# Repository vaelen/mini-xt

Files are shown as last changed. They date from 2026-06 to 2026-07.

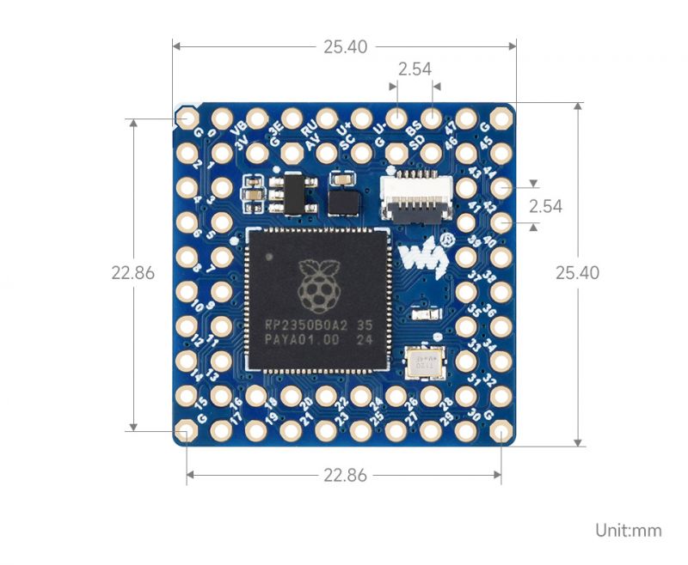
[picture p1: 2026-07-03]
hardware/Core2350B0-details-size.jpg

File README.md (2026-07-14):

# mini-xt

A from-scratch, IBM XT-compatible single-board computer, built as a set of small
PCBs around a real **NEC V20** CPU with modern **Raspberry Pi RP2350B / RP2040**
microcontrollers standing in for the out-of-production Intel 8000-series support
chips. After the substitutions, the only irreplaceable vintage silicon left on
the board is the V20 itself.

## The idea

The buffered **8-bit XT/ISA bus is the integration contract**. The V20 plus
minimal 74HCT glue creates a real XT bus; every other function hangs off it
either as a real chip (16C550 UARTs, XT-IDE + CompactFlash) or as
an MCU **"soft card"** that talks the bus exactly as a period ISA card would.
Since the 3.3V single-board redesign the internal bus is 3.3V end-to-end, so a
soft card's MCU sits on it directly (no per-card level shifters); real 5V ISA
cards attach only through the buffered expansion port. Soft cards may use *only*
signals that exist on the ISA bus, which keeps each one independently
developable and liftable onto a standalone ISA card unchanged.

The "motherboard" itself is a **two-MCU chipset** split by timing domain:

| Node | Part | Role |
|---|---|---|
| Bus MCU ("fast hands")  | RP2350B | Soft PIC/PIT/KBC/DMA/NMI/POST; bus slave *and* bus master |
| Supervisor ("slow brain")| RP2040 | USB HID host, setup UI, config, BIOS image storage, console |
| Video | RP2350B | Soft CGA/MDA/Hercules, snoop-and-mirror → VGA + HDMI |
| Audio | RP2040  | On-board PicoGUS (stock firmware): AdLib/SB/GUS/MPU + joystick |

There is no BIOS ROM: the Bus MCU shadow-loads the BIOS (Xi 8088, forked) into
SRAM at boot from images the Supervisor holds in flash, then releases the V20's
reset. RAM is one IS62WV51216BLL SRAM (512K×16, wired 1M×8 via the byte-lane
trick: 1 MB conventional + UMB less the video window); video RAM lives inside
the video MCU.

## Repository layout

| Path | Contents |
|---|---|
| `docs/xt-mcu-sbc-design.md` | **The main design doc** — the MCU-hybrid build implemented here |
| `docs/xt-hardware-design.md` | Companion design: the same machine from period chips (82Cxx, MC6845, CPLD) |
| `docs/early-pc-cpus.md` | Background: 8080→Z80→8086/8088→V20→286→386 lineage |
| `docs/memory-management.md` | Background: segmentation, the 640 KB barrier, EMS/XMS |
| `docs/pc-generations.md` | Background: XT→AT→386 board evolution; why XT-class is the target |
| `hardware/` | KiCad 9 schematics (generated — see below) + `README.md` |
| `hardware/sheets/*.py` | Declarative per-sheet schematic builders (the real sources) |
| `hardware/tools/` | The Python schematic generator (`mxsch.py`), signal contract (`mxbus.py`), build harness |
| `hardware/notes/` | Design decisions + open questions logged during generation |

## The schematics

The `.kicad_sch` files are **generated** by a small purpose-built Python
generator from the builders in `hardware/sheets/` — edit the `.py` files, not
the KiCad files. They are interface-focused: real component symbols, every
inter-module signal exposed as a hierarchical pin, key supporting parts and
decoupling — optimized for seeing module boundaries and how cleanly the
subsystems isolate, not (yet) for a finished PCB.

```sh
kicad hardware/mini-xt.kicad_pro          # browse: root sheet = the ISA backplane
python3 hardware/tools/build.py           # regenerate all sheets + root, run ERC + netlist
```

All peripherals live on the motherboard — one isolated sheet each,
jumper-configured like real cards (enable, base address, IRQ), so any of them
can still be lifted onto a separate PCB later by re-adding a small wrapper
(decode + IRQ driver + the expansion header).
External cards attach through the buffered **expansion port** (`sidecar`
sheet): a 50-pin (2×25) header carrying a project-private 8-bit ISA subset —
50-way IDC ribbons are far easier to source than the 60-way header it replaced.
The long-term plan is an **ISA backplane expansion board** on that port, with
real card-edge slots, that locally re-creates the few signals the 50-pin
header drops (OSC, REFRESH#) for any period card that needs them. (The interim
standalone dev cards — `card_video` and the `card_isatest` jig — were deleted
2026-07-14 in favor of that plan; git history has their last versions.)

See `hardware/README.md` for the sheet list and
`hardware/tools/SHEET_AUTHORING_GUIDE.md` for how to author a sheet.

## The on-board peripherals

The **motherboard** (V20 + SRAM + the two-MCU chipset + power/audio, the
`hardware/sheets/` hierarchy) is the one node allowed private side-channels,
since it *is* the machine the cards plug into. Its on-board peripherals keep
the soft-card discipline (own sheet, ISA signals + power only) and are
jumper-configured like the period cards they replace:

- **Video** — soft CGA/MDA/Hercules on an RP2350B (Core2350B module, 8 MB
  PSRAM variant for the future VGA aperture). Snoop-and-mirror design: it
  owns its video RAM, captures bus writes to `0xA0000–0xBFFFF` and the
  CRTC/mode ports at 0 wait through a PIO FIFO, and serves the (rare) reads
  itself, wait-stated via IOCHRDY — so there is no shared-framebuffer
  arbitration and no CGA snow. Renders once to internal RAM, outputs VGA
  (resistor-ladder DAC) or HDMI (RP2350 HSTX, no transmitter chip); graphics
  scope (CGA → mode 13h → planar VGA) is purely a firmware milestone.
  Boot-read straps stand in for a period card's switches: DIS_VID (addr_decode
  JP5) high = disabled — firmware keeps every bus-facing OE off; JP1 picks the
  default window set, closed = CGA (0x3D4/0xB8000), open = MDA/Hercules
  (0x3B4/0xB0000).
- **COM1/COM2** — one `com_port` sheet instanced twice: 16C550 (SMD PLCC-44
  socket taking new TI silicon or period NS16550AFN pulls) + MAX3241 for a
  full DB9 DTE, 1.8432 MHz crystal baud reference. Per port: J2 base address
  (0x3F8/0x2F8), IRQ hardwired (COM1=IRQ4, COM2=IRQ3), JP3 enable (open parks
  the 16550's CS1 — the port simply never decodes, freeing its IRQ), JP1 RX
  source (DB9 vs 5 V TTL console header, COM1).
- **LPT** — period-correct SPP at JP1-strapped 0x378/0x278 in discrete 74HCT
  ('574 latches, '244 buffers, AND-tree decode); Busy inverted on-card into
  status bit 7, IRQ7 hardwired (tri-state driver, silent until enabled), JP2
  enable gates the register-select '138 (open also frees IRQ7). DB25 out.
- **RTC** — emulated in the Bus MCU (like the PIC/PIT/KBC) at the
  PC-standard 0x70/0x71, NMI mask on 0x70 bit 7. The RTC periodic/alarm IRQ8 is
  emulated in the **soft-PIC** (fired in firmware) — the physical ISA IRQ8 line
  is undriven/reserved, not hardwired. Battery-backed timekeeping comes from a
  **PCF8563 I2C RTC + CR2032** on the Supervisor, synced to the Bus MCU over the
  existing UART link at boot.
- **PicoGUS** — a faithful on-board copy of polpo's PicoGUS 2.0 "chip-down"
  design (CERN-OHL-P): a bare RP2040 running **stock PicoGUS firmware**
  (AdLib/SB/GUS/MPU-401/CMS/Tandy), with the reference's ADS-muxed shared
  AD bus through CB3T FET switches, BUSOE power-up latch, APS6404L sample
  PSRAM, PCM5102A I²S DAC, and DMA hardwired to **channel 1** (the only
  channel the chipset services — the reference's DMA jumper block is
  omitted). The IRQ is hardwired to
  **IRQ5** — the free line, sole driver — with pgusinit setting the
  firmware to match. Deviations, all logged: no gameport (USB HID
  instead), no wavetable header or MIDI-out jack (build simplification —
  the volume chip and mix node went with them; the firmware's volume/MIDI
  GPIOs are documented no-connects), audio feeds the board's one line-out
  jack via the summer, and programming arrives over the Supervisor's shared
  USB-C port (SW2 selector) instead of a local connector.
- **Storage** — a true XT-IDE rev 2 ("Chuck-mod"): the A0↔A3 address-line
  swap puts the data register at 0x300 and the '573 high-byte latch at
  0x301, exactly the layout XTIDE Universal BIOS's "XT-IDE rev 2" type
  boots fastest; the latch pair turns the 16-bit IDE data register into
  two 8-bit transfers. A 40-pin IDE header and a CompactFlash socket
  (True-IDE) hang off the same bus. Straps: JP1 base 0x300/0x320, JP2
  enable (lifts the decode '138 — every select, latch clock and buffer
  goes inert). The IRQ is hardwired to **IRQ14** (AT primary-IDE
  convention, collected on the Bus MCU's '165 D7; motherboard-internal
  line) — poll vs interrupt is an XTIDE UB config choice, and the
  tri-state driver is silent unless the drive asserts INTRQ. No boot ROM
  on the interface: the Bus MCU shadow-loads XTIDE Universal BIOS into
  SRAM at boot.
- **Network** — none on board. The RTL8019AS NE2000 NIC (an ISA8019
  transcription) was removed on 2026-07-14; git tag `full-board-with-nic`
  preserves the complete design. A real NE2000 card on the buffered
  expansion port fills the role if networking is ever needed (its IRQ2
  arrives as EXT_IRQ2 and redirects to IRQ9 in the soft PIC).

Disabling an on-board port (or re-strapping its address/IRQ) frees the slot
for the same peripheral on the expansion port — the drivers are tri-state, so
an on-board port and a card can coexist as long as they don't claim the same
address or IRQ: run the on-board XT-IDE at 0x300 beside a real 8-bit ISA IDE
card at 0x320, or on-board video as CGA beside an MDA card.

## Fabrication

The board is fabricated and assembled at **JLCPCB**: SMD construction (the
merged single-board motherboard is above the ≤100 × 100 mm tier),
with through-hole only for
connectors/headers and for the fab-installed **sockets** that carry the
irreplaceable parts (the V20 and the MCU modules — the SRAM and RTC are now
SMD, no longer socketed). Every schematic component carries an `LCSC Part Num` property —
generated from the sourcing map in `hardware/tools/parts.py` — so the BOM
export drives JLCPCB assembly directly. Sourcing decisions, verified pinouts,
and stock-forced substitutions are logged in
`hardware/notes/jlcpcb-sourcing.md`.

## Status

Schematic capture / architecture-validation stage. Firmware (Bus MCU chipset
emulation, video, Supervisor) and PCB layout have not been started. Open items
are tracked in `hardware/notes/open-questions.md` and
`docs/xt-mcu-sbc-design.md` §16.

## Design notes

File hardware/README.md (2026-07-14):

# mini-xt — KiCad schematics

Hierarchical KiCad 9 schematics for the XT-class MCU-SBC described in
`../docs/xt-mcu-sbc-design.md`. Interface-focused: real component symbols, every
inter-module signal exposed as a hierarchical pin, key supporting parts and
decoupling — optimized for seeing the module boundaries and how cleanly the
subsystems isolate, not for a finished PCB.

## Open it

```
kicad mini-xt.kicad_pro      # then open mini-xt.kicad_sch (the root sheet)
```

The root sheet is the buffered ISA backplane; double-click any sheet symbol to
descend into a subsystem.

## Layout

| File | Subsystem |
|---|---|
| `mini-xt.kicad_sch` | root — 3.3V ISA backplane + sheet instances + power |
| `sheets/cpu_core` | V20 CPU, SRAM, clock tree, reset, the board's one 5V↔3.3V boundary |
| `sheets/bus_mcu` | Bus-master RP2350B: soft chipset (incl. RTC ports 0x70/71) + addr counter + IRQ collector, GPIOs direct on the 3.3V bus (no local level shifters) |
| `sheets/supervisor` | RP2040: USB host, setup UI, POST, console, link, battery-backed PCF8563 RTC |
| `sheets/video` | RP2350B soft CGA/MDA/Herc → HDMI + VGA; 4× 74LVC245A PIO time-share mux |
| `sheets/com_port` | 2× TL16C550CPFBR + MAX3241 + DB9 (COM1+COM2) |
| `sheets/addr_decode` | central I/O decode + IRQ mapping + the 2×5 disable-jumper block JP1 (bases hardwired) |
| `sheets/parallel` | discrete 74HC/74LVC LPT @ 0x378 + DB25 |
| `sheets/power` | USB-C 5 V in → 3.3 V buck |
| `sheets/storage` | XT-IDE (Chuck-mod) + CompactFlash |
| `sheets/audio` | PC-speaker + op-amp summer → line-out |
| `sheets/sidecar` | buffered 5V-compatible ISA expansion port: 50-pin (2×25) header + ~7-package isolation bank, incl. one DMA channel (EXT_DRQ / EXT_DACK̄) |
| `sheets/picogus` | PicoGUS chip-down copy: RP2040 AdLib/SB/GUS/MPU  |
| `mini-xt.kicad_sym` | custom symbols (V20, MAX3241, IS62WV51216, TL16C550PT, PCF8563, flat 74xx)|

There is no `sheets/rtc` any more — the RTC is emulated in the Bus MCU
(ports 0x70/0x71) with battery-backed timekeeping on the Supervisor
(PCF8563 + CR2032); see `notes/open-questions.md`'s 2026-07-14 entry.
There is no `sheets/network` any more either — the RTL8019AS NE2000 NIC was
removed 2026-07-14 (git tag `full-board-with-nic` has the last design that
carried it); a real NE2000 card on the expansion port fills the role.
The standalone dev cards (`sheets/card_video`, `sheets/card_isatest`) and
`hardware/cards/` were deleted 2026-07-14 too — the long-term plan is an ISA
backplane expansion board on the sidecar port; git history has their last
versions.

## How these were generated

The `.kicad_sch` files are emitted by a small Python generator in `tools/`
(`mxsch.py`) from declarative per-sheet builders (`sheets/*.py`). To regenerate:

```
python3 tools/build.py                       # writes all sheets + root, runs ERC + netlist
python3 tools/validate_sheet.py <name>       # ERC one sheet in isolation
python3 tools/pins.py <Lib:Name>             # introspect a symbol's pins
```

To author or change a sheet, edit `sheets/<name>.py` and re-run `build.py`.
See `tools/SHEET_AUTHORING_GUIDE.md`.

## Fabrication (JLCPCB)

Every component carries an `LCSC Part Num` property, generated at build time
from the sourcing map in `tools/parts.py` (SMD parts; the motherboard is one
>100×100 mm board since the 2026-07-14 3.3V single-board redesign;
fab-installed sockets are down to the V20 + the Core2350B/Pico module
headers). The sheets
stay generic; the parts map is the single place where generic symbols bind to
purchasable parts. Decisions, verified pinouts, and stock-forced
substitutions: `notes/jlcpcb-sourcing.md`.

## Notes / decisions

`notes/open-questions.md` records the decisions made during generation and the
items to review; `notes/questions-<sheet>.md` hold per-sheet specifics.

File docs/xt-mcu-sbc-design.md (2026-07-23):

# XT-Class SBC — MCU-Hybrid Design Notes

An **alternate** design for a DOS-compatible, XT-class single-board computer built
around the **NEC V20**, that deliberately **replaces the out-of-production Intel
8000-series support chips with modern microcontrollers** (Raspberry Pi RP2350B /
RP2040) and an on-board **PicoGUS**, while keeping the parts already on hand real.

Where the companion `xt-hardware-design.md` is "distinct period chips, education over
emulation," **this design optimizes for buildability with available parts**: the goal is
to need *as few out-of-production ICs as possible*. After this exercise, **the only
irreplaceable vintage silicon left is the V20 itself.**

See companion docs: `xt-hardware-design.md` (the period-chip build), `early-pc-cpus.md`,
`memory-management.md`, `pc-generations.md`.

Design date: 2026-06-28.

**2026-07-14 update — 3.3V single-board redesign.** The board collapsed onto
**one PCB with a 3.3V internal bus** (was: multiple 5V-bus boards/sidecar
modules). The V20's own address-latch/data-transceiver stage, re-specified as
74LVC parts, *is* now the board's single 5V↔3.3V boundary; a second,
isolation-only buffer bank sits at the external expansion port. Sections below
are updated in place where the redesign changed them (RAM, RTC, COM UART,
voltage architecture, block diagram, §4). Full rationale, decision log, and
verification: `docs/superpowers/specs/2026-07-14-3v3-single-board-design.md`
and `hardware/notes/3v3-verification.md`.

---

## 1. Design summary / decisions locked

| Area | Decision |
|---|---|
| CPU | NEC **V20** (µPD70108, **9 MHz grade**) in **min mode** (no 8087 → no 8288, no 8284) |
| Clock | **Single 14.31818 MHz oscillator** (3.3V part); ÷2 = 7.16 MHz (74LVC74A), ÷3 = 4.77 MHz (74LVC161 preset-to-3) — LVC-grade for 3.3V fmax margin |
| CPU speed | **7.16 MHz** default, **4.77 MHz** turbo-down (selected in the boot menu, CPU held in reset) |
| Reset / power-good | Supervisor (TCM809, 3.3V) cold-start; **Bus MCU sequences reset** |
| Board | **One PCB** (>100×100 mm JLC tier) — the old per-subsystem boards / inter-board 60-pin daisy-chain headers are gone; sheets remain separate *schematic* sheets only |
| RAM | **One IS62WV51216BLL-55TLI** (512K×16, 3.3V, TSOP-II-44) wired **1M×8 via the byte-lane trick** (1 MB conventional+UMB less the video window); video RAM lives in the video MCU |
| ROM / BIOS | **None on board** — BIOS **shadow-loaded into SRAM** by the Bus MCU at boot |
| Bus | **3.3V internal** buffered 8-bit XT/ISA backplane; a **50-pin (2×25) buffered expansion port** (isolation/level-shift bank, `sidecar` sheet) presents a 5V-compatible 8-bit ISA subset header (project-private pinout since 2026-07-14) for real cards |
| Support chipset | **Two-MCU split**: **Bus MCU (RP2350B)** soft-emulates PIC (×2, 15 IRQ), PIT, KBC, **functional DMA**, NMI, POST, and RTC ports 0x70/71, as bus master/slave, GPIOs tied **directly** to the 3.3V bus (no local transceivers); **Supervisor (RP2040)** runs USB/config/storage off-bus plus the battery-backed RTC (§5) |
| Chipset link | **2-wire full-duplex UART** between Bus MCU ↔ Supervisor (boot image push + HID/menu/POST/RTC-sync events) |
| Video | **RP2350B** soft CGA/MDA/Hercules (snoop-and-mirror), **VGA + HDMI** out (config-selected); 4× 74LVC245A kept as a PIO-driven time-share address/data mux (GPIO budget), not level shifters on this 3.3V board |
| Audio | **On-board PicoGUS (bare RP2040 "chip-down" copy, stock firmware)** — AdLib/SB/GUS/MPU/etc.; no gameport (USB HID instead) |
| Network | **None on board** (the RTL8019AS NE2000 NIC was removed 2026-07-14 — git tag `full-board-with-nic` has the last full design); a real NE2000 card can plug into the buffered expansion port |
| Input | **USB-A HID host** on the **Supervisor** MCU (keyboard; mouse via user's hub) |
| Mouse | Emulated **virtual COM3 serial mouse** (default) or **PS/2 on IRQ12** (option) |
| Storage | Discrete **XT-IDE** (8-bit, Chuck-mod) + CompactFlash; XTIDE Universal BIOS. Floppy = **all-firmware emulation** (§10.1, no FDC hardware) |
| Serial | **2× TL16C550CPFBR** (TQFP-48, soldered, 3.3V — thin JLC stock, C882798) + **MAX3241** (full DB9); TTL console header on COM1 |
| Parallel | Discrete **74HC/74LVC** LPT @ 0x378 (jumpers: 0x278 alt, enable; IRQ7 hardwired) |
| RTC | **Emulated in the Bus MCU** (ports 0x70/0x71, like PIC/PIT); battery-backed timekeeping via a **PCF8563 I2C RTC + CR2032 coin cell on the Supervisor**, synced over the UART link at boot |
| Config | **Pre-BIOS setup menu** (Supervisor MCU), shown on **video + MCU console**, entered by keypress |
| BIOS | **Xi 8088** (Sergey Kiselev), expected to be **forked** for our chipset |
| Debug | **2-digit hex POST display** (port 0x80), MCU console, logic-analyzer header |
| Power | Single **5 V in** (USB-C) → on-board **3.3 V buck** carrying nearly the whole board; no ±12 V. 5V presences that remain: V20; cpu_core U10 (74HCT32 strobe combiner); cpu_core U13 (74HCT04 — V20 CLK + READY/HOLD buffers); the fused +5V_ISA port feed; the audio MCP6002 (analog). MAX3241s are 3.3V |

**MCU count: 2× RP2350B** (Bus MCU, video) **+ 2× RP2040** (Supervisor, PicoGUS).
The chipset is deliberately split across two MCUs (§5) for clean separation: the **Bus MCU**
owns all hard-real-time bus work, the **Supervisor** owns the USB stack, setup UI, and
BIOS-image storage off-bus. The two *we* develop on RP2350B (Bus MCU) and RP2040 (Supervisor)
are independent; PicoGUS stays stock.

---

## 2. Philosophy & architecture

The organizing idea: **the buffered 8-bit XT/ISA bus is the integration contract.**
The V20 plus minimal glue creates a real XT bus on the board; every function then
hangs off it either as a **real chip** (what we already have) or as an **MCU "soft card"**
that talks the bus exactly as a period ISA card would. This makes each subsystem
independently developable, testable, and (for the video and sound cards) **liftable
onto a standalone ISA card later.**

**2026-07-14 update:** the whole internal bus is now 3.3V, so soft cards on the
motherboard tie their MCU GPIOs to it **directly** — no local level shifters —
except the video card's GPIO-budget mux (below). Local shifters remain load-bearing only at
the buffered expansion port (§4.3) and on any card that plugs into it as a real
5V ISA card.

Three classes of node:

1. **The "motherboard" — a two-MCU chipset** (the one special, non-card node). It turns the
   V20 into an XT and is split by timing domain (§5):
   - **Bus MCU (RP2350B) — "fast hands."** All hard-real-time bus work: PIC, PIT, KBC, DMA,
     NMI, POST, RTC ports 0x70/71, the shadow-load engine. A bus *slave* (answers I/O)
     **and** a bus *master* (boot shadow-load, sound DMA, pre-BIOS menu rendering). No
     local transceivers — its GPIOs sit on the 3.3V bus directly and tri-state natively
     for role changes. Touches only the bus, its glue (address counter, IRQ shift
     register), and the link to the Supervisor.
   - **Supervisor (RP2040) — "slow brain."** Off the system bus entirely: USB HID host, setup
     UI, persistent config, BIOS/option-ROM image storage, console, POST display, and the
     battery-backed PCF8563 RTC (synced to the Bus MCU's emulation over the link at boot).
     Talks to the Bus MCU only over a **2-wire full-duplex UART** (§5.3).
2. **Soft cards** — the **video** card (RP2350B) and **PicoGUS** (RP2040). Pure ISA
   peripherals on the bus, GPIOs tied directly to the 3.3V bus (video keeps a 4×
   74LVC245A PIO-driven time-share mux for GPIO budget, not for level shifting).
3. **Real period-style chips** — V20, one IS62WV51216BLL SRAM, 2× TL16C550CPFBR UART,
   plus discrete 74HC/74HCT/74LVC glue for the bus, LPT, and XT-IDE.

**Portability guideline** (downgraded 2026-07-14 from a hard schematic rule — decision
#8 of the 3.3V redesign). A **soft card** (class 2) is still meant to use **only
signals that exist on the ISA bus** — self-decoding its own address ranges, coordinating
solely through standard lines (`MEMR̄/MEMW̄/IOR̄/IOW̄`, `BALE`, `AEN`, `IOCHRDY`, `IRQ`,
`DRQ/DACK/TC`, `CLK`, `RESET`), no dependence on host memory — because that is what keeps
it liftable to a standalone ISA board. But with the whole board now one 3.3V bus, this is
firmware/architectural discipline rather than an electrically-enforced boundary, so it is
a **guideline**, not a binding constraint (`mxbus`'s `PRIV_*` split loosened accordingly).
The **class-1 motherboard MCUs remain explicitly exempt** — they *are* the motherboard: the
Bus MCU bus-masters via `HOLD/HLDA`, sequences reset, and owns motherboard-only signals
(the SRAM-decode Y5 strobe, the speed-select latch, the external address counter), and the
Supervisor never sits on the bus at all. Class-3 parts are fixed motherboard hardware and
out of scope for the rule.

**Central I/O decode + IRQ map (2026-07-14).** The discrete peripherals no longer carry
their own bus-interface plumbing. One **`addr_decode` sheet** (74HC138 windowing on A6-A8
with A9/AEN enables, a 74HC00 building the shared A3·A4·A5 fine term, two 74HC32 ranks)
hands **~COM1_CS / ~COM2_CS / ~LPT_CS / ~IDE_CS** (`mxbus.PRIV_CS`) to the COM/LPT/XT-IDE
sheets, and its shared **74LVC125A** drives the real IRQ lines (COM1→IRQ4, COM2→IRQ3,
LPT→IRQ7, IDE→IRQ14) from the peripherals' private requests (`mxbus.PRIV_IRQREQ`; the COM
channels stay ~OUT2-gated per the PC convention). Base addresses are **hardwired** (LPT 0x378, IDE
0x300 — the straps went the way of COM's, 2026-07-14 later the same day). All five
per-peripheral **disable jumpers JP1–JP5** (COM1, COM2, LPT, IDE, VID — enabled by
default; fit a jumper to disable) live here: COM/LPT/IDE gate their chip selects through
a second '32 rank, while **DIS_VID** (`mxbus.PRIV_DIS`) is just the jumper
level routed to gating that must stay local (the video MCU's firmware boot strap,
polarity inverted vs the old VID_EN). These private nets are
shared logic factored out, not an isolation break: each is functionally equivalent to
the gate chips it replaced, and a block broken out to a standalone card gets decode + IRQ
driver back in its wrapper schematic exactly as it gets the bus edge connector
(`questions-addr_decode.md`). Video/PicoGUS/Bus-MCU decode in firmware; only their
disable jumpers moved here.

**Decode chart.** Net-by-net logic of the `addr_decode` chain (U1 '138 windows → U2 '00
fine term → U3/U4 '32 OR ranks). All nets are active-low; each row shows the A0–A9 state
that asserts the net (X = don't care). Every row also requires **AEN = 0** (the '138's
~E0 — decode is suppressed during DMA cycles), and the final `~x_CS` rows additionally
require the peripheral's **DIS_x jumper level = 0** (enabled, the default).

| Net Name  | Logic | A0 | A1 | A2 | A3 | A4 | A5 | A6 | A7 | A8 | A9 |
|---|---|----|----|----|----|----|----|----|----|----|----|
| WIN_COM1  | NOT(AND(A6, A7, A8, A9, NOT(AEN))) | X  | X  | X  | X  | X  | X  | 1  | 1  | 1  | 1  |
| WIN_COM2  | NOT(AND(A6, A7, NOT(A8), A9, NOT(AEN))) | X  | X  | X  | X  | X  | X  | 1  | 1  | 0  | 1  |
| WIN_LPT | NOT(AND(A6, NOT(A7), A8, A9, NOT(AEN))) | X  | X  | X  | X  | X  | X  | 1  | 0  | 1  | 1  |
| WIN_IDE | NOT(AND(NOT(A6), NOT(A7), A8, A9, NOT(AEN))) | X  | X  | X  | X  | X  | X  | 0  | 0  | 1  | 1  |
| Q_N | NAND(A3, A4, A5) | X  | X  | X  | 1  | 1  | 1  | X  | X  | X  | X  |
| CSP_COM1  | OR(WIN_COM1, Q_N) | X  | X  | X  | 1  | 1  | 1  | 1  | 1  | 1  | 1  |
| CSP_COM2  | OR(WIN_COM2, Q_N) | X  | X  | X  | 1  | 1  | 1  | 1  | 1  | 0  | 1  |
| CSP_LPT | OR(WIN_LPT, Q_N) | X  | X  | X  | 1  | 1  | 1  | 1  | 0  | 1  | 1  |
| CSP_IDE | OR(WIN_IDE, A5) | X  | X  | X  | X  | X  | 0  | 0  | 0  | 1  | 1  |
| ~COM1_CS  | OR(CSP_COM1, DIS_COM1) | X  | X  | X  | 1  | 1  | 1  | 1  | 1  | 1  | 1  |
| ~COM2_CS  | OR(CSP_COM2, DIS_COM2) | X  | X  | X  | 1  | 1  | 1  | 1  | 1  | 0  | 1  |
| ~LPT_CS | OR(CSP_LPT, DIS_LPT) | X  | X  | X  | 1  | 1  | 1  | 1  | 0  | 1  | 1  |
| ~IDE_CS | OR(CSP_IDE, DIS_IDE) | X  | X  | X  | X  | X  | 0  | 0  | 0  | 1  | 1  |

Resulting ranges: ~COM1_CS = 0x3F8–0x3FF, ~COM2_CS = 0x2F8–0x2FF, ~LPT_CS = 0x378–0x37F,
~IDE_CS = 0x300–0x31F. A0–A2 are never decoded here — they reach the peripherals for
internal register select (and the IDE window's A3/A4 don't-cares split further on the
storage sheet).

### Block diagram

```
        14.31818 MHz osc ──┬─ ÷2 (74LVC74A) → 7.16 MHz ─┐         (3.3V clock tree;
                           │                            ├─ 74HC157 sel ─ 5V buf ─► V20 CLK
                           ├─ ÷3 (74LVC161) → 4.77 MHz ─┘   ▲ (MCU speed GPIO, boot only)
                           └──────────────────────────────────────────────► ISA OSC pin (B30)
                                                     (74HCT04 = the ONLY other 5V package)

   ┌─────────┐  RD/WR/IO-M, ALE, HOLD/HLDA
   │   V20   │  (min mode, 5V — the board's one vintage/5V chip)
   │ 8088-cmp│
   └─────┬───┘
   AD bus│ multiplexed
   ┌─────┴────────────┐  <- the board's ONE 5V<->3.3V boundary
   │ 74LVC573A×3 latch│ → A0–A19 ┐
   │ 74LVC245A xceiver│ ↔ D0–D7  │   buffered 3.3V internal XT/ISA bus
   └──────────────────┘          │   (+ MEMR/W, IOR/W, ALE, AEN, CLK, OSC, RESET,
         ┌───────────────────────┴────IOCHRDY, IOCHCK, IRQ, DRQ/DACK, +3V3, GND)
         │
  ┌──────┼────────┬────────────────┬────────────────┬───────────┬───────────────┐
      ┌──┴──┐ ┌───┴──────────┐ ┌───┴──────────┐ ┌───┴────┐ ┌────┴────────┐ ┌────┴──────┐
      │SRAM │ │   BUS MCU    │ │  VIDEO MCU   │ │PicoGUS │ │ 2×TL16C550  │ │port bank  │
      │1M×8 │ │   RP2350B    │ │   RP2350B    │ │RP2040  │ │CPT+MAX3241  │ │ (~9 LVC   │
      │IS62 │ │ GPIOs DIRECT │ │ 4x LVC245A   │ │ stock  │ │  COM1/2     │ │245/244/   │
      │WV.. │ │ on 3.3V bus  │ │ PIO mux      │ │ AdLib/ │ └─────────────┘ │2G07 pkgs) │
      └─────┘ │ (no local    │ │  (GPIO       │ │SB/GUS  │ ┌───────────┐   │ isolates  │
         ▲    │ xceivers)    │ │  budget, NOT │ │chip-dwn│ │  XT-IDE   │   │ 5V ISA    │
         │    └───┬───────┬──┘ │  level-shift)│ └───┬────┘ │  + CF     │   │ header    │
   74HC138        │       │ ▲  └──────────────┘     │I2S   └───────────┘   │ (50p 2x25)│
   +NAND          │ glue: │ │UART link            PCM5102A ┌──────────┐    └───────────┘
   (SRAM /CE)     │5×'163 │ │(2-wire,             audio    │ disc. LPT│
                  │counter│ │full-duplex)     PC-spkr ─┐   │ @0x378   │
                  │ '165  │ │  RTC sync   op-amp ──────┴─► └──────────┘
                  │IRQ-in │ ▼              summer → line-out
                  │   ┌───┴────────────┐
                  │   │  SUPERVISOR    │  USB-A host (kbd/mouse hub)
                  │   │    RP2040      │  setup UI · config (flash)
                  │   │  off the bus   │  BIOS/opt-ROM images (flash)
                  │   │  PCF8563 RTC   │  console UART · POST display
                  │   │  + CR2032      │  (Bus MCU emulates ports 0x70/71,
                  │   └────────────────┘   synced from here over the link)
   2-digit hex POST @0x80 (Supervisor-driven) · one 5V→3.3V buck carries nearly the whole board
```

---

## 3. CPU, min mode, and clock

### 3.1 V20 in min mode
The part on hand is a **9 MHz-grade µPD70108**, comfortably above the 7.16 MHz default
(a 5 MHz part would not qualify). `MN/MX̄` strapped high. The V20 directly drives `RD̄`, `WR̄`, `IO/M̄`, `ALE`, `DEN̄`,
`DT/R̄`, `INTĀ`, and crucially **`HOLD`/`HLDA`** — the clean bus-grant handshake the
Bus MCU uses for all bus-master work. Min mode means **no 8288** (the CPU makes its
own control signals) and **no 8087** (dropped; software FP emulation if ever needed), and
since the clock no longer comes from an 8284, **no 8284 either**. Three vintage chips gone.

### 3.2 Single-oscillator clock tree
One **14.31818 MHz** canned oscillator does everything. **2026-07-14 update:** the
whole tree now runs at 3.3V (canned 14.318 MHz oscillators are only stocked as
3.3V parts at JLC) — plan-stage verification (`hardware/notes/3v3-verification.md`
check 7) found plain HC-grade dividers fail their fmax margin at 3.3V (74HC74's
guaranteed fmax interpolates to ~14.8 MHz, 74HC161 to ~11.1 MHz — both too close
to or below the 14.318 MHz clock), so both dividers are **LVC-grade**:

- **÷2 (74LVC74A)** → **7.15909 MHz**, clean 50 % duty → default CPU/bus clock.
  (Spec'd 250 MHz — no margin question at 3.3V.)
- **÷3 (74LVC161 preset-to-3, same topology as a '163)** → **4.77273 MHz**, ~33 %
  duty (after the inverting 5V buffer stage below) → turbo-down. A single
  flip-flop can't ÷3; the preset-reload counter does it in one chip, and the
  33 % duty is within the V20's clock spec (it is exactly what the 8284 supplied
  the original 8088). Spec'd 150 MHz at 3.3V — comfortable margin, but JLC stock
  is thin (re-verify before ordering).
- A **74HC157** (one section, now 3.3V-powered) selects 7.16 vs 4.77; **its
  select line is a chipset-MCU GPIO**, driven directly (3.3V clears HC's Vih at
  3.3V, so the old 5V inverting-select stage is gone).
- **Speed is changed only in the MCU pre-BIOS boot menu**, while the V20 is held in reset —
  never live during execution. Because the mux select only ever moves while the CPU is in
  reset, the runt clock pulse a plain 74HC157 would produce on switching is harmless (no
  glitch-free PLD needed); the new divisor is settled before reset is released.
- The raw 14.318 also drives the **ISA OSC pin (B30)** for any real card on the port bank —
  re-buffered to 3.3V by a 74LVC125A (no 5V push-pull output may drive a shared bus net that
  reaches a non-5V-tolerant GPIO).

**CLK level note:** the V20 clock input wants a near-Vcc swing (datasheet-confirmed
Vkh min = 0.8×Vdd = **4.0 V**, check 1), so the mux output is buffered by a
**5 V-powered 74HCT04 package (U13)** to meet it. The same U13 package also
re-buffers the V20's **READY/HOLD** inputs (Task-10: their Vih ≈ 0.6×Vdd = 3.0 V
is barely met by a 3.3 V MCU drive — HOLD via one *inverting* gate, so firmware
drives HOLD active-low). All U13 outputs drive *only* private V20 nets, never a
shared bus line. (U13 and U10's 74HCT32 strobe combiner are this design's two
surviving 5 V logic packages.) This is also why the MCU cannot drive the CPU
clock directly (its 3.3 V pins won't meet Vkh). **RESET, by contrast, does NOT
need the 5V buffer** — the V20's
general-input Vih (2.2V) is well within reach of 3.3V logic (check 1), so RESET and
RESET_DRV are driven straight from 3.3V.

Because the **PIT is emulated in the Bus MCU**, the all-important **1.193182 MHz**
timer rate is synthesized internally and is *independent* of the CPU clock — none of the
old colorburst divider math is needed. The video MCU likewise makes its own pixel clocks.

### 3.3 Reset
A cold-start supervisor (**TCM809, now 3.3V-powered**) holds the board in reset until rails
are stable. Thereafter the **Bus MCU sequences the V20's reset**: it holds the V20 in reset
through its own boot, the pre-BIOS menu, and the BIOS shadow-load, then releases it.

---

## 4. The bus and the buffered expansion port

**2026-07-14 update:** the internal backplane is now **3.3V end to end**. The V20's own
address-latch/data-transceiver stage — re-specified as 74LVC parts — *is* the board's
single 5V↔3.3V boundary (§4.2); no other on-board node needs a level shifter. A second,
separate isolation/buffer bank sits only at the external **buffered expansion port**
(§4.3, `sidecar` sheet) to keep it 5V-real-card-compatible.

### 4.1 Buffered 3.3V internal XT/ISA backplane
- **74LVC573A ×3** latch A0–A19 (gated by raw ALE, `cpu_core` U2–U4); **74LVC245A** buffers
  D0–D7 (`cpu_core` U5). Both are 3.3V-powered with 5V-tolerant inputs, so they read the V20's
  5V AD bus directly and drive a clean 3.3V bus on the other side.
- **SRAM chip-select decode — a single 74HC138 + one 74HC00 package, no PLD.** With one SRAM
  chip (below) the old two-chip NAND-select scheme collapses: `cpu_core` U6 (74HC138, 3.3V
  input/output — every input is now 3.3V-driven, so plain HC, not HCT, is fine) still decodes
  the 128 KB blocks from latched **A17→A, A18→B, A19→C**, but only its **Y5** output
  (0xA0000–0xBFFFF = the video MCU window) is used; the SRAM's own `/CE` is simply
  **NOT(Y5)** — one inverter (a spare gate in `cpu_core` U7, a 74HC00) — so the SRAM answers
  the *entire* 1 MB address space except the video window. **Y5 is motherboard-internal**
  (it only feeds the SRAM `/CE` inverter). The video subsystem still **self-decodes** its
  0xA0000–0xBFFFF window from latched A17–A19, using no signal off the ISA bus, so it stays
  liftable to a standalone ISA board unchanged (§8).
  - SRAM `/OE = MEMR̄, /WE = MEMW̄` (direct — the read path's whole critical delay budget,
    verified against the -55 SRAM's 25 ns tDOE at 7.16 MHz with wide margin,
    `hardware/notes/3v3-verification.md` check 2).
  No I/O-cycle qualification is needed: during I/O cycles MEMR̄/MEMW̄ are inactive, so the
  SRAM data pins stay high-Z even with `/CE` asserted (no contention, no spurious write). The
  decode reads *latched* address, so it is identical under V20 or bus-master (MCU) ownership.
  (Total memory decode: **one 74HC138 + one inverter gate.**)
- In min mode the V20's `IO/M̄ + RD̄ + WR̄` are gated into `MEMR̄/MEMW̄/IOR̄/IOW̄` by a
  **74HCT32** (`cpu_core` U10) — this gate package stays on the 5V rail (it reads the raw 5V
  V20 strobes directly) but its outputs cross to the 3.3V bus only through a tri-state
  74LVC125A stage (U11, `~OE = HLDA`) — see §4.2.
- **Wait states:** each soft card pulls **IOCHRDY** to buy time on a read; the Bus MCU folds
  all IOCHRDY/ready signals back to the V20's READY input. The SRAM runs 0 wait at 7.16 MHz.

### 4.2 Level shifting — the boundary is now at the V20, not per-card
The old "every MCU is 3.3V on a 5V bus, so every soft card carries its own level shifters"
picture is gone. With the whole internal bus at 3.3V, **the only 5V↔3.3V boundary on the
board is the V20's own demux stage** (`cpu_core`):

- **Address:** 3× 74LVC573A latches (5V-tolerant D inputs from the V20's muxed AD bus,
  3.3V Q outputs onto A0–A19).
- **Data:** 1× 74LVC245A transceiver (5V-tolerant CPU-side, 3.3V bus-side), `DIR = DT/R̄`.
- **Strobes:** the 74HCT32 gates that combine `RD̄/WR̄ + IO/M̄` into `MEMR̄/MEMW̄/IOR̄/IOW̄`
  stay on +5V (they read the raw 5V V20 strobes), but reach the 3.3V bus only through a
  74LVC125A tri-state stage (`~OE = HLDA`, enabled only while the V20 owns the bus) — a 5V
  push-pull output must never drive a shared bus net that reaches a non-5V-tolerant GPIO
  (e.g. the port bank's RP2350B-adjacent side, or the expansion-port far side pre-buffer).
  Pull-ups park the gated strobes inactive across the ownership handoff gap.
- **BALE / CLK / OSC re-buffer (`cpu_core` U15, 74LVC125A):** these three bus copies were
  historically driven straight off 5V logic (raw ALE, the CLK/OSC buffer below); they are
  now re-buffered to a clean 3.3V swing before joining the shared bus, for the same
  5V-push-pull-can't-drive-a-3.3V-only-net reason.
- **CLK only** still needs a 5V driver: the V20's CLK input requires Vkh ≥ 0.8×Vdd = 4.0V
  (datasheet-verified, unreachable from 3.3V) — the board's **one remaining 5V logic
  package**, a 74HCT04 (`cpu_core` U13), whose *only* output is the private V20 CLK net (it
  never touches a shared bus line). RESET does **not** need this treatment (Vih = 2.2V,
  reachable from 3.3V directly).

Everywhere else on the board, an MCU's GPIOs (or a 3.3V-native chip's pins) sit on the bus
**directly** — no local transceiver:
- **Bus MCU:** its six former 74LVC245A transceivers and role-driven DIR logic are deleted;
  its RP2350B GPIOs tie 1:1 to the bus and tri-state natively for master/slave role changes
  (a firmware property now, not a hardware DIR pin). It keeps its external 20-bit address
  counter (§5.1) and its own 3× 74HC244 tri-state buffers (`cpu_core`-adjacent, `bus_mcu`
  U14–U16) so the counter's outputs don't fight the CPU-side '573 latches on A0–A19 during
  V20-owned cycles — those are tri-state control for the shared address bus, not level
  shifters, and they stay.
- **Video MCU:** keeps 4× 74LVC245A, but repurposed — the RP2350B doesn't have enough spare
  GPIO to dedicate one pin per bus signal, so these chips are a **PIO-driven time-share
  address/data mux**, not a voltage boundary (deleting them was never on the table; only the
  sheet's *pure* buffer packages were removed).
- **PicoGUS:** stays a stock RP2040 design; its former 3-package level-shift stage (address/
  data mux excepted — that one is functional, not a shifter, see `questions-picogus.md`) is
  gone now that the bus it sits on is already 3.3V.
- (The RTL8019AS NIC — formerly the one deliberate 5V-island exception, isolated behind
  its own gated 74LVC245 + 74HC138 — was **removed 2026-07-14**; git tag
  `full-board-with-nic` has the last design that carried it.)

### 4.3 The buffered expansion port (`sidecar` sheet)
The only other 5V↔3.3V crossing on the board is a dedicated **isolation/buffer bank**
between the 3.3V internal bus and a **50-pin (2×25) 2.54 mm external ISA header** — a
**project-private 8-bit ISA subset pinout** (2026-07-14; the old 60-pin header mirrored
the PicoGUS/standard edge layout, but 50-way IDC ribbons are far easier to source, and
the planned **ISA backplane expansion board** re-creates anything dropped for real
period cards). It would exist even on an all-3.3V board (isolation against
load/fault/contention from a plugged card); LVC parts make it 5V-card-compatible for free.

The bank is **~7 packages**, all 74LVC-class, 3.3V-powered with 5V-tolerant inputs:

| Group | Parts | Direction |
|---|---|---|
| A0–A19 + BALE/AEN/CLK (23 lines) | 3× 74LVC245A | out, DIR strapped permanently outbound |
| Command strobes (7 lines: MEMR̄/MEMW̄/IOR̄/IOW̄/RESET_DRV/TC + DACK̄ from `EXT_DACK̄`) | 1× 74LVC244A | out |
| D0–D7 | 1× 74LVC245A | bidir, `DIR = EXP_DDIR` (Bus MCU-owned, defaults outbound via a pull-up) |
| IRQ2–7 + DRQ (inbound, onto private `EXT_*` nets — see below) | 1× 74LVC244A | in |
| IOCHRDY / IOCHCK̄ (open-drain, wired-AND) | 1× dual 74LVC2G07 | bidir (open-drain) |

Header signals (50 = 47 signals + one +5 V + two GND):
- A0–A19, D0–D7; MEMR̄/MEMW̄/IOR̄/IOW̄, BALE, AEN; CLK (7.16 MHz), RESET DRV
- IOCHRDY, IOCHCK̄; IRQ2–7
- One DMA channel: **DRQ (pin 9) / DACK̄ (pin 13)**, TC — see below
- **Dropped vs. real ISA** (2026-07-14, to fit 50 pins): **OSC** (14.318 MHz — no
  on-board consumer; a real CGA card would want it for colorburst) and **REFRESH̄**
  (no DRAM-refresh support on the port; its Bus-MCU GPIO was reclaimed as `EXT_DACK̄`).
  The backplane board re-creates both locally for cards that need them.
- +5 V and grounds: the port feeds `+5V_ISA` through a **2 A polyfuse + SMBJ5.0A clamp**, so
  a faulted expansion trips its own fuse instead of dropping — or back-driving — the board
  rail.

**IRQ2–7 land on private `EXT_IRQ*` nets, not the internal IRQ nets** —
the buffer bank's inbound 74LVC244A drives dedicated `EXT_*` signals so a floating or
misbehaving external line can never contend with an internal driver. The Bus MCU **merges**
the `EXT_*` lines with their on-board sources at its '32 OR rank feeding the single '165
collector (2026-07-14 — was a firmware merge across a 3-chip 24-bit chain); there is no
separate hardware arbitration, and a card and an on-board peripheral must still not be
jumpered to the same line simultaneously. (IRQ8 was removed from the header on 2026-07-12,
before this redesign — the RTC's interrupt is now firmware-internal to the Bus MCU's PIC
emulation; `EXT_IRQ8` — and the internal IRQ6/IRQ8 nets, which likewise had no possible
driver — were formally retired on 2026-07-14 with the firmware bit map unchanged.)

**Two DMA channels exist, both running the soft-8237's ch1 timing** (2026-07-14, second
pass — the earlier same-day simplification had removed port DMA entirely):
- **Internal: `DRQ`/`DACK̄`** (renamed from DRQ1/DACK1̄ once ch2/3 were retired) —
  hardwired to the on-board PicoGUS (the DMA jumper is gone; ch3's last consumer went
  with it).
- **Expansion port: `EXT_DRQ`/`EXT_DACK̄`** — the header's DRQ pin buffers inward onto
  the private `EXT_DRQ` net (a '165 lane in the IRQ collector, costing no GPIO);
  `EXT_DACK̄` is driven from GPIO47 (freed by the REFRESH̄ retirement) out through the
  strobe '244 to the header's DACK̄ pin.

The two channels are **deliberately separate nets**: the PicoGUS acknowledge never
reaches the header, so a port card can't false-respond during on-board sound DMA
(and vice versa).

**Bus-master limitation, unchanged in spirit:** the port's outbound buffers have a
**fixed, firmware-chosen direction** (`EXP_DDIR` for data; the address/control banks are
permanently outbound). There is no request/grant arbitration to the port, so **an external
card that wants to drive the bus itself (be a bus master) is not supported** — the same
limitation the old sidecar design had, now stated explicitly against the new buffer bank.

(The standalone dev-card PCBs — `card_video` and the isatest jig — were **deleted
2026-07-14** along with `hardware/cards/`; the long-term plan is an **ISA backplane
expansion board** on this port instead. Git history holds their last versions.)
**COM ×2, LPT, and storage are motherboard-only** (§10/§11): each is still a soft-card
sheet (COM1+COM2 share one merged sheet since 2026-07-14), and its enable jumpers (plus
base-address straps on LPT/IDE) free the slot for an expansion-port replacement. (The RTC no longer has an on-board ISA sheet at all — it moved off-bus, §11.3.)

---

## 5. Chipset — a two-MCU split (Bus MCU + Supervisor)

The "motherboard" is **two MCUs split by timing domain**, not one. The single-chip version is
feasible but **pin-bound** on a 48-GPIO RP2350B (≈47/48 with glue), and welds the hard-real-
time bus engine to the USB stack, filesystem, and setup UI on the same die. Splitting by
*what must happen in a bus cycle* vs. *what's complex but not timing-critical* keeps each half
clean and independently developable:

- **Bus MCU (RP2350B) — "fast hands."** Sits on the system bus as slave **and** master.
- **Supervisor (RP2040) — "slow brain."** Off the bus entirely; reachable only via the §5.3
  UART link.

The split does **not** relieve the Bus MCU's pins (those are set by the bus role and can't
move off-bus) — its value is firmware isolation, freeing both Bus MCU cores for bus/DMA work,
and a comfortable home for USB/storage/config on the RP2040. The Bus MCU still leans on two
cheap solder-only helpers (no PLD): a **loadable address counter** for bus-master cycles
(§5.1) and a **74HC165 + 74HC32** to collect the IRQ inputs (internal ORed
with expansion-port `EXT_IRQ*`) onto 3 pins.

### 5.0 Function assignment

| Function | Node | Emulates | Ports / lines |
|---|---|---|---|
| Interrupt controller | **Bus** | **Dual 8259A, cascaded, AT-style 15 IRQ** | 0x20/21, 0xA0/A1; INT 08–0F / 70–77; IRQ2→9 redirect |
| Timer | **Bus** | **8254 PIT**, 1.193182 MHz synthesized internally | 0x40–0x43; ch0 tick, ch2 → PC speaker |
| Keyboard controller | **Bus** | **XT 8255** *or* **AT 8042** (software-selectable) | 0x60/0x61(/0x64) |
| Mouse (register side) | **Bus** | **virtual COM3 16550** *or* **8042 aux PS/2** | 0x3E8/IRQ4 *or* IRQ12 |
| DMA | **Bus** | **8237 — functional** (required by PicoGUS SB/GUS) | 0x00–0x0F, page regs |
| NMI mask | **Bus** | **port 0x70 bit 7** (AT-style — 0xA0 is the slave PIC) | 0x070 bit 7 |
| Refresh toggle | **Bus** | **port 0x61 bit 4** free-running toggle (~66 kHz) | 0x061 bit 4 |
| POST capture | **Bus** snoops 0x80 → forwards code over the link | |
| Speaker | **Bus** | PIT ch2 tone (PWM/PIO) → 1 pin → op-amp summer | |
| Boot/bus master | **Bus** | HOLD/HLDA: SRAM clear, shadow-load, pre-BIOS render | |
| **USB HID host** | **Super** | (TinyUSB) keyboard + mouse → HID events over the link | |
| **Setup UI + config** | **Super** | menu state machine; settings in its flash | |
| **Image storage** | **Super** | BIOS + option-ROM images in its QSPI flash; streamed at boot | |
| **Console** | **Super** | dedicated UART (3-pin TTL header) — bring-up + setup output | |
| **POST display** | **Super** | drives the 2-digit hex display from forwarded 0x80 codes | |

The Bus MCU runs the hard-real-time bus interface on **core0 + PIO** (PIO latches the
multiplexed address on ALE and drives the fast read/write responses, PicoGUS-style); **core1**
is now free for the DMA/PIC engine instead of USB. The Supervisor owns the USB host stack and
filesystem with no bus-timing constraints to respect.

**DMA is no longer vestigial.** Sound Blaster / GUS digital audio is DMA-driven: PicoGUS
asserts DRQ and expects a real 8237 to run the memory→I/O transfer cycles. So the **Bus MCU's**
8237 must actually become bus master on DRQ, drive the transfer via the §5.1 counter, and
handle terminal count. It reuses the boot bus-master engine.

### 5.1 Bus-master addressing — external loadable counter (saves ~16 GPIO)

Driving a full 20-bit address from GPIO during master cycles would cost **20 pins**, which
the budget can't spare. But every master cycle — DMA blocks and BIOS/option-ROM shadow-load
alike — walks **sequential** addresses, so the address is offloaded to an external
**loadable 20-bit binary counter** (cascaded 74HC163, ~5 of them). The counter's own
flip-flops *hold* the address and its own outputs *drive* A0–A19; the MCU only:

1. **Loads the start address once per block** — multiplexed over the **existing D0–D7** plus
   a couple of load strobes (no new wide bus), and
2. **Pulses one COUNT pin per byte** to advance.

Pin cost drops from **~20 → ~4** (load strobes + count clock, reusing the data bus). Two
payoffs fall out of this:

- **Shadow-load:** load counter ← image base; per byte the MCU drives D0–D7 + MEMW̄ and
  pulses COUNT. It never drives an address line.
- **DMA (mem→I/O):** the MCU drives **neither address nor data** — the counter supplies
  A0–A19, SRAM puts the byte on D0–D7 under MEMR̄, and PicoGUS takes it on IOW̄+DACK (it keys
  on DACK, not address). The MCU only sequences the strobes and pulses COUNT — exactly the
  classic 8237 + page-latch behaviour.

*(A decoder is the wrong tool here — it is stateless one-hot translation, used for
chip-select in §4.1, and can neither hold nor sequence a 20-bit value. A plain 74HC573 latch
bank loaded over D0–D7 would also cut pins to ~3 but forces a full 3-byte reload every byte;
the counter keeps the pin saving **and** makes the sequential case fast via single-tick
increment. Latch bank = the slower fallback.)*

### 5.2 Bus MCU GPIO budget (the binding constraint)

Every signal, with the §5.1 counter and the '165 IRQ collector assumed. USB, console, POST
display, and image storage are **off on the Supervisor**, so they cost the Bus MCU nothing
beyond the 2-wire link (§5.3).

| Group | Signals | Pins | Notes |
|---|---|---|---|
| I/O address decode | A0–A9 | 10 | 10-bit ISA decode. A8/A9 **required** to separate 0x3E8 (COM3 mouse) from 0x2E8 (COM4). As built (2026-07-20): A0–A7 on GPIO8–15, **A8/A9 on GPIO42/46** — pins freed by moving SPEED_SEL to a cpu_core jumper and dropping the redundant raw RD̄ sense. |
| Data bus | D0–D7 | 8 | also carries the INTA vector + counter-load bytes |
| Command strobes | IOR̄/IOW̄ (bidir), MEMR̄/MEMW̄ (out) | 4 | sense as slave, drive as master |
| Bus control | ALE (in), AEN (bidir), RESET DRV (out) | 3 | |
| Ready / check | IOCHRDY (bidir), IOCHCK̄ (in) | 2 | |
| Bus grant | HOLD (out), HLDA (in) | 2 | V20 min-mode handshake |
| Interrupt deliver | INTR (out), INTĀ (in), NMI (out) | 3 | vector goes out on D0–D7 |
| IRQ inputs | 74HC165: LOAD, CLK, SER | 3 | one '165, original 8-bit map (D0–D5 = IRQ2–7, D6 = EXT_DRQ, D7 = IRQ14); a '32 ORs internal IRQ3/4/5/7 with the port's EXT_IRQ twins, EXT_IRQ2/6 feed it directly (2026-07-14); µs-poll is fine (ISA holds IRQ until serviced) |
| DMA handshake | DRQ (in), DACK̄ (out), TC (out), EXT_DACK̄ (out, GPIO47) | 4 | internal ch = PicoGUS, port ch = EXT_DRQ ('165 lane) + EXT_DACK̄ (GPIO freed by the REFRESH̄ retirement, 2026-07-14) |
| Counter control | COUNT + load-steer ×3 | 3–4 | drives the external 20-bit address counter |
| Speaker | PWM → op-amp (GPIO22) | 1 | PIT ch2 direct output; bus-CLK sense dropped (PIO tracks via BALE/strobes) |
| Transceiver DIR | master/slave | 0–1 | can be HLDA-derived externally |
| **Link to Supervisor** | **UART TX/RX** | **2** | §5.3 |
| **Total** | | **≈ 44–46 / 48** | fits with margin **because** the link is UART (2 pins). SPI (+3) would push to ~47–49 — at/over the edge. **As built: 48/48** — the margin was spent on SPKR (PIT ch2), EXT_DACK̄ (GPIO47, which had briefly been ~{REFRESH} until its 2026-07-14 retirement), and READY; the raw ~WR and IO/M̄ senses and DMA ch2/3 (DRQ/DACK) were dropped. |

Speed-select is a **hardware jumper on cpu_core** (JP1 by the '157 mux, 2026-07-20: open =
7.16 MHz default, fitted = 4.77 MHz — it spent a while as Bus MCU GPIO42, reclaimed for the
A8 sense), and the POST display is Supervisor-driven — both off the Bus MCU. The link choice
is worth ~3 pins and is effectively the difference between comfortable and over-budget (§5.3).

### 5.3 Cross-MCU link — 2-wire full-duplex UART

The Bus MCU and Supervisor are joined by a **UART** (TX/RX), software-framed (length-prefix +
CRC). Traffic:

| Flow | When | Volume |
|---|---|---|
| BIOS + option-ROM images (Super → Bus) | boot, once | ~128 KB |
| Keystroke / mouse events (Super → Bus) | runtime | a few bytes each |
| Menu-draw commands (Super → Bus) | pre-BIOS | < 4 KB/screen |
| POST codes (Bus → Super) | boot | 1 byte each |
| CMOS-write requests (Super → Bus) | setup exit | a few bytes — only the Bus MCU can reach 0x70/71 |

**Why UART over SPI/I²C:**
- **Pins.** 2 vs SPI's ~5 (4 + an attention line). On the pin-critical Bus MCU that swing is
  what keeps §5.2 under 48.
- **Traffic shape.** Runtime is *asynchronous, bidirectional, low-rate* events. UART's
  separate TX/RX lets either side transmit the instant it has data — no master/slave, no
  attention line, no polling. A keystroke goes USB → Supervisor → UART → KBC with nothing in
  the path adding latency.
- **Bulk is irrelevant.** The 128 KB image push is one-time with the V20 in reset; ~0.1–0.4 s
  at multi-Mbaud (PIO UART if needed) is invisible, and nothing else is on the link then. The
  one thing SPI wins (throughput) is the one thing that doesn't matter here.
- **I²C is strictly dominated** — same 2 pins as UART but seconds-long bulk transfer,
  half-duplex, ACK overhead, and the touchiest electricals.

---

## 6. Boot sequence

1. **Power-on** → the TL7705A/MAX809 supervisor IC holds reset until rails are stable → both
   MCUs boot; the **Bus MCU holds the V20 in reset**.
2. Bus MCU, as **bus master**, **clears all of SRAM to a known value** (both chips, full
   0x00000–0xFFFFF span). This guarantees the option-ROM scan windows (0xC0000–0xEFFFF) hold
   no stray `0x55AA` signatures that would send the BIOS into garbage init, and gives a clean
   slate before any shadow-load.
3. **Supervisor** brings up the **USB host** and reads the keyboard.
4. Supervisor streams **menu-draw commands** over the link; the Bus MCU, as **bus master**,
   sets the video card to 80×25 text and writes them to **0xB8000**. The Supervisor echoes the
   same menu to its **console UART**.
5. **Hotkey within a timeout** → the **Supervisor** runs setup (CPU speed default, keyboard
   XT/AT, mouse serial/PS-2, IDE/boot options…); settings persist to **Supervisor flash**. For
   DOS-relevant bits it sends **CMOS-write requests** to the Bus MCU, which writes its
   **emulated CMOS bytes** (only the Bus MCU answers 0x70/71; the values persist in
   Supervisor flash, §11.3).
6. On exit/timeout → the Supervisor **streams the BIOS + option-ROM images** (video BIOS
   @0xC0000, XTIDE @0xC8000) over the link; the Bus MCU **shadow-loads** them into SRAM, then
   **releases V20 reset**.
7. V20 fetches the reset vector from RAM → **Xi 8088 BIOS** runs normally. At runtime the
   Supervisor forwards USB HID events over the link to the Bus MCU's KBC/mouse emulation.

The Bus MCU's master engine thus serves **three** duties: boot shadow-load, sound DMA, and
pre-BIOS menu rendering — all fed by the Supervisor over the §5.3 link.

---

## 7. Memory subsystem

- **One IS62WV51216BLL-55TLI** (512K×16, 2.5–3.6V, 55 ns, TSOP-II-44), wired **1M×8 via the
  byte-lane trick** (2026-07-14 update — replaces the old 2× AS6C4008 pair + 2× DIP-32
  sockets): system `A1–A19` address the chip's 19-bit word space; `A0` selects the byte lane
  (`A0 → /LB` direct, `A0 → inverter → /UB`); **both `IO0-7` and `IO8-15` tie to the same
  D0–D7**, and the `/LB`/`/UB` pair guarantees exactly one lane ever drives (verified against
  the ISSI truth table, `hardware/notes/3v3-verification.md` check 2). `/CE` = NOT(latched
  Y5) (§4.1) — the chip answers the **entire 1 MB** space except the 0xA0000–0xBFFFF video
  window. Max conventional RAM (less the video window) = **1 MB**, still bounded by the
  address decode the same way as before; the two "conventional/UMB" regions below are no
  longer separate physical chips, just address ranges within the one SRAM.
- **No flash IC** — the SST39SF010 is not used; BIOS lives in SRAM, written at boot by the
  **Bus MCU** from images the **Supervisor** holds in its QSPI flash (update via the
  Supervisor's USB/storage, not in-circuit reflash).
- **Power-on clear:** SRAM contents are undefined at power-up, so the **Bus MCU** **zeroes
  the entire SRAM span** before shadow-loading (§6 step 2). This prevents random bytes in the
  option-ROM scan windows (0xC0000–0xEFFFF) from falsely matching the `0x55AA` ROM signature.
- **Video RAM is *not* in system SRAM** — it lives inside the video MCU (see §8), so the
  `0xA0000–0xBFFFF` window is owned by the video card, and there is **no shared-framebuffer
  arbitration, no CPLD, no CGA snow.**

### Memory map

```
0xFFFFF ┌───────────────────────────┐
        │ System BIOS (64K, shadow) │ SRAM, MCU-loaded; reset vector @0xFFFF0
0xF0000 ├───────────────────────────┤
        │ reserved / optional UMB   │ one SRAM chip, same /CE = NOT(Y5) block
0xD0000 ├───────────────────────────┤
        │ XTIDE Univ. BIOS (32K)    │ SRAM, MCU-loaded option ROM @0xC8000
0xC8000 ├───────────────────────────┤
        │ Video BIOS (32K)          │ SRAM, MCU-loaded option ROM @0xC0000
0xC0000 ├───────────────────────────┤
        │ Video window A000–BFFF    │ owned by the VIDEO MCU (not system SRAM; Y5 block)
0xA0000 ├───────────────────────────┤
        │ Conventional 80000–9FFFF  │ one SRAM chip (128K of its range)
0x80000 ├───────────────────────────┤
        │ Conventional 00000–7FFFF  │ one SRAM chip (512K of its range)
0x00000 └───────────────────────────┘
```

---

## 8. Video card (RP2350B) — snoop-and-mirror

A soft **CGA + MDA + Hercules** card that **owns its video memory** and renders it to a
modern display, fully decoupled from the CPU.

- **Self-decodes its window** (0xA0000–0xBFFFF and the CRTC/mode ports) from the bus's own
  latched A17–A19 and `MEMR̄/MEMW̄/IOR̄/IOW̄` — it uses **no signal that isn't on the ISA bus**,
  which is what keeps it liftable to a standalone ISA card unchanged. (The motherboard's Y5
  block-strobe, §4.1, is for the SRAM #2 decode only; the video card never sees it.)
- **Boot straps** (firmware-read GPIOs — decode lives in firmware, so there is no
  hardware chip-select to gate): **DIS_VID** (from **addr_decode JP1.5**, 2026-07-14 —
  replaced the on-sheet VID_EN jumper, polarity inverted) high = card disabled — firmware
  keeps every bus-facing OE off, and all its drivers are MCU-gated tri-states, so a
  disabled card is electrically silent; **JP1 (VID_BASE)** picks the default window set,
  closed = CGA
  (0x3D4–3DF / 0xB8000), open = MDA/Hercules (0x3B4–3BF / 0xB0000) — the snoop-design
  equivalent of a period card's MDA/CGA switch, and how the on-board video can yield to
  a second video card on the expansion port.
- **Snoop & accept writes** to `0xB0000–0xB7FFF` (MDA/Herc), `0xB8000–0xBBFFF` (CGA), and
  the CRTC/mode/color register ports (`3B4/3B5/3B8/3BA/3BF`, `3D4/3D5/3D8/3D9/3DA`) into
  its **own** internal video RAM + register state. **Writes are the hot path** (mode 13h
  game blits are almost all writes): the card latches address+data into its PIO FIFO and lets
  the cycle complete at **0 wait**, only pulling IOCHRDY if the FIFO backs up. This is the
  performance lever that matters, and it needs nothing but the standard bus.
- **Serve reads** of that region back onto the bus, wait-stated via **IOCHRDY** as needed —
  the card answers as the memory's owner. A wait-stated VRAM read is **period-authentic** (a
  real ISA video card serves its own reads the same way), and IOCHRDY is a standard ISA
  signal, so this stays fully portable. Reads are comparatively rare in the hot path.
- **Rejected alternative — shadowing the framebuffer into the (otherwise stranded) SRAM #2
  to serve fast local reads:** this would couple the video subsystem to motherboard memory
  and **break ISA-card portability**. Coordinating "who drives the read" needs either a
  private non-ISA signal or two devices both decoding 0xA0000–0xBFFFF — and 8-bit ISA has
  no arbitration for overlapping memory. It also can't return correct **planar** reads
  (stored bytes ≠ CPU bytes; reads have latch/color-compare side effects), so only the MCU
  can be the read source anyway. The window stays **wholly owned by the video subsystem**.
- **Status register coherence (0x3DA / 0x3BA):** games and demos poll the CGA/MDA status
  register's **display-enable (bit 0)** and **vertical-retrace (bit 3)** bits for tear-free
  updates and frame timing. Because the video MCU generates its own output timing decoupled
  from the CPU, it must report a 0x3DA/0x3BA value that **tracks its actual scan position** —
  i.e., the emulated retrace/display-enable must be coherent with the frame it is really
  displaying, not free-running. Reads are answered through the same IOCHRDY-wait path.
- **Render** the mirror continuously to output:
  - **VGA** — PIO + resistor-ladder DAC (e.g. 3R-3G-2B) + HSYNC/VSYNC, ~8 GPIO.
  - **HDMI/DVI** — the RP2350 **HSTX** block serializing TMDS out of GPIO with series
    resistors (no transmitter chip), ~8 GPIO.
  - The framebuffer is rendered **once in RAM**; **config selects the active output**
    (jumper / setup menu / HDMI hot-plug). Simultaneous dual-live output is a stretch goal.

**Pin pressure** (wide memory-window decode + two output stages) is why the video node is
the **48-GPIO RP2350B**.

### Scope (staged firmware — the board never changes)
- **v1:** CGA / MDA / Hercules (text + their native graphics). Solid, low risk.
- **Early add:** **VGA mode 13h** (320×200×256, linear) — easy, unlocks many games.
- **Later:** **EGA / VGA planar 16-color** (modes 10h/12h: 4 planes, latches, write modes,
  bit/map mask) — the hard part; every `A0000` write is a read-modify-write through plane
  logic within the bus cycle. RP2350 has the memory (520 KB SRAM + optional QSPI **PSRAM**
  for the 256 KB VGA aperture) and clock to attempt it; may need extra wait states.

The hardware is specified **VGA-capable** from the start; scope is a firmware milestone.

---

## 9. Audio — on-board PicoGUS

A **faithful copy of the upstream PicoGUS 2.0 "chip-down" design** (CERN-OHL-P;
`picogus/hw-chipdown/` sources): a **bare RP2040** + W25Q128 flash + 12 MHz crystal (the
same three parts as the Supervisor — one assembly line item each), the signature
**ADS-muxed shared AD0–AD7** bus interface through SN74CB3T FET switches, the BUSOE
power-up latch, AEN·DACK IOR̄/IOW̄ masking, open-drain IOCHRDY, **APS6404L-3SQR** sample
PSRAM, and a **PCM5102A I²S DAC** — running **stock, unmodified firmware** (GPIO29
grounded is the stock board-detect strap). Personalities (one at a time): **AdLib/OPL2,
Sound Blaster, Gravis UltraSound, MPU-401, CMS/Game Blaster, Tandy/PCjr**.

- **Why RP2040, not RP2350B:** stock PicoGUS emulation firmware is RP2040-only. The board
  still carries two part numbers (2× RP2350B + 2× RP2040) — but both RP2040s are now the
  same bare-chip design, sharing flash/crystal parts.
- **Requires functional DMA** in the Bus MCU (§5) — SB/GUS digital audio is DMA-driven.
  **DMA is hardwired to channel 1** (the only MCU-serviced channel; the reference
  card's jumper block is deleted outright, 2026-07-14 — it offered a ch3 the board
  can't service), and the **IRQ is hardwired to IRQ5** (the
  free line, sole driver — pgusinit sets the firmware to match).
- **Deviations from the reference card** (logged in `notes/questions-picogus.md`): no USB-A
  joystick port (the Supervisor owns HID, so **no gameport** — 0x201 unused); **no
  wavetable header and no MIDI-out jack** (build simplification — and with the wavetable
  gone, the reference's M62429 volume chip and passive mix node go too; stock firmware
  still drives the volume/MIDI GPIOs, which are documented no-connects); **no local audio
  jack** — the RC-filtered DAC output leaves the sheet as PG_L/PG_R into the op-amp summer
  with the PC speaker → the board's one line-out jack; **no local programming USB** — the
  Supervisor's shared programming port reaches this RP2040 via the SW2 selector (§12), a
  documented soft-card isolation exception. All removed blocks remain in the reference
  sources if ever wanted back.

### 9.1 Network — removed

The on-board **RTL8019AS NE2000 NIC** (I/O 0x340, IRQ2→9, 10BaseT, ISA8019 lineage) was
**removed 2026-07-14** — git tag **`full-board-with-nic`** preserves the last full design
(sheet, symbols, part bindings) if it is ever wanted back. Networking, if needed, arrives
as a real NE2000 card on the buffered expansion port (its IRQ comes in as EXT_IRQ2 and
redirects to IRQ9 in the soft PIC, exactly as the on-board chip's did).

---

## 10. Storage — XT-IDE + CompactFlash

Discrete and period-correct (uses 74HCT on hand):
- **XT-IDE rev 2 / "Chuck-mod"** 8-bit interface: a **74HCT573/652 high-byte latch** makes
  the 16-bit IDE data register two 8-bit transfers. **I/O base 0x300, hardwired** (the 0x320
  re-strap went with the other base straps, 2026-07-14 later; the block match arrives as
  ~IDE_CS from `addr_decode`); **addr_decode JP1.4** disables the port outright (forces
  ~IDE_CS inactive — every select, latch clock
  and buffer goes inert, the IRQ stays released), so an external XT-IDE on the sidecar
  chain can coexist or take over. **The IRQ is hardwired to IRQ14** (the AT primary-IDE
  convention, collected on the Bus MCU's '165 D7; a motherboard-internal line, not on
  the expansion header) — the soft PIC is AT-style anyway, so there's nothing to strap.
- **40-pin IDE header + CompactFlash** (True-IDE). 8-bit-capable CF can skip the latch; keep
  it for general IDE drives.
- Boot ROM = **XTIDE Universal BIOS**, shadow-loaded @0xC8000. Polled or interrupt-driven
  is purely an XTIDE UB per-controller config choice — the line is wired either way, and
  the tri-state driver is silent unless the drive asserts INTRQ.
- *(Alternative not taken: an SD-card-backed virtual IDE on a small MCU. Discrete XT-IDE+CF
  is simpler and rock-solid.)*

### 10.1 Floppy — all-firmware (no controller hardware)

**Decision: no physical FDC.** Floppy support is emulated entirely in the Bus MCU,
because every piece rides infrastructure the board already has — the marginal
hardware cost is exactly zero:

- **Registers:** the Bus MCU is already a full 8-bit ISA slave (it serves the
  emulated PIT/KBC/COM3 today); a virtual floppy just claims I/O ports and
  answers them in firmware.
- **IRQ6** is raised inside the soft PIC the same way virtual COM3 raises IRQ4 —
  a firmware event, no physical line. (The internal IRQ6 net is retired, its
  collector lane tied low; a sidecar FDC would deliver physical IRQ6 as
  EXT_IRQ6 through the expansion port's isolated lines.)
- **"DMA":** the emulated 8237 lives in the same chip, and sector transfers into
  conventional memory use the existing bus-master machinery (HOLD/HLDA + the
  §5.1 counter chain) — the same path every other emulated DMA transfer takes.
- **Media:** disk images live in the Core2350B module's flash; selection/swap is
  a page in the Supervisor's pre-BIOS setup menu (§12), and images arrive over
  the existing USB/console paths.
- **BIOS:** the shadow-loaded BIOS fork hooks INT 13h for the floppy exactly as
  XTIDE UB hooks it for the disk.

Two firmware tiers, both zero-hardware — ship tier 1, add tier 2 only if real
software demands it:

1. **INT 13h hook** (ship this): BIOS floppy services call a private Bus MCU
   port; sectors appear. DOS and anything well-behaved works.
2. **Register-level µPD765 emulation @ 0x3F0–0x3F7** (only if needed): the 765
   command state machine as bus-visible registers, for software that bangs the
   controller directly (copy-protected boot loaders, imaging tools).

*(Path not taken: a real socketed WD37C65/FDC37C78 + 34-pin header. It would
also need DMA ch2, which the Bus MCU doesn't service — either non-DMA-mode
BIOS floppy code or the '165/'595 GPIO expansion (§5.2). Only worth the board
space if a physical drive or Gotek must plug in; nothing else requires it.)*

---

## 11. Serial / parallel / RTC / input

### 11.1 Serial (2× COM)
- **2× TL16C550CPFBR** (TQFP-48, soldered directly at 3.3V — 2026-07-14 update: replaces the
  socketed PLCC-44 16C550; the LQFP PT revisions are dead at JLC, the active PFB is
  **thin stock, C882798**, see `hardware/notes/jlcpcb-sourcing.md`) (ONE `com_port` sheet
  carrying both ports — merged 2026-07-14 from the instanced-×2 layout; both chip selects
  now arrive from the **central `addr_decode` sheet** (below), so the only shared glue left
  on the COM sheet is one 74LVC125A gating both IRQs): **COM1 0x3F8/IRQ4**,
  **COM2 0x2F8/IRQ3** — base addresses and IRQs are **hardwired** (the PC convention; no
  strap to misconfigure — the old J2 base strap existed only because one generic sheet was
  instanced at both addresses). On-board only — no standalone COM card — the per-port
  disable jumpers are **addr_decode JP1.1/JP1.2** (positions in the 2×5 disable block; enabled by default — a fitted cap forces
  the port's ~CS inactive so it never decodes, MCR stays 0, and the central IRQ driver
  stays tri-state — a disabled port is silent on every line, which is how you free its
  IRQ).
- **MAX3241** per port (3.3V — Task-10 moved it onto the 3.3V rail so its receiver
  outputs no longer swing 5V into U1's non-5V-tolerant inputs; caps resized to the
  datasheet 3.0–3.6V column) — 3 drivers + 5 receivers = a **full DB9**
  (TXD/RTS/DTR out; RXD/CTS/DSR/DCD/RI in), internal charge pump (single-supply, no ±12 V).
- **TTL console header** jumpered onto COM1 (ahead of the MAX3241) for headless bring-up.
- (TL16C554 quad rejected: ~6× the cost for 4× ports; add COM3/4 on the expansion port
  later — note **COM3 0x3E8 is reserved for the emulated serial mouse**, §11.4.) The 50-pin
  expansion-port header carries only the standard 8-bit ISA IRQ lines (IRQ2–7; IRQ8 has no
  header pin at all — the RTC that once justified it is now firmware-emulated off-bus,
  §11.3), so an expansion COM4 cannot use IRQ10+ — but **IRQ2 is free** (the on-board NIC
  that claimed it was removed, §9.1): **an expansion COM4 (0x2E8) uses IRQ2→9 directly**,
  or disable COM2 (addr_decode JP1.2) for IRQ3 — still avoiding the ISA
  edge-triggered IRQ-sharing problem. The virtual COM3 mouse keeps
  **IRQ4** (the convention mouse drivers expect), so it *does* share IRQ4 with COM1; in
  practice you use one or the other (most mouse use implies COM1 is free).

### 11.2 Parallel (LPT)
Discrete **74HC/74LVC** ('574 data/control latches + '244/'245 status & read-back, now
3.3V-powered) — on-board only: base address **0x378, hardwired** (the 0x278
strap went with the other base straps, 2026-07-14 later; the block match arrives as
~LPT_CS from `addr_decode`); disable via **addr_decode JP1.3** (forces ~LPT_CS inactive: no
register can be read, written or latched — and frees the line). **IRQ7 is hardwired** (LPT1 convention). The IRQ driver
is tri-state (asserted only for an enabled ACK̄ pulse), so the line stays
shareable.

### 11.3 RTC
**2026-07-14 update — RTC moved off-bus entirely; the DS12C887 and its ISA glue are
deleted.** Ports **0x70/0x71 are emulated in the Bus MCU** (same as the PIC/PIT/KBC), so
there is no longer an on-board `rtc` ISA sheet at all. Battery-backed timekeeping lives on
the **Supervisor**: a **PCF8563 I2C RTC + CR2032 coin cell**, diode-ORed onto its own
`VDD_RTC` rail so the coin cell only carries the load while the board is powered off. At
boot the Supervisor reads the PCF8563 and sends the time to the Bus MCU over the existing
UART link, which then answers 0x70/0x71 reads from its in-firmware CMOS-byte emulation
(persisted in **Supervisor flash**, not battery-backed NVRAM). Holds CMOS config; pairs with
Xi 8088's CMOS setup the same as before — only the hardware backing it changed.

### 11.4 Input — USB HID, mouse emulation
- **Single USB-A host jack** on the **Supervisor** MCU. Keyboard plugs straight in; a mouse
  needs the user's own hub (most XT software is keyboard-only).
- HID is a neutral middle layer: the **Supervisor** decodes USB HID and sends events over the
  §5.3 link; the **Bus MCU** presents them at the bus as **XT (8255/set 1) or AT (8042/set 2)**
  keystrokes per config, and the mouse as either a **virtual COM3 serial mouse** (default —
  works on any BIOS/DOS, no physical port or wasted UART) or a **PS/2 mouse on IRQ12** (for AT
  setups). Splitting HID decode (Supervisor) from bus presentation (Bus MCU) is the whole point
  of the two-MCU design.

---

## 12. Bring-up aids
- **2-digit hex POST display** — the **Bus MCU** snoops **port 0x80** and forwards each code
  over the §5.3 link; the **Supervisor** drives the display. *(Confirmed on-board.)*
- **Supervisor console UART** (3-pin TTL) — setup menu + bring-up logging; the single most
  useful debug tool here. Bring-up bonus: the Supervisor + console + USB come up and are fully
  testable **before** the Bus MCU's bus engine is working.
- **Logic-analyzer header** on the demuxed bus.
- Cold-start **reset/power supervisor**.
- **Module-USB flashing is safe**: the Core2350B has *no* on-module diode between its USB
  connector and its VBUS pin (vendor schematic), so each module site feeds VBUS through a
  **Schottky (SS34), Pico-style** — a PC plugged into the Bus-MCU or video module for
  firmware update powers only that module, never the +5 V rail, and a powered board never
  back-drives the PC port. The modules' level-shifter enables/directions carry park
  resistors, so an MCU in BOOTSEL (all GPIO Hi-Z) leaves every bus-facing buffer disabled.
- **One programming port for both bare RP2040s**: a USB-C device port (J6, Supervisor
  sheet) reaches either the Supervisor or the PicoGUS RP2040 via a **DPDT slide selector
  (SW2)**; each chip has its own **BOOTSEL button**. The port's **VBUS is deliberately
  unconnected** — the board must be powered to flash, which removes every back-power path
  by construction. Flashing the Supervisor: unplug the keyboard (the host jack shares the
  PHY). The PicoGUS's BUSOE latch keeps its bus switches off until firmware runs, so
  flashing it never disturbs the ISA bus.

---

## 13. Power
- Single **5 V input** (USB-C) → on-board **3.3 V buck** now carrying **nearly the whole
  board** (2026-07-14 update): all four MCUs, USB, the SRAM, both UARTs, and essentially
  every logic package except the V20, one 74HCT04 (V20 CLK buffer), and the expansion
  port's far side. Re-budgeted (`hardware/notes/3v3-verification.md` check 5): worst-case
  estimated load ≈486 mA, ~16% of the existing TPS563200's 3A rating — **no buck upsize
  needed**, even doubling every estimate lands at ~33% of budget.
- **No ±12 V** (MAX3241 charge pumps; PicoGUS audio is 3.3/5 V). 5 V must also source USB
  VBUS for the keyboard/hub, so the input has to supply the whole board *plus* a downstream
  USB device — the tight current loop to size for.
- **USB-C power negotiation:** the board only needs **5 V**, and at 5 V a Type-C sink can
  draw up to **3 A (15 W)** with *no PD silicon at all* — just the mandatory **5.1 kΩ Rd
  pulldowns on CC1/CC2**, which lets the board draw whatever current a Type-C source
  advertises via its Rp (up to 3 A). That is the cheap baseline. **Optionally** add a tiny
  fixed-function PD sink controller (**CH224K** or **HUSB238**, ~$0.50, a few resistors, no
  firmware) to *guarantee* a 5 V/3 A contract from PD-only supplies that won't hand out 3 A
  on Rp alone. Higher PD voltages are unnecessary since nothing on board wants >5 V.
- The RTC's **CR2032 coin cell** (on the Supervisor) is the board's only battery — the
  DS12C887's integral battery is gone along with the chip (§11.3).

---

## 14. I/O map, IRQ, DMA

### I/O map
| Range | Device |
|---|---|
| 0x000–0x00F | 8237 DMA (Bus MCU, **functional**) |
| 0x020–0x021 / 0x0A0–0x0A1 | 8259 PIC master / slave (Bus MCU) |
| 0x040–0x043 | 8254 PIT (Bus MCU) |
| 0x060–0x064 | keyboard controller (Bus MCU; 8255 or 8042 mode); **0x061 bit 4 = refresh toggle** |
| 0x070–0x071 | **RTC, emulated in the Bus MCU** (PCF8563-backed, synced from the Supervisor); **0x070 bit 7 = NMI mask** (AT-style) |
| 0x080–0x083 | DMA page regs; **0x080 POST latch** (snooped → hex display) |
| 0x201 | (unused — no gameport; HID via the Supervisor, §11.4) |
| 0x220.../0x240.../0x330/0x388 | PicoGUS (SB / GUS / MPU / OPL) |
| 0x2F8 / 0x3F8 | COM2 / COM1 (TL16C550CPFBR) |
| 0x3E8 | **COM3 — emulated serial mouse** (Bus MCU, IRQ4) |
| 0x3F0–0x3F7 | (reserved) **firmware floppy** tier-2 registers, §10.1 (Bus MCU) |
| 0x2E8 | COM4 (expansion port; needs a freed IRQ — see §11.1) |
| 0x300–0x31F | XT-IDE (base hardwired; addr_decode JP1.4 disables) |
| 0x340–0x35F | (free — was the on-board NE2000 NIC, removed 2026-07-14, §9.1) |
| 0x378 | LPT1 (base hardwired; addr_decode JP1.3 disables) |
| 0x3B0–0x3BF / 0x3D0–0x3DF | MDA-Hercules / CGA (video MCU) |

### IRQ (AT-style, 15 lines via cascaded soft-PIC)
| IRQ | Use | | IRQ | Use |
|---|---|---|---|---|
| 0 | Timer | | 8 | RTC — **firmware-internal only** (Bus MCU soft-PIC event; no expansion-port pin) |
| 1 | Keyboard (USB-HID) | | 9 | IRQ2 redirect (expansion-port cards, via EXT_IRQ2) |
| 2 | cascade → slave | | 10 | spare (no line on 8-bit header) |
| 3 | COM2 | | 11 | spare (no line on 8-bit header) |
| 4 | COM1 (+ COM3 mouse, shared) | | 12 | PS/2 mouse (if used) |
| 5 | **PicoGUS (hardwired, sole driver)** | | 13 | (FPU — unused) |
| 6 | firmware floppy (virtual, §10.1) / expansion-port spare | | 14 | **XT-IDE (hardwired)** — internal line |
| 7 | LPT1 (hardwired) | | 15 | spare (no line on 8-bit header) |

### DMA
| Ch | Use | | Ch | Use |
|---|---|---|---|---|
| 0 | (refresh — unused, SRAM) | | 2 | (firmware floppy needs none, §10.1) |
| 1 | **PicoGUS (SB/GUS)** | | 3 | expansion port / spare |

---

## 15. BOM — period part vs. this build

> Concrete JLCPCB/LCSC part numbers for everything below live in
> `hardware/tools/parts.py` (applied to the schematics as `LCSC Part Num`
> properties); sourcing decisions and stock-forced substitutions are in
> `hardware/notes/jlcpcb-sourcing.md`. **2026-07-14 update:** the board's internal
> bus moved to 3.3V (below); the TL16C550CPFBR UART (C882798) is thin JLC stock — verify.

| Function | Period part | This build |
|---|---|---|
| CPU | 8088 | **NEC V20 (µPD70108, 9 MHz grade, on hand)** — min mode; ≥8 MHz part required for the 7.16 MHz default |
| Clock gen | 8284A + 14.318 xtal | **14.318 osc (3.3V) + 74LVC74A (÷2) + 74LVC161 (÷3) + 74HC157 sel** — LVC-grade for 3.3V fmax margin |
| Bus controller | 8288 | **(none — min mode)** |
| Math | 8087 | **(none — software FP)** |
| Address latch / xceiver | 8282 / 8286 | **74LVC573A ×3 / 74LVC245A** (3.3V, 5V-tolerant inputs) — the board's one 5V↔3.3V boundary |
| Decoder | 74LS138 | 74HC138 + 74HC00 inverter (single-SRAM `/CE = NOT(Y5)`) |
| PIC / PIT / KBC / DMA / RTC | 8259 / 8253 / 8042 / 8237 / MC146818 | **Bus MCU: RP2350B (soft-emulated)**, GPIOs direct on the 3.3V bus (no local transceivers) |
| Chipset Supervisor | (part of the chipset) | **RP2040** — USB host, setup UI, config + BIOS-image flash, console, POST, battery-backed RTC |
| Bus-master address | (8237 internal + 74LS612 page) | **5× 74HC161** loadable counter + 3× 74HC244 tri-state (Bus MCU drives load/count) |
| IRQ collector | (8259 internal) | **one 74HC165 + 74HC32 OR rank** (internal IRQ3–7/14 ∪ expansion EXT_IRQ → 3 pins) |
| Chipset link | — | **2-wire UART** (Bus MCU ↔ Supervisor) |
| RAM | 9× 4164 + parity | **1× IS62WV51216BLL-55TLI** (512K×16, 3.3V) wired 1M×8 via the byte-lane trick |
| ROM / BIOS | mask ROM / 2764 | **none — shadow-loaded into SRAM by the Bus MCU (image from Supervisor flash)** |
| Video | MC6845 + discrete + RGBI | **RP2350B (soft CGA/MDA/Herc) → VGA + HDMI**; 4× 74LVC245A PIO-mux (GPIO budget, not level-shift) |
| FM / digital audio | AdLib / Sound Blaster | **on-board PicoGUS (RP2040, stock fw)** |
| Network | (none, period) | (none — on-board NIC removed 2026-07-14; NE2000 card on the expansion port if needed) |
| Game port | discrete 558 | **(none — USB HID on the Supervisor)** |
| UART | 8250 | **2× TL16C550CPFBR** (TQFP-48, 3.3V, soldered — thin JLC stock, C882798) |
| RS-232 | 1488/1489 | **MAX3241 (full DB9, 3.3V)** |
| LPT | discrete TTL | 74HC/74LVC '574 + '244 (3.3V) |
| RTC | MC146818 | **Emulated in the Bus MCU** (ports 0x70/71) + **PCF8563 I2C RTC + CR2032** on the Supervisor for battery-backed time |
| Storage | ST-506 + WD ctrl | **XT-IDE + CompactFlash** |
| Keyboard | 8048 + 8255 + 74LS322 | **USB-HID host on the Supervisor MCU** |

**Out-of-production ICs eliminated vs. the period build:** 8284, 8288, 8087, 8259, 8253,
8237, 8255/8042, MC6845, YM3812/YM3014, MC146818/DS12C887, and the BIOS ROM.
**Remaining vintage part: the V20.**

---

## 16. Open decisions / next steps
- **Bus MCU GPIO pinout** — assignment is now drawn at 48/48 (see §5.2 "as built"); the
  partial-address-decode concern is **resolved** (full A0–A9 sense since 2026-07-20, GPIO42/46);
  still to confirm: the single-DMA-channel assumption and the core0-PIO (bus) / core1
  (DMA+PIC) split under load.
- **Cross-MCU UART protocol** — define the framing (length + CRC) and message set (image push,
  HID event, menu draw, POST code, CMOS-write); pick the baud (hardware UART vs PIO multi-Mbaud)
  and confirm worst-case keystroke latency through USB → Supervisor → UART → KBC.
- **Bus-master timing** — detail HOLD/HLDA acquisition, the §5.1 counter load/count loop, the
  functional-8237 transfer cycle, and pre-BIOS video writes.
- **Video bus timing** — confirm **0-wait write** capture (PIO FIFO depth vs. sustained
  write bandwidth) is the design point; size the **IOCHRDY** budget for wait-stated reads
  (CGA/MDA now, planar VGA later). No SRAM shadow — the window stays ISA-portable (§8).
- **Xi 8088 fork** — slave-PIC init + IRQ2→9 redirect (15 IRQ); AT-style NMI mask at 0x70
  bit 7; confirm BIOS/timing code that polls the **0x61 bit 4 refresh toggle** is satisfied
  by the synthesized toggle; shadow-RAM execution; virtual-COM3 mouse; video/XTIDE
  option-ROM integration; confirm 8042 vs 8255 keyboard expectations.
- **PicoGUS integration** — copy the reference schematic faithfully; wire DRQ/DACK to the
  Bus MCU; route audio mixing.
- ~~**Level-shifter selection**~~ — **resolved by the 2026-07-14 3.3V redesign**: the
  boundary collapsed to the V20's own demux stage plus one buffer bank at the expansion
  port (§4.2/§4.3); the Bus MCU no longer carries any level shifters at all.
- **Setup menu** — define the stored settings (CPU speed, kbd mode, mouse mode, boot order)
  and the **Supervisor-flash** format.
- ~~**Power budget**~~ — **resolved by the 2026-07-14 3.3V redesign's verification pass**:
  worst-case estimate ≈486 mA against the existing 3A buck (~16%, 6× headroom); no upsize
  needed (`hardware/notes/3v3-verification.md` check 5). USB-C CC-pulldown-only vs.
  CH224K/HUSB238 PD sink remains a build-time choice, not a sizing risk.
```

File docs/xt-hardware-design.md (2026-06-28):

# XT-Class SBC — Hardware Design Notes

A working design reference for a DOS-compatible, XT-class single-board computer built
from **distinct period-style ICs** (no "one microcontroller emulates everything").
Goal is **education**, not emulation. Modern parts are used where they simplify
sourcing/assembly without hiding how the machine actually works.

See companion docs: `early-pc-cpus.md` (the CPUs) and `memory-management.md`
(segmentation / banking / EMS / XMS / DOS extenders).

---

## 1. Design summary / decisions locked

| Area | Decision |
|---|---|
| CPU | NEC **V20** (8088 pin-compatible, faster; 8088 also fine), **max mode** |
| Clock | **Single 28.63636 MHz oscillator**, divided → 7.16 CPU/ISA, 14.318 OSC, 1.193 PIT, 28.636 video |
| CPU speed | **~7.16 MHz** (28.636 ÷ 4); 4.77 MHz turbo-switchable |
| Reset | **TL7705A power-good supervisor** + 74HC74 sync (8284A does NOT do power-good) |
| RAM | **2× AS6C4008-55** (512K×8 SRAM each → 1 MB raw, ~640 KB usable conventional) |
| ROM | **1× SST39SF010** (128K×8 flash, in-circuit reprogrammable) |
| Video | **CGA + MDA + Hercules** via real **MC6845**, shared SRAM, **VGA out via scan-doubler** |
| Storage | **On-board XT-IDE-compatible** interface → CompactFlash |
| Bus | **One 8-bit ISA slot** |
| Audio | **PC speaker + OPL2 (YM3812)** mixed to line-out |
| I/O | Multiple COM (16C550), **TTL serial console header**, parallel port, **joystick port**, RTC |
| Debug | **POST-code display** (port 0x80), config DIP switches |

---

## 2. Block diagram

```
   28.63636 MHz oscillator (8× NTSC colorburst — single master clock)
        │
   ┌────┴─────────────── 74HC393 / 161 divider ───────────────┐
   │ ÷4 = 7.15909 MHz     ÷2 = 14.31818 MHz     ÷12 of 14.318  │  28.636 →
   │  → CPU CLK, ISA CLK   → ISA OSC (B30)        = 1.193 MHz   │  video/VGA
   └───┬──────────────────────┬──────────────────────┬────────┘  dot clock
       │ CLK                   │ OSC                   │ → PIT
  ┌────┴────┐  status     ┌────┴───┐
  │  V20    │────────────►│ 8288   │ MEMR/MEMW/IOR/IOW/INTA
  │(max md) │  S0-S2      │ bus ctl│
  └────┬────┘             └────────┘      TL7705A ──► 74HC74 ──► RESET (synced)
 AD bus│ multiplexed                      (power-good + reset btn)
   ┌───┴────────────┐
   │ 573 latches +  │  →  A0-A19 (system address bus)
   │ 245 transceiver│  ↔  D0-D7  (system data bus)
   └───┬────────────┘
  ┌────┼──────────┬──────────┬──────────┬───────────┬──────────┐
┌─┴─┐┌─┴──┐    ┌──┴───┐  ┌────┴───┐ ┌────┴─────┐ ┌───┴──┐
│SR1││SR2 │    │FLASH │  │ Core   │ │ Video    │ │ ISA  │
│512││512 │    │128K  │  │ support│ │ MC6845 + │ │ slot │
│K  ││+vid│    │BIOS+ │  │82C59/  │ │ font ROM │ └──────┘
│   ││+UMB│    │VBIOS+│  │82C37/  │ │ + CPLD + │
└───┘└─┬──┘    │XTIDE │  │82C54/  │ │ scandblr │ I/O: XT-IDE/CF · 16C550 ·
   shared      └──────┘  │82C55   │ │ → VGA    │ LPT · RTC · KB · speaker ·
   video                 └────────┘ └──────────┘ OPL2 · joystick · POST LEDs
```

---

## 3. Clock, reset, and bus control

### 3.1 Single-oscillator clock tree (the key simplification)
A single **28.63636 MHz** canned oscillator (8× the 3.579545 MHz NTSC colorburst — a
stock, cheap part) is the only timing source. A 74HC393/74HC161 divider chain produces
everything:

```
28.63636 MHz ─┬─ ÷2 → 14.31818 MHz → ISA OSC (B30)  ─┬─ ÷12 → 1.193182 MHz → PIT
              │                                       │
              ├─ ÷4 → 7.15909 MHz → CPU CLK + ISA CLK (B20)
              │
              └─ ×1 → 28.636 MHz → VGA scan-doubler output dot clock
```

**Why not just one 14.318 crystal for everything?** The 8284A divides its input by 3
(no ÷2 option), so a 14.318 crystal yields the stock **4.77 MHz** CPU — not faster. And
you can't run the CPU *at* 14.318 (beyond the V20's rating). Starting from **28.636**
and dividing gives a clean **7.159 MHz** CPU **and** the required **14.318 OSC** from
one part — and conveniently the same 28.636 is the VGA output dot clock (§6).

**Consequence:** the CPU clock comes from the **divider**, fed straight to the V20
(CMOS, accepts a standard ~50% clock at 7.16 MHz — verify against the V20 CLK spec; if
you ever drop in a real NMOS 8088 you'd want the 8284A's 33%-duty clock instead, which
is another reason to stick with the V20). This **demotes the 8284A out of its clock
role**, so it's no longer needed — reset and READY synchronization move to discrete
74HC74 flip-flops (§3.3), which is cleaner and more instructive.

### 3.2 Turbo switch
Provide a **7.16 / 4.77 MHz switch** (mux the CPU-clock divider tap: ÷4 vs ÷6, or gate
in a 14.318-derived 4.77). Old games that time with CPU loops need slow mode. Expose a
status bit so software can read the current speed. **Keep PIT at 1.193 MHz and ISA OSC
at 14.318 in both modes.**

### 3.3 Reset / power-good (must add — the 8284A doesn't do this)
The 8284A only *synchronizes* an incoming reset; it does **not** detect power-good. So:
- **TL7705A** supervisor (or MAX809 / DS1813) asserts reset until Vcc is stable and
  debounces the **reset button**.
- A **74HC74** synchronizes that reset to the 7.16 MHz CLK before it reaches the CPU
  (the CPU needs RESET meeting setup time relative to CLK).

### 3.4 Bus interface and wait states
- **74AHCT573** latches demux A0–A19 (gated by ALE); **74AHCT245** buffers D0–D7
  (DIR = DT/R̄, OĒ = DEN̄).
- **8288** decodes status S0̄–S2̄ → MEMR̄/MEMW̄/IOR̄/IOW̄/INTĀ (max mode; also enables the
  optional 8087).
- **READY synchronizer:** a 74HC74 samples the async wait/IOCHRDY/peripheral-ready
  signals to CLK.
- **Wait states:** SRAM (55 ns) runs **0 wait states** at 7.16 MHz. Add **1–2 waits**
  for flash, peripheral chips, and the ISA slot via a small shift-register/counter.

---

## 4. Memory subsystem

### 4.1 Capacity reality
The XT map reserves the top 384 KB; **max conventional RAM is 640 KB**
(`0x00000–0x9FFFF`). Of the 1 MB of SRAM:
- **SRAM #1** → all of `0x00000–0x7FFFF` (conventional).
- **SRAM #2** → top 128 KB of conventional (`0x80000–0x9FFFF`), the **video
  framebuffer** windows, and an optional **UMB**. Remainder spare.

### 4.2 Memory map

```
0xFFFFF ┌───────────────────────────┐
        │ System BIOS (64K)         │ FLASH bank 0  → reset vector @ 0xFFFF0
0xF0000 ├───────────────────────────┤
        │ reserved                  │
0xE0000 ├───────────────────────────┤
        │ (optional UMB 64K)        │ SRAM #2  → LOADHIGH TSRs (XT UMB driver)
0xD0000 ├───────────────────────────┤
        │ XT-IDE BIOS (32K) @C800   │ FLASH bank 1 (hi)
0xC8000 ├───────────────────────────┤
        │ Video BIOS  (32K) @C000   │ FLASH bank 1 (lo)
0xC0000 ├───────────────────────────┤
        │ CGA framebuffer  @B8000   │ SRAM #2  ← shared, arbitrated
0xB8000 ├───────────────────────────┤
        │ MDA/Hercules fb  @B0000   │ SRAM #2  ← shared, arbitrated
0xB0000 ├───────────────────────────┤
        │ (graphics window A000)    │ optional, SRAM #2
0xA0000 ├───────────────────────────┤
        │ Conventional RAM 80000-9F │ SRAM #2 (128K)
0x80000 ├───────────────────────────┤
        │ Conventional RAM 00000-7F │ SRAM #1 (512K)
0x00000 └───────────────────────────┘
```

### 4.3 Decode (74HC138 on A17–A19 → eight 128 KB blocks)

| 138 out | Range | Device |
|---|---|---|
| Y0–Y3 | 0x00000–0x7FFFF | **SRAM #1** (use `~A19` directly) |
| Y4 | 0x80000–0x9FFFF | **SRAM #2** (conventional top) |
| Y5 | 0xA0000–0xBFFFF | **SRAM #2** (video windows) + 6845 video decode |
| Y6 | 0xC0000–0xDFFFF | **FLASH bank 1** (video BIOS + XT-IDE BIOS) |
| Y7 | 0xE0000–0xFFFFF | **FLASH bank 0** (BIOS) + optional UMB in E-seg |

```
SRAM1_CS̄ = ~A19                                  ; 0x00000–0x7FFFF
SRAM2_CS̄ = Y4 | (video window) | (E-seg UMB, opt.)
FLASH_CS̄ = (A19 & A18 & A17 & A16)               ; 0xF0000–0xFFFFF  (bank 0)
         | (A19 & A18 & ~A17)                     ; 0xC0000–0xDFFFF  (bank 1)
FLASH_A16 = 1 in 0xC0000–0xDFFFF, else 0          ; selects flash bank
```

- One 128 KB flash serves **BIOS (64K) + video BIOS (32K) + XT-IDE BIOS (32K)**.
- ROM/flash enables on **read only** → stray writes ignored. Route WĒ for in-system
  programming only; protect with the chip's **software data protection** and/or a
  **program-enable jumper**.
- **No parity** (SRAM) — ensure BIOS does not enable the parity-check NMI path.

### 4.4 Shared SRAM for video — bus arbitration
The MC6845 streams addresses continuously during active display; the framebuffer lives
in **SRAM #2**, so CPU and video contend for that chip. Resolution:

- **Video-priority interleave with CPU wait on collision.** Give the 6845 fetch its
  SRAM slot each character clock; if the CPU wants SRAM #2's video window in the same
  slot, drop CPU READY for that cycle. With 55 ns SRAM and a 140 ns CPU cycle there's
  ample bandwidth, and giving video priority **eliminates CGA "snow"** (unlike the real
  CGA, which let the CPU win and corrupt the display).
- Only the **video window** needs arbitration; `0x80000–0x9FFFF` is CPU-only.
- Implement the arbiter (address/CE mux + READY gating) in the video **CPLD** — it's a
  deliberately-designed peripheral, not a chip-emulator stand-in.

---

## 5. Core support chips (the "it's a PC" set)

Use **CMOS 82Cxx** variants for headroom at 7.16 MHz.

| Chip | Function | I/O ports | Notes |
|---|---|---|---|
| **82C59A** | Interrupt controller (PIC) | 0x20–0x21 | single PIC (XT) |
| **82C37A** | DMA controller | 0x00–0x0F | **largely vestigial** (see below) |
| **82C54** | Timer (PIT) | 0x40–0x43 | clock **1.193 MHz** from 14.318÷12 |
| **82C55A** | Peripheral interface (PPI) | 0x60–0x63 | keyboard, DIP switches, speaker gate |
| **74LS670** | DMA page registers | 0x80–0x83 | upper address bits per DMA channel |

**DMA is nearly idle:** SRAM needs no refresh (the original used DMA ch0 for that) and
XT-IDE is PIO. Include the 82C37 for software/BIOS compatibility (and any DMA-using ISA
card / optional floppy); clock it at **CLK÷2 (~3.58 MHz)** to stay within floppy DMA
timing. The **82C54 must stay at 1.193 MHz.**

### 5.1 Optional: second 82C59A for 15 IRQs
The expanded IRQ range is a **support-chip feature, not a CPU feature** — a second
cascaded 82C59A works fine on the 8-bit V20/8088 board (no 286 or 16-bit bus needed).
**But existing software won't use the extra lines automatically** (XT software is written
for 8 IRQs, and an XT BIOS only inits one PIC). The benefit is **having enough IRQ lines
to give each device its own**, avoiding sharing — most useful here for **COM3/COM4**,
which otherwise share IRQ4/IRQ3 with COM1/COM2.

To make configurable drivers' "high IRQ" options (sound/net/serial cards) actually work,
wire it **AT-compatible**:

| Item | Requirement |
|---|---|
| Slave ports | **0xA0/0xA1** |
| Slave vector base | **INT 70h–77h** (IRQ8–15) |
| Cascade | slave INT → **master IR2**; CAS0–2 between the two PICs |
| IRQ2 redirect | bus IRQ2 → **IRQ9**, with an **INT 71h → INT 0Ah** BIOS stub for compat |
| BIOS | must initialize the **slave** (ICW1–4, cascade mode, unmask) — add to the XT BIOS |

Caveats:
- Cascading **consumes IRQ2** (it becomes the cascade input) — replicate the IRQ2→IRQ9
  redirect or you break anything expecting IRQ2.
- Software that uses high IRQs is mostly AT-era; *pure* driver code (program PIC + hook
  vector) runs fine on the V20, but anything that checks the machine ID byte or needs
  286/protected-mode features won't.
- Suggested use of the new lines: dedicate IRQs to **COM3/COM4** and the **ISA slot**,
  freeing the low IRQs and ending serial sharing conflicts.

---

## 6. Video controller — CGA + MDA + Hercules, VGA output

**Goal:** "just works" with stock BIOS/DOS — crisp **80×25 text in 16 colors**, plus
CGA color graphics and Hercules mono graphics, displayed on a **VGA** monitor.

### 6.1 Architecture (period core + modern output stage)
- **MC6845 CRTC** — the genuine timing chip CGA/MDA/Hercules all used. Programmed at the
  standard register addresses so the BIOS and software see a real card. Generates
  display memory addresses (MA), row address (RA), HSYNC/VSYNC, display-enable, cursor.
- **Character generator ROM** — CGA 8×8 and MDA 9×14 fonts (in a small EPROM or carved
  from the flash).
- **Serializer / attribute / mode logic in a CPLD** (e.g. ATF1504AS / XC9572XL) — pixel
  shift register, attribute→16-color mapping, blink/underline, mode register, and the
  **SRAM arbiter** (§4.4). Pure-74-series is possible but impractical for all three
  adapters; a CPLD here is the sane choice and keeps the 6845 as the recognizable heart.
- **Shared SRAM** framebuffer via the arbiter.
- **Scan-doubler → VGA**: a line-buffer SRAM captures each native line (~15.7 kHz CGA /
  ~18.4 kHz MDA) and outputs it at **~31.5 kHz** using the **28.636 MHz** dot clock →
  standard **VGA** RGBHV via a resistor-ladder DAC (RGBI→RGB for 16 colors).

### 6.2 Compatibility specifics
- **CGA:** registers `0x3D4/0x3D5` (6845), `0x3D8` mode, `0x3D9` color, `0x3DA` status;
  framebuffer `0xB8000`. Text 80×25 / 40×25 (16 colors); graphics 320×200×4, 640×200×2.
- **MDA:** registers `0x3B4/0x3B5`, `0x3B8` mode, `0x3BA` status; framebuffer `0xB0000`;
  crisp 9×14 mono text.
- **Hercules (HGC):** MDA superset — `0x3BF` config + 720×348 mono graphics in the
  `0xB0000–0xB7FFF` pages.
- Select primary adapter via config DIP (BIOS reads it). The mono (`B0000`) and color
  (`B8000`) windows don't overlap, so both register sets can coexist; the VGA output
  shows the selected one.

### 6.3 Notes / scope
- Because the output is **re-timed through the scan-doubler/line-buffer**, the *internal*
  pixel clock need not be the exact period analog rates (CGA 14.318 / MDA 16.257 MHz) —
  we keep the correct **register interface, memory layout, and active pixel counts** for
  software compatibility and let the doubler produce clean VGA. This sidesteps needing a
  16.257 MHz source for true MDA timing.
- **16-color *graphics*** (EGA/VGA planar modes) is **out of scope for v1** — CGA text
  is 16-color, CGA graphics is 4-color. For real VGA software modes (mode 13h, etc.),
  drop a **period ISA VGA card** in the slot; a native VGA core is a v2 project.

---

## 7. Storage — on-board XT-IDE / CompactFlash
- Replicate the **XT-IDE rev 2 / "Chuck-mod"** 8-bit IDE port with a **high-byte latch
  (74F573 / 74LS652)** so the 16-bit IDE data register is accessed as two 8-bit
  transfers.
- **CompactFlash in True IDE mode.** Many CF cards support **8-bit transfer mode** (ATA
  `Set Features 0x01`), which the **XTIDE Universal BIOS** can use — letting you skip the
  high-byte latch for CF-only builds. Keep the latch for general IDE drive support.
- **I/O base 0x300** (jumperable), boot ROM = **XTIDE Universal BIOS** in flash @
  `0xC8000`. Poll, or wire **IRQ5**.

---

## 8. Serial / parallel / RTC

### 8.1 Serial (multiple COM + TTL console)
- **16C550** UARTs (16-byte FIFO). For several ports use a **dual TL16C552** or quad
  **TL16C554**.
- **COM1 0x3F8/IRQ4, COM2 0x2F8/IRQ3** (more at 0x3E8/0x2E8 if desired).
- **RS-232** via MAX232-class level shifters on COM1/COM2.
- **TTL serial console header (included):** break out **COM1** (or a dedicated UART) at
  5V/3.3V-TTL on a 0.1″ header for headless bring-up before video works — jumper to
  select RS-232 vs TTL.

### 8.2 Parallel (LPT)
- **Discrete** period-style port: **74LS374** data latch + **74LS244/240** status/control
  buffers, decoded at **0x378 (LPT1)**, IRQ7 (usually polled).

### 8.3 RTC
- **DS12885 / DS12C887** (MC146818-compatible) at **0x70/0x71** (DS12C887 integrates
  crystal + battery).
- XT BIOS/DOS doesn't natively use the 70/71 RTC (AT feature) — include a small **RTC
  driver / BIOS hook** to set the DOS clock at boot.

---

## 9. Keyboard, speaker, and audio

### 9.1 Keyboard (XT-style)
- Motherboard side period-correct: **82C55 port A** + **74LS322 (or 164) shift register**
  deserializes the keyboard's serial stream; assert **IRQ1** on a complete scancode.
- Keyboard: a vintage **XT keyboard**, or a **PS/2→XT converter** dongle (the converter's
  micro stands in for the 8048 that always lived inside the keyboard; the motherboard
  stays discrete). Note XT vs AT/PS-2 use **different protocols/scancode sets**.

### 9.2 PC speaker (included)
- **PIT channel 2** tone ANDed with an **82C55 port-B gate bit** → transistor → speaker.

### 9.3 OPL2 FM synth (included)
- **YM3812 (OPL2)** + **YM3014B** DAC at **0x388/0x389** (AdLib standard) — huge DOS
  game/music support.
- **Mix** the OPL2 line output with the PC-speaker signal into a simple op-amp summer →
  **line-out jack** (and/or a small LM386 amp + speaker).

---

## 10. Game / joystick port (included)
- Standard analog **game port at 0x201**: a quad timer (**558/559**) reads the 2-axis
  pots as charge times; two buttons via a **74LS244**. Trivial and period-correct.

---

## 11. Expansion — single ISA slot
- One **8-bit ISA (PC/XT) slot**: buffered A0–A19, D0–D7, 8288 command lines, `ALE`,
  `CLK` (7.16), `OSC` (14.318), `RESET`, routed IRQs, DRQ/DACK, `IOCHRDY`, `IOCHCK̄`,
  `AEN`, power.
- 7.16 MHz `CLK` is in ISA spec (≤8.33). Expose `IOCHRDY` so slow cards can stretch
  cycles; optionally force **4.77 mode** when the slot is in use.
- A period **ISA VGA card** here is the path to true VGA software compatibility (§6.3).

---

## 12. I/O map, IRQ, DMA

### I/O map
| Range | Device |
|---|---|
| 0x000–0x00F | 82C37 DMA |
| 0x020–0x021 | 82C59 PIC |
| 0x040–0x043 | 82C54 PIT |
| 0x060–0x063 | 82C55 PPI (kbd / switches / speaker) |
| 0x070–0x071 | RTC (146818) |
| 0x080–0x083 | DMA page regs |
| 0x080 | **POST code latch** (write) → hex LEDs |
| 0x0A0 | NMI mask |
| 0x201 | Game/joystick port |
| 0x278/0x378 | LPT |
| 0x2E8/0x2F8/0x3E8/0x3F8 | COM4/COM2/COM3/COM1 |
| 0x300–0x31F | XT-IDE |
| 0x388/0x389 | OPL2 (YM3812) |
| 0x3B0–0x3BF | MDA / Hercules |
| 0x3D0–0x3DF | CGA |

### IRQ
| IRQ | Use | | IRQ | Use |
|---|---|---|---|---|
| 0 | Timer | | 4 | COM1 |
| 1 | Keyboard | | 5 | XT-IDE (or polled) |
| 2 | ISA / spare | | 6 | Floppy (opt) / spare |
| 3 | COM2 | | 7 | LPT1 |

### DMA (mostly spare)
| Ch | Use | | Ch | Use |
|---|---|---|---|---|
| 0 | (refresh — unused) | | 2 | Floppy (opt) |
| 1 | ISA / spare | | 3 | spare |

---

## 13. Bring-up aids (build these first!)
- **POST code display (included):** latch port **0x80** writes to a **2-digit hex /
  7-segment** display. The single most valuable homebrew debug tool.
- **TTL serial console header (included):** see §8.1 — get a console before video works.
- **Reset / power-good:** TL7705A + button + 74HC74 sync (§3.3).
- **Config DIP switches** (installed memory, video type) read via 82C55.
- **Logic-analyzer header** on the demuxed bus.

---

## 14. Optional / future
- **8087 math coprocessor socket** — max mode is already in place; socket it, leave empty.
- **Floppy controller** — 82077AA / 8272 + DMA ch2 + IRQ6, if you want period diskettes.
  Skippable (CF boots DOS), and skipping keeps DMA fully vestigial.
- **PSG sound** (SN76489 / AY-3-8910) in addition to OPL2, for chiptune.
- **Network** — 8-bit NE1000-class card in the ISA slot, or just XMODEM over serial.
- **Native VGA** core — v2; for now use an ISA VGA card.

---

## 15. BOM — period part vs. this build

| Function | Period part | This build |
|---|---|---|
| CPU | 8088 | **NEC V20** (or 8088-2) |
| Clock | 8284A + 14.318 xtal | **28.636 MHz osc + 74HC393/161 divider** |
| Reset/power-good | (PSU power-good) | **TL7705A + 74HC74** |
| Bus controller | 8288 | 8288 |
| Address latch | 8282 | 74AHCT573 ×3 |
| Data transceiver | 8286 | 74AHCT245 |
| Decoder | 74LS138 | 74HCT138 |
| PIC / DMA / PIT / PPI | 8259A / 8237A / 8253 / 8255 | **82C59A / 82C37A / 82C54 / 82C55A** |
| DMA page | 74LS670 | 74LS670 |
| RAM | 9× 4164 DRAM + parity | **2× AS6C4008-55 SRAM** |
| ROM | mask ROM / 2764 | **SST39SF010 flash** |
| Video timing | MC6845 | **MC6845** |
| Video logic | discrete 74-series | **CPLD** (serializer + arbiter + scan-doubler) |
| Font | character ROM | EPROM / flash |
| Video output | RGBI to CGA monitor | **scan-doubler → VGA** (resistor DAC) |
| UART | 8250 | **16C550 / TL16C552/554** |
| LPT | discrete TTL | 74LS374 + 244 |
| RTC | (card) MC146818 | **DS12885 / DS12C887** |
| FM audio | (Sound Blaster/AdLib) | **YM3812 + YM3014B** |
| Game port | discrete | 558 + 74LS244 |
| Storage | ST-506 + WD ctrl | **XT-IDE + CompactFlash** |
| Keyboard | 8255 + 74LS322 | same (+ PS/2→XT converter) |

---

## 16. Open decisions / next steps
- **CPU clock duty cycle:** confirm the V20 accepts the ~50% ÷4 clock at 7.16 MHz; shape
  to ~33% if marginal.
- **Arbiter & scan-doubler:** detail the CPLD design (interleave slots vs the 7.16 MHz
  bus; line-buffer sizing; RGBI→VGA timing).
- **Turbo implementation:** clock-mux details and the software-readable speed bit.
- **BIOS:** primary = **Sergey Kiselev's "8088 BIOS"** (GPL) — purpose-built for
  Micro/Xi-8088-class boards and the only mainstream option with **native RTC + CMOS
  setup** (DS12885/DS12C887), which suits the on-board RTC. Fallback = **GLaBIOS** (MIT,
  ultra-compact, max compatibility) — XT-centric, so it'd use **DIP-switch config + an
  RTC TSR** for the clock. (**Super PC/XT BIOS** is a third, turbo-XT option, also
  driver-based for RTC.) Avoid the copyrighted IBM/Phoenix/Award/AMI BIOSes.
  - **Config method:** CMOS-based setup (Sergey's BIOS, AT-style) vs. DIP switches
    (GLaBIOS/Super + RTC driver). Going with the RTC favors the CMOS path.
  - **Storage:** boot via the **XTIDE Universal BIOS (XUB)** as a separate option ROM at
    flash bank 1 @ `0xC8000` (Sergey's BIOS can integrate XUB into one image).
  - **Video BIOS:** custom, flash bank 1 @ `0xC0000`, for non-CGA/MDA modes. CGA/MDA
    register compatibility means the stock system-BIOS video init works as-is.
- **Flash protection:** software data protection + program-enable jumper.
```

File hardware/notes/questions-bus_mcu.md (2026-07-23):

# Open questions -- bus_mcu sheet

## Q1. §4.2 (address-group transceivers) vs §5.1 (external address counter): who drives A0-A19 in master cycles?
- Why: §4.2 says the Bus MCU needs *bidirectional* transceivers on the address
  group "because when it owns the bus it must drive A0-A19." §5.1 says the
  20-bit address is offloaded to an external loadable 74HC163 counter so the MCU
  never drives an address line directly. Both can't literally drive the bus.
- Options:
  (a) Counter drives A0-A19 directly onto the bus; no address transceivers.
  (b) Address transceivers only (no counter), MCU drives 20 GPIO -- blows the pin budget.
  (c) Both present: counter is the master-cycle address *source*; the §4.2
      address-group '245s are the 3.3V<->5V boundary (DIR = BUSDIR) so the MCU
      can sense the low address bits as a slave and the counter outputs reach the
      backplane through buffers gated by bus role.
- Pick: (c). Counter outputs label the bus A0-A19 nets; three 74LVC245A address
  transceivers (U3/U4/U5) bridge MCU-side MA0-MA19 to bus A0-A19 with DIR=BUSDIR.
  Only the low byte (MA0-MA7) is tapped by the MCU (GPIO8-15) for 8-bit I/O
  decode (§5.2 allows A0-A7 + an external COM3 gate). This honors both sections.

## Q2. Transceiver direction nets: one BUSDIR or separate per group?
- Why: §5.2 lists "Transceiver DIR -- master/slave, 0-1 pins, can be HLDA-derived
  externally." Data direction, however, flips with read vs write *within* a slave
  cycle, not just with bus role.
- Options: (a) single BUSDIR on all '245s; (b) BUSDIR (role) on addr+control,
  a separate DATADIR (read/write) on the data '245.
- Pick: (b). BUSDIR (role, = HLDA-derived) steers the address + control '245s;
  DATADIR (cycle read/write) steers the data '245. Both are driven by the MCU
  here (GPIO42=BUSDIR, GPIO43=DATADIR); on the board BUSDIR can instead be a
  cheap external gate off HLDA as §5.2 notes.

## Q3. '245 output-enable (CE) gating.
- Why: real master/slave arbitration gates the transceiver OE with AEN/HLDA so
  only one side drives the backplane at a time.
- Pick: tie CE (active-low OE) of all '245s to GND (always enabled) for schematic
  clarity; note that the board gates CE with AEN/bus-role. Multiple drivers on the
  shared A/D nets are expected and resolve at the root harness.

## Q4. IRQ collector width -- one '165 only covers 8 of 14 IRQ lines.
- Why: the interface carries IRQ2..IRQ15 (14 lines); a single 74HC165 has 8
  parallel inputs. §5.2 says ~10-12 lines / 2-3 pins.
- Pick: per the task ("one 74HC165"), wire IRQ2..IRQ9 to the single '165 (U12);
  its serial input DS is left for a cascaded second '165 (IRQ10..IRQ15) that the
  board adds without new MCU pins (DS chains '165s). Logged as a known gap.

## Q5. RP2350B core supply (DVDD) vs the "tie VDD to +3V3" instruction.
- Why: IOVDD/QSPI_IOVDD/USB_OTP_VDD/VREG_VIN/*AVDD are genuine 3.3V rails, but
  DVDD is the 1.1V core, normally fed by the on-chip switcher (VREG_VIN->VREG_LX
  ->L->DVDD, sensed by VREG_FB).
- Pick: tie the 3.3V rails to +3V3 and GND/VREG_PGND to GND as instructed; keep
  DVDD on its own net (DVDD pins + VREG_FB) with a decoupling cap, and label
  VREG_LX separately, rather than shorting the 1.1V core onto +3V3.

## Q6. Level shifting of the private V20<->MCU handshake (HOLD/HLDA/INTR/.../RD/WR).
- Why: these are 3.3V GPIO <-> 5V V20 signals but are not part of the buffered
  ISA group, so they don't pass through the bus '245s.
- Pick: route them directly to GPIO with their canonical net names (interface
  visible); note that the board adds a small fixed-direction '245 / 5V-tolerant
  buffering for them. IO/~{M} exceeds the 48-GPIO budget so it is exported as a
  hier pin only (not bonded to a GPIO here); the MCU infers cycle type from the
  buffered ~{MEMR}/~{IOR} strobes instead.

## GPIO22: CLK sense -> SPKR (design review 2026-07-11)
The audio sheet's SPKR net had NO driver anywhere (netlist: 1 node) -- the
soft-PIT ch2 speaker output was never brought out and the GPIO budget was
48/48. GPIO22 (bus-CLK sense, a diagnostics bonus from the C3 fix round, not
load-bearing: PIO tracks cycles from BALE/strobes) is reassigned as the SPKR
output, giving full port-61h direct-toggle fidelity from the PIT owner.
bus_mcu no longer lists CLK in its interface.

## Decoupling + spare-input cleanup (2026-07-11)
C8 was decoupling +3V3, a rail this sheet doesn't use -- now 3V3_BUS (typo).
Added C12-C17 (the +5V '244/'04 stage and the counter/xcvr banks had none or
shared one). U17 spare inverter inputs tied to GND (no_connect left them
floating on the real chip).

## Module-USB flashing made safe (2026-07-11)
The Core2350B's vendor schematic shows a single VBUS net -- no diode between
its on-module USB connector and the VBUS pin -- so the old direct +5V tie
meant plugging a PC in would back-power the whole board (board off) or
parallel two hard 5V supplies (board on). D1 (SS34) now feeds the module
Pico-style (+5V -> anode, VBUS_MCU -> cathode); the ME6217 LDO has ample
headroom at ~4.7 V. R16-R18 park DATADIR (B->A), M_TC (low) and HLDA (low)
while the MCU is Hi-Z in BOOTSEL/reset, so the always-enabled U2/U13
shifters can't drive the 5 V bus with indeterminate levels during flashing.

## IRQ collector extended to 16 bits (2026-07-11)
U19 (74HCT165) cascades into U12's DS, sampling IRQ10-IRQ15 (R19-R24 idle
pull-downs). Costs zero GPIO -- same IRQ_LOAD/IRQ_CLK/IRQ_SER, firmware
shifts 16 bits instead of 8. Motivation: the on-board storage now straps to
IRQ14 (AT primary-IDE convention) by default, which previously had no
physical path into the soft-PIC; this also un-dangles the IRQ10-15 pins the
sheet interface had declared all along. These lines are motherboard-internal
(the 60-pin header carries only IRQ2-8).
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

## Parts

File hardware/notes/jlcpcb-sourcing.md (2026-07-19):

# JLCPCB sourcing — 2026-07-03 (updated 2026-07-14: 3.3V single-board redesign)

Every component in the design was checked against the JLCPCB parts database.
The authoritative machine-readable result is `tools/parts.py` (the (lib_id,
value) → LCSC map that build.py applies as `LCSC Part Num` properties); this
file records the decisions and the things a human must re-check at order time.

**2026-07-14 update:** the board's internal bus moved to 3.3V (one PCB, V20's
own demux stage is now the sole 5V↔3.3V boundary; see
`docs/superpowers/specs/2026-07-14-3v3-single-board-design.md` and
`hardware/notes/3v3-verification.md`). This deleted several of the HCT
substitution rows below (their only use was removed with the DS12C887/
AS6C4008 parts) and added a new set of LVC-grade picks — see "3.3V redesign —
new/changed parts" below. The tables in this file were edited in place; rows
that are still live in the current sheets are kept, dead ones are removed.

## Custom-symbol pin verification (open-questions Q5 — RESOLVED)

Verified against JLCPCB/EasyEDA symbol data and the Maxim datasheets:

- **MAX3241** (MAX3241EEAI+T, LCSC C406859, SSOP-28): the original
  best-effort symbol was wrong on essentially EVERY pin (only C2+ matched),
  and used MAX3243-style pin names. The real part has `SHDN#` (22, tie high
  to run), `EN#` (23, tie LOW to enable receiver outputs), and two
  always-active receiver outputs `R1OUTB`/`R2OUTB` (21/20, NC here).
  Symbol regenerated; com_port.py rewired (~FORCEON→~EN is a polarity fix:
  it must be GROUNDED, where the old ~FORCEON was tied high).
- **DS12C887** (DS12C887+, LCSC C9869, EDIP-24): four pins were wrong —
  DS is 17 (was 16), RESET# 18 (was 17), IRQ# 19 (was 18), SQW 23 (was 21).
  Symbol regenerated; rtc.py wiring is by pin NAME so it followed along.
  **Removed 2026-07-14** (3.3V redesign, decision #4): the RTC is now
  emulated in the Bus MCU + a PCF8563 I2C RTC on the Supervisor; the
  `rtc.py` sheet, the DS12C887 symbol (`gensym.py`), and this socket/chip
  pick are all gone. Kept here as history only.

## Stock-forced substitutions (all same-pinout, netlist-verified)

Rows still live in the current (3.3V, single-board) design:

| Wanted | Not stocked → used | LCSC | Why it is safe |
|---|---|---|---|
| 74HCT163 | 74HC161 (bus_mcu address counter, card_isatest) | C5610 | same pinout; async ~MR tied inactive; 3.3V-domain part, no cross-voltage concern |
| 74HCT157 | 74HC157 (clock mux, now 3.3V-powered)  | C5609 | direct 3.3V select drive — no HCT-inverter stage needed any more (§3.2) |
| TCM809 | TCM809TENB713 | C47195 | same family/SOT-23 pinout, **-T grade, 3.08 V threshold** — correct for the 3.3V rail it now monitors (was wrongly bound to the 4.375V -450I/TT grade; fixed Task 10, see Q9 in questions-cpu_core.md) |
| 2N3904 | MMBT3904 | C20526 | SMD version of the same die |
| TL072→MCP6002 | (already swapped, H6)  | C7377 | RRIO, pin-identical |
| 1.8432 MHz XO | crystal on the UART's XIN/XOUT | C47345430 | canned XOs at this frequency are 3.3 V-only; now drives the TL16C550CPFBR's crystal pins instead of the old 16C550's |

**Dead as of the 3.3V redesign (rows removed):**
- **74HCT374 → 74HCT574** (C6001): the LPT data latch (parallel.py) moved
  again, from 74HCT574 to **74LVC574A** (3.3V) — see the new-parts table below.
  The 74HCT574 (C6001) PART_MAP entry is kept in `parts.py` but is now
  unreferenced by any sheet.
- **74HCT02 → 74HC02** (C5588): its only use was the RTC's ISA decode, which
  is deleted along with the RTC sheet. `parts.py` keeps the mapping (harmless,
  unreferenced) in case a future sheet needs plain 3.3V-domain 74HC02.

**RESOLVED (Task 10):** the TCM809 substitute was bound to MCP809T-450I, a
**4.375 V** reset threshold chosen when the part monitored the **5V** rail.
`cpu_core.py`'s reset supervisor runs on **+3V3**, so a 4.375V threshold could
never be satisfied by a healthy 3.3V rail — the supervisor held reset
permanently, and the board could never start. Rebound to **TCM809TENB713**
(C47195, real TCM809-family part, SOT-23, **3.08 V** threshold, stock 94):
3.08V sits safely below a 3.3V rail at -2% regulation tolerance (3.234V) with
~150 mV of margin, while still tripping well above ground. See
`hardware/notes/questions-cpu_core.md` Q9 for the full margin arithmetic.

**HC-at-3.3V-vs-5V voltage-domain rule (superseded picture):** the old
"plain 74HC at 5V cannot read a 3.3V high" caveat drove several of the
substitutions above; with the board now almost entirely 3.3V, that specific
cross-voltage hazard mostly disappeared (everything HC-grade left in the
design is 3.3V-powered with 3.3V-driven inputs). The remaining voltage-domain
hazard is the opposite one: **plain HC/HCT parts don't meet fmax margin at
3.3V** for the fastest signal in the design (the 14.318 MHz clock dividers) —
see the LVC picks below.

## 3.3V redesign — new / changed parts (2026-07-14)

Picks confirmed live via `jlc_search`/`jlc_get_part`/`jlc_stock_check`
(research: `hardware/notes/3v3-verification.md`). "Stock" is the count at
query time; **thin** flags anything to re-check before ordering.

| Role | MPN | LCSC | Package | Stock |
|---|---|---|---|---|
| SRAM 512K×16 (replaces 2× AS6C4008)  | IS62WV51216BLL-55TLI | C11315 | TSOP-II-44 | 1913 |
| Octal latch, 3.3V, 5V-tol (cpu_core address latches) | 74LVC573APW,118 | C6096 | TSSOP-20 | 18,681 |
| Octal xceiver, 3.3V, 5V-tol (cpu_core data, sidecar) | 74LVC245A (existing symbol/value) | — | — | see existing `parts.py` entry |
| Octal buffer, 3.3V, 5V-tol (sidecar) | 74LVC244APW,118 | C6079 | TSSOP-20 | 23,742 |
| Octal D-FF (parallel.py LPT latch, was 74HCT574) | 74LVC574AT20-13 | C842658 | TSSOP-20 | 88 **thin** |
| Quad tri-state (cpu_core U11/U15, addr_decode IRQ driver) | 74LVC125AD,118 | C6057 | SOIC-14 | 17,935 |
| Dual open-drain (sidecar IOCHRDY/IOCHCK̄) | 74LVC2G07GW,125 (2G06 body, value override) | C24478 | SOT-363-6 | 6,631 |
| ÷2 clock divider (cpu_core U8, was 74HCT74) | 74LVC74APW,118 | C6100 | TSSOP-14 | 7,807 |
| ÷3 clock divider (cpu_core U9, was 74HC161) | 74LVC161PW,118 | C548136 | TSSOP-16 | 100 **thin** |
| UART ×2 (replaces socketed 16C550) | TL16C550CPFBR | C882798 | TQFP-48 | 5 **thin — verify** |
| I2C RTC (Supervisor, battery-backed) | PCF8563T/5,518 | C7440 | SO-8 | 166,556 |
| CR2032 holder (Supervisor) | CR2032-BS-6 | C22363833 | SMD | 13,541 |

Notes:
- 74HC00 (SRAM `/CE` inverter + LPT NAND, re-bought for the 3.3V domain), 74HC04, 74HC32,
  74HC125, 74HC138, 74HC244, 74HC245 also got fresh 3.3V-domain LCSC picks in this pass
  (smaller-name fabs — MDD/Toshiba — since Nexperia-branded parts are thin/unstocked at
  those values); see `parts.py` for the exact entries, unchanged pinouts throughout.
- 74LVC161 and 74LVC574A are both thin (100/88 units) — re-check immediately before BOM
  lock, same as the existing TL16C550/MAX3241/TPS563200 thin-stock flags below.

## Socket policy (fab installs the socket, chip goes in by hand)

**2026-07-14 update:** the socket list shrank to the **V20 only** — the
AS6C4008 SRAM sockets are gone with that chip (→ IS62WV51216BLL SMD TSOP-44,
no socket) and the DS12C887 socket is gone with that chip (→ RTC emulated
+ SMD PCF8563). The COM UARTs also dropped their PLCC-44 socket: the
TL16C550CPFBR is a soldered TQFP-48 reflow part (thin JLC stock, C882798;
still not socketed).

| Component | Socket (= its LCSC Part Num) | Chip source |
|---|---|---|
| V20 (µPD70108) | DIP-40 **machined** socket C2874018 | user stock (vintage) |
| Core2350B module ×2  | 2.54 mm female headers C2897411 | Waveshare (consign) |
| Pico module | 2.54 mm female headers C2897411 | Raspberry Pi — official Pico stocked at JLC (C7203002, ~$8; Pico W C7203003) |

**Header caveat (found 2026-07-13):** C2897411 is specifically the
PM254-2-10-Z-8.5, a **2×10** female strip. That suits the Core2350B's
dual-row rings, but the Pico needs 2× **1×20** strips — pick a 1×N part
(same PM254 family) at order time.

Module mounting (verified 2026-07-03 from the photos in
`hardware/Core2350B0-details-size.jpg` / `-inter.jpg`):
- **Core2350B has NO castellated edges** — it is a 25.4 × 25.4 mm
  double-ring through-hole PGA (two concentric 2.54 mm rows, 22.86 mm inner
  span, ~6 GND holes). It MUST mount on headers: one dual-row 2×N female
  strip per side covers both rings. Holes are silk-labelled by signal name
  (no canonical pin numbering), so the symbol's pin numbers are
  project-defined and the layout footprint must be authored to match them.
  Photos also confirm HSTX = GP12–19 and PSRAM CS = GP47, as the design
  assumes.
- **The Pico IS castellated** and JLC stocks the official module
  (C7203002), so the test card's Pico could alternatively be reflowed
  flat as an SMD part (confirm assembly eligibility of the dev-board
  category at quote time, or consign). Currently still on female headers.

The V20's DIP-40 socket is the machined-pin (round-hole) grade, verified
600 mil (15.24 mm) row spacing — ~$0.70–0.90 vs $0.06–0.12 stamped, worth it
for a vintage pin and repeated insertion. (Stamped fallback if the machined
part goes out of stock: C2332. The DIP-32/DIP-24 machined-socket picks for
the now-deleted AS6C4008/DS12C887 sockets — C2874017/C2684765 — are kept
here only as history; beware many catalog DIP-24/32 sockets are the NARROW
300 mil variant if either part ever comes back.)

**16550 socket choice — HISTORICAL (2026-07-03), superseded 2026-07-14:** the
board no longer sockets its UARTs. The original rationale (swappable UART for
~$0.39 + ~2 cm² per port, one footprint taking new TI silicon / NOS tubes /
vintage pulls) applied to a PLCC-44 16C550; the 3.3V redesign moved both COM
ports to a soldered 48-pin QFP instead (TL16C550CPFBR, C882798, since later
that day — thin JLC stock, see the thin-stock list below).

## Not available at JLCPCB (source elsewhere / consign)

- ~~**8-bit ISA card-edge slot** (card_isatest J1)~~ — parts.py entry retired
  2026-07-14 with the card_isatest dev card. The planned ISA backplane board
  will want these again: 3.96 mm edge connector, consign or CONNFLY/EDAC from
  another distributor.
- **VGA HD15 (DE15) connector** (video sheet) — THT part from another
  distributor, or build the video output HDMI-only initially.
- **16C550 UART — RESOLVED (2026-07-14, later), moved to the thin-stock
  list.** The LQFP-48 PT revisions (TL16C550CPTR C181382, PTRG4 C2653207)
  remain at **0 units**, but the active **TL16C550CPFBR** (TQFP-48,
  **C882798**, 5 in stock, extended part) is pin-identical — verified
  against EasyEDA/`jlc_get_pinout` for C882798, all 48 pins including the 8
  NCs — and is now bound in `parts.py`. Still a **soldered SMD reflow part,
  not socketed**. A socketed PLCC-44 fallback (TL16C550CIFNR, C2653193)
  exists if a future revision wants sockets back.

## Network card (2026-07-12) — REMOVED 2026-07-14

The RTL8019AS NE2000 NIC and its whole sourcing tree (RTL8019AS C22465363,
AT93C46 C6499, 13F-39MNL magnetics C115949, RJ45 C386757, plus the
NIC-only passives 27k/1M/200R/20pF/1nF/1nF-2kV and the 20 MHz crystal)
were removed from the board on 2026-07-14. Git tag **`full-board-with-nic`**
preserves the last design with the full sourcing detail this section held.

## Passives audit (2026-07-14) — basic-library sweep + resistor arrays

Every discrete R and C value on the board audited against the JLC library:
all were already **basic** (the 27R USB terminator is "preferred" = also
fee-free) except three, resolved as follows:

- **Ferrite beads (picogus AVDD; was x3 incl. the removed NIC)**: extended Murata
  BLM18KG101TN1D (100R@100MHz) -> **basic BLM18PG121SN1D, C14709**
  (120R@100MHz, 2A) -- same family/role, fee-free.
- **100uF SMD electrolytic (power, x2, C2887276)** and **2.2uH/4.8A buck
  inductor (power, C602029)**: stay extended -- JLC's fee-free library
  contains ZERO parts in either subcategory. Accepted cost of the buck.
- Pruned the orphaned 47nF/330nF entries (5V-era MAX3241 caps, unused
  since the 3.3V redesign).

**Pull consolidation**: 65 discrete 10k/4.7k rail pulls collapsed into 18
**basic** 4-element isolated arrays (RN refs): 10kx4 = 4D03WGJ0103T5E
C29718, 4.7kx4 = 4D03WGJ0472T5E C1980 (0603x4, R_Array_Convex_4x0603,
element k = pins k/9-k). Isolated elements, so packs mix rails; +-5%
tolerance is fine for pulls. Kept discrete: RC/divider/series roles, the
supervisor I2C pair + RUN, and singletons.

- **10k discrete moved to 0805 (C17414, 0805W8F1002T5E)** 2026-07-16: the
  0603 line (C25804) hit 0 stock and was the ONLY basic 10k 0603; still dry
  at recheck, and no other basic 10k 0603 exists at any tolerance. C17414 is
  basic, +-1%, 11.9M stock. The board's one deliberate 0805-resistor
  deviation from the 0603-passives rule (the ~10 remaining discrete 10k are
  pulls/dividers/RC -- footprint size is irrelevant there). Swap back to a
  0603 line in parts.py if one returns to the basic library.

## Thin stock — re-verify with jlc_stock_check before ordering

- **TL16C550CPFBR (C882798): 5 units — genuinely thin**, extended part;
  re-verify with `jlc_stock_check` before every order (fallback: TI
  direct/Mouser, where the PFB channel is healthy). Avoid eBay/AliExpress
  "16550" pulls — widely remarked/fake. 48-QFP pin numbers differ from the
  old PLCC/DIP-style symbol assumption — the `mini-xt:TL16C550PT` symbol
  uses TI's NO.PT column (SLLS177I Table 4-1), re-verified pin-for-pin
  against `jlc_get_pinout` for C882798 (PT and PFB share the pinout).
- DB25 female: swapped 2026-07-16 to Ckmtw D-DMR025PF-D002 (C190083, ~6.8k
  stock, $0.85) from Amphenol DB25S564CTLF (C5400534, ~10 pcs). Same D-DMR
  series as the DE9. Footprint corrected to the DSUB-25 **_Socket_**
  (female) variant — the old binding used _Pins_ (male), which mirrors the
  pin positions on a female shell.
- MAX3241EEAI+T (C406859) → **swapped to SP3243EUEA-L/TR (C916165) 2026-07-19**
  (hit 0 stock 2026-07-15, restocked to only ~645 by 07-19 — chronically thin;
  the SP3243E sits at ~6.7k and $1.17 vs $3.33). MaxLinear's 3243 is the
  multi-source 3T/5R pinout; EasyEDA pin tables compared pin-for-pin: 1–20 and
  24–28 identical, and the control straps land right — pin 22 SHUTDOWN# (=
  SHDN#) to +3V3, pin 23 ONLINE# to GND = forced always-on (auto-powerdown
  bypassed), pins 20/21 R2OUT#/STATUS# unused outputs, NC. Same SSOP-28-208mil
  footprint, same 4×100nF cap set at 3.3V. Sheet change is the value override
  only; the MAX3241 remains a drop-in alternate. (TI's MAX3243 is NOT a
  strap-compatible drop-in: its pin 23 is active-HIGH FORCEON, so our GND
  strap would leave it in auto-powerdown mode, which can eat the first byte
  after 30 s idle — it would need the strap moved to +3V3.)
- TPS563200DDCR (C97253) → **swapped to TPS563201DDCR (C116592) 2026-07-19**.
  The '3200 kept dipping to unorderable levels (4 pcs on 2026-07-11; it later
  restocked to ~2.5k, but the '3201 sits at ~90k and ~$0.07). Verified against
  both datasheets: same DDC (TSOT-23-6) pinout, same D-CAP2 topology, same
  0.768 V VFB reference — the 33k/10k divider and cap set carry over unchanged.
  (An earlier version of this note guessed "different feedback network" — not
  so; 580 kHz vs 650 kHz switching is the only functional delta, plus Eco-mode
  light-load behavior matching the '3200's.)
- **74LVC161PW,118** (C548136, ÷3 clock divider): ~100 pcs. **74LVC574AT20-13**
  (C842658, LPT data latch): ~88 pcs. Both new 2026-07-14 picks — re-verify
  before BOM lock.

## Other design changes made during sourcing

- **Supervisor QSPI flash is now a real W25Q128JVSIQ (C97521, basic)** —
  the placeholder 8-pin header could never boot the RP2040.
- 12 MHz crystal C9002 (CL = 20 pF): the 15 pF load caps (C1644) should be
  revisited against the crystal's CL at layout (≈2×(CL−Cstray) suggests
  more like 27–33 pF).
- 22 µF bulk caps: MLCC (C12891) replaces the polarized symbol's implied
  electrolytic.
- LEDs: KT-0603R (C2286) for both rail indicators.
- All jumpers/headers are cut-to-length 2.54 mm breakaway strips
  (C2337 1×40, C2333 2×40); the CF socket is a real SMD CompactFlash
  connector (C2962036) whose footprint replaces the generic 2×25 header at
  layout.

## Design-review additions (2026-07-11)

Protection + best-practice parts added by the 2026-07-11 review:

| Part | LCSC | Where |
|---|---|---|
| BSMD1812-200-16V 2A hold | C883156 | sidecar +5V_ISA feed fuse |
| BSMD1812-300-24V 3A hold | C7500481  | power USB-C VBUS input fuse |
| SMBJ5.0A TVS (SMB) | C19077558 | +5V clamps: power input, sidecar, isatest |
| USBLC6-2SC6 (SOT-23-6) | C2687116  | supervisor USB-A ESD array |
| 2N7002 (SOT-23) | C8545 | storage IRQ5 tri-state inverter |
| 27R 0603 (0603WAF270JT5E)  | C25190 | supervisor USB series termination |
| 100R 0603 | C22775 | VGA sync series, audio output series |
| 47nF 0603 | C1622 | MAX3241 C1 (5V values) |
| 330nF 0603 | C1615 | MAX3241 C2-C4 (5V values) |
| 100uF alu SMD 16V | C2887276  | supervisor USB host VBUS bulk |

STOCK ALERT (resolved 2026-07-19): TPS563200DDCR hit 4 pcs at JLC on
2026-07-11; the board now uses TPS563201DDCR (C116592, ~90k stock) instead —
same pinout/topology/0.768V ref, divider unchanged. See the entry above.

No JLC-stocked/KiCad-symboled TMDS ESD array was picked for the video card's
HDMI pairs (TPD4E05U06-class, <=0.15pF/line) -- choose at layout time.

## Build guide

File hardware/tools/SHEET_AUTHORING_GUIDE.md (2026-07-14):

# mini-xt sheet authoring guide

You are implementing **one** KiCad hierarchical sub-sheet for the mini-xt
XT-class MCU-SBC, by writing a Python builder in `hardware/sheets/<name>.py`.
The build harness turns it into a valid `.kicad_sch`. Read this whole file first,
then study `hardware/sheets/cpu_core.py` — it is the worked reference example.

## The design

The full design is `docs/xt-mcu-sbc-design.md`. Read the sections relevant to
your sheet. The organizing idea: the **buffered 8-bit XT/ISA bus is the
integration contract**; soft cards talk only standard ISA signals, motherboard
nodes may use private side channels. Your sheet exposes its interface as
hierarchical pins so the isolation is visible.

## How a sheet module looks

```python
import mxbus
from mxbus import pin

NAME  = "com_port"
TITLE = "Serial port -- TL16C550CPT + MAX3241"
PINS  = [ ... list of mxbus.pin("NETNAME", "direction") ... ]   # the interface

def build(sch, lib):
    mxbus.emit_interface(sch, PINS, at=(25.4, 25.4))   # declares the hier pins
    U1 = sch.place("mini-xt:TL16C550PT", "U1", at=(101.6, 101.6))
    # ... place parts, wire them ...
```

(There is no `rtc` sheet any more -- the 2026-07-14 3.3V redesign deleted it;
the RTC is emulated in the Bus MCU with a PCF8563 on the Supervisor. Use
`hardware/sheets/com_port.py` or `hardware/sheets/cpu_core.py` as worked
examples instead.)

`PINS` is the sheet's interface (becomes the sheet symbol's pins at the root, and
ties to identically-named pins on other sheets). `emit_interface` drops one
hierarchical label per pin. You then wire component pins to those nets **by
name** with local labels.

## The connectivity model (IMPORTANT)

Connectivity is **by net name**, never by drawing wires between far-apart pins.
The one call you use constantly:

```python
sch.net(comp, pin, "NETNAME", kind="label", dx=2.54, dy=0)
```

This stubs a short wire off `comp`'s pin `pin` and attaches a label "NETNAME".
Any other pin labeled "NETNAME" on this sheet joins the same net. Use:
- `kind="label"` for internal nets AND for interface signals (the matching name
  in `emit_interface` makes it cross-sheet). This is what you want ~always.
- `dx`/`dy` choose stub direction: `dx=-2.54` left, `dx=2.54` right (default),
  `dy=-2.54` up, `dy=2.54` down. Pick a direction that doesn't overlap the body.

`pin` may be the pin **number** ("13") or its **name** ("AD0", "~{IRQ}").
Use `python3 tools/pins.py <Lib:Name>` to list a symbol's pins.

Power: `sch.net(c, "VCC", "+5V", kind="label", dx=0, dy=-2.54)` and likewise
"+3V3"/"GND". Power nets are global; just label them.

Unused pins: `sch.no_connect(comp.pin_xy("PINNAME"))`.
Free text: `sch.text("note", (x, y))`.

## Rules that keep ERC clean

1. **Place every component on the 2.54 mm grid** (coords like 101.6, 152.4,
   76.2 ...). The harness snaps to 1.27 mm but stay on 2.54 to be safe.
2. **One net = one name.** Do not put two different labels on the same pin.
3. Active-low signals use overbar syntax: `"~{MEMR}"`, `"~{IOR}"`, `"~{CS}"`.
   A slash in a name is written literally: `"IO/~{M}"`, `"R/~{W}"`.
4. Use the **canonical names from `mxbus`** for every shared signal (see below).
   A typo'd name silently fails to connect across sheets.
5. Lay parts out with ~40-60 mm spacing so labels don't collide. A3 sheet is
   ~420x297 mm.

## Canonical signal names (from `mxbus`, use these EXACTLY)

- Address: `mxbus.ADDR` = `A0`..`A19`   (bus group `A[0..19]`)
- Data:    `mxbus.DATA` = `D0`..`D7`
- IRQ:     `mxbus.IRQ`  = `IRQ2`..`IRQ15`
- Control: `~{MEMR} ~{MEMW} ~{IOR} ~{IOW} BALE AEN IOCHRDY ~{IOCHCK}
  RESET_DRV CLK OSC TC DRQ1 DRQ2 DRQ3 ~{DACK1} ~{DACK2} ~{DACK3}`
- Power:   `+5V +3V3 GND`
- Private (motherboard-only): `mxbus.PRIV_CPU`, `PRIV_COUNTER`, `PRIV_LINK`
  (`LINK_B2S`,`LINK_S2B`), `PRIV_SUPER`, `PRIV_SPEED` (`SPEED_SEL`).

Only declare in `PINS` the signals your sheet actually uses. A soft card (video,
com, lpt, storage, sidecar, audio, picogus, network) should still use **only
ISA signals + power** — private names are a guideline violation, not a hard
error, since the 2026-07-14 3.3V redesign downgraded this from a schematic
rule to a firmware-portability guideline (the whole internal bus is one 3.3V
net now). If you think you need a private name, log a question instead.

## Finding symbols

`python3 tools/pins.py -s <substr>` searches names; `python3 tools/pins.py
<Lib:Name>` lists pins. Custom parts live in `mini-xt:` (V20, MAX3241,
IS62WV51216, TL16C550PT, PCF8563, Core2350B, Pico,
and flat glue 74HC00/02/04/08/32/74/125/138/157/163/165/244/245/573/574).
Standard KiCad libs available: Device, power, Connector, Connector_Generic, 74xx,
Interface_UART, Interface_USB (CH224K, USB_C), Interface_LineDriver,
MCU_RaspberryPi (RP2040, RP2350B), Oscillator,
Regulator_Switching/Linear, Power_Supervisor, Audio (PCM5102), Amplifier_Operational,
Connector (HDMI_A, DE9_*, DB25_*, USB_C_Receptacle). If a part is missing, pick the
closest standard symbol and log a question.

## Validate your work (run repeatedly)

```
cd /home/andrew/repos/mini-xt
python3 hardware/tools/validate_sheet.py <name>
```

Must be **zero**: `endpoint_off_grid`, `unconnected_wire_endpoint`,
`multiple_net_names`, and any "Failed to load". EXPECTED (ignore): big counts of
`pin_not_connected` / `pin_not_driven` / `label_dangling` (hierarchical pins and
unused chip pins look unconnected in isolation — they resolve at the root), and
`lib_symbol_issues` (just "lib not in config" for the CLI).

## Logging questions

When the design under-specifies something, do NOT stop. Write your best-guess
decision to `hardware/notes/questions-<name>.md` (question, why, options,
your pick) and proceed with your pick. One file per sheet (avoids write races).

## Scope / fidelity

Interface-focused: place the real ICs and the key supporting parts, wire the
important nets and every interface signal, add representative decoupling. You do
NOT need every passive or perfect pin-level completeness — clarity of the
module's interface and internal structure is the goal. Aim for ~10-30 components.

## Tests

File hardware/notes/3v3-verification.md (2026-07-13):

# 3.3V single-board redesign — plan-stage verification

Research for `docs/superpowers/specs/2026-07-14-3v3-single-board-design.md` §"Plan-stage
verification checklist". Pure research, no sheet edits. Consumed by Task 2 onward.

All seven checks: **7/7 PASS** in the sense that none blocks the redesign — but checks 1
and 7 turn up two concrete part/wiring corrections downstream tasks must apply (below).

---

## Check 1 — µPD70108 (V20) DC characteristics: Vih, CLK, RESET

**VERDICT: PASS**, with a correction to the design doc's assumption.

Source: NEC `IC-3552A` data sheet for the µPD70108H/70116H (V20HL/V30HL — CMOS
re-spin of the plain V20; NEC's own "Differences" table confirms only *operating
frequency/voltage* differ between the H and non-H parts, not pin electrical
structure, so its DC table is the best primary source available online for the
V20's input thresholds; the plain non-H datasheet's electrical tables were only
available as non-OCR-able scans). §9.1 "WHEN VDD = 5V ± 10%", DC CHARACTERISTICS
table (p.82):

| Symbol | Conditions | Min | Max |
|---|---|---|---|
| Vih | Other than (1) READY, (2) HLDRQ | **2.2 V** | Vdd+0.5 |
| Vih | (1) READY | 0.6·Vdd (=3.0V) | Vdd+0.5 |
| Vih | (2) HLDRQ (DIP only) | 0.6·Vdd (=3.0V) | Vdd+0.5 |
| Vil | all | −0.5 | 0.8 V |
| **Vkh** (CLK input high) | — | **0.8·Vdd = 4.0 V** | Vdd+1.0 |
| Vkl (CLK input low) | — | −0.5 | 0.15·Vdd |

**RESET is not listed as an exception** — it uses the general-input Vih = 2.2V min,
*not* the clock-input class (Vkh). A 3.3V LVC output (Vout high comfortably ≥2.4–3.0V
even loaded) clears 2.2V with margin, so **RESET can be driven directly from 3.3V
logic — it does NOT need the 5V HCT04 buffer**, contradicting the design doc's
hedge ("RESET if flagged"). Only **CLK** needs the buffer: Vkh min = 0.8×5V = 4.0V,
unreachable from a 3.3V rail (max 3.3V < 4.0V). This confirms the design's one
5V HCT04 package is sized correctly (CLK only) and identifies a small simplification
(RESET can lose its buffer gate) for whichever task wires reset distribution.

Datasheet: NEC IC-3552A (µPD70108H/70116H), fetched via
`https://docs.rs-online.com/8dd4/0900766b8002a664.pdf`-equivalent mirror
(`datasheets.chipdb.org/NEC/V20-V30/IC-3552A.PDF`), §9.1 p.82, §1 differences table p.10.

---

## Check 2 — IS62WV51216BLL-55TLI: byte-lane trick + 0-wait timing at 7.16 MHz

**VERDICT: PASS.**

**LB̄/UB̄ gate the output drivers (byte-lane trick is valid).** ISSI datasheet
(`https://www.issi.com/WW/pdf/62WV51216ALL.pdf`, TRUTH TABLE p.3) Read rows:

| WE̅ | CS1̅ | CS2 | OE̅ | LB̅ | UB̅ | I/O0-7 | I/O8-15 |
|---|---|---|---|---|---|---|---|
| H | L | H | L | L | H | D_OUT | High-Z |
| H | L | H | L | H | L | High-Z | D_OUT |
| H | L | H | L | L | L | D_OUT | D_OUT |

Deasserting LB̅ (high) forces I/O0-7 high-Z regardless of CS/OE state; same for UB̅
on I/O8-15. This is exactly the mini-xt scheme: **A0 → LB̅ direct, A0 → inverter →
UB̅**, both byte groups wired to the same D0-7 — only one group ever drives.
Supply range confirmed 2.5–3.6V (datasheet p.2, "BLL" row) — 3.3V is mid-range, not
an edge case.

**Timing closes with wide margin.** V20 AC characteristics (same NEC datasheet,
§9.1, -10 grade, Vdd=5V, p.83): at the actual 7.16 MHz operating clock (tCYK ≈ 140 ns,
vs. the -10 grade's 100 ns *minimum* rated tCYK — i.e. comfortably under-clocked):
- tRR (RD̅ low-level width) = 2·tCYK − 40 = **240 ns min**
- tSDK (data setup before sampling CLK↓) = 10 ns min
- ⇒ usable "OE asserted → data must be valid" budget = 240 − 10 = **230 ns**
  (close to the brief's ~200 ns estimate, slightly more generous)

SRAM's own critical-path term is **tDOE (OE access time) = 25 ns max** at the -55
grade (ISSI datasheet, READ CYCLE SWITCHING CHARACTERISTICS, p.6) — since
/OE = MEMR̄ is wired direct (no gate), this is the whole critical path: 25 ns
consumed of a 230 ns budget, **~205 ns of slack**.

The new design's two added gates — `/CE = INV(Y5)` and `/UB = INV(A0)` via one
74HC00 package — are **not on this critical path**: both CE and UB settle from
address-latch time (~T1, start of the 560 ns/4-T-state bus cycle), while OE
(MEMR̄) doesn't assert until mid-cycle. Even a pessimistic 74HC00 gate delay at
3.3V (Nexperia `74HC_HCT00.pdf` Table 7: tpd max = 23 ns@4.5V / 115 ns@2.0V,
no 3.3V row published; conservatively bounding ~40 ns at 3.3V) lands well inside
the address-setup slack, not the OE-to-data slack. This matches the **old
2×AS6C4008 design's already-accepted budget**: `docs/xt-mcu-sbc-design.md` §4.1
already routes SRAM#2's /CE through "one 74HC00 gate" (a NAND) at the same
7.16 MHz/55 ns-SRAM operating point and calls it 0-wait — the new design adds
one *comparable* gate (an inverter) to a *different, non-critical* signal (/UB),
so it is no worse.

Sources: ISSI `62WV51216ALL.pdf` (truth table p.3, timing p.6); NEC IC-3552A
§9.1 AC characteristics p.83; Nexperia `74HC_HCT00.pdf` Table 7 (dynamic
characteristics); `docs/xt-mcu-sbc-design.md` §4.1 (old-design budget, quoted above).

---

## Check 3 — TL16C550C at 3.3V, LQFP-48 (PT) pinout, JLC stock

**VERDICT: PASS for electrical spec; sourced-elsewhere for stock** (per brief's own
fallback instruction).

TI datasheet `TL16C550C` (SLLS177I, rev. March 2021 — current, fetched directly
from `ti.com/lit/ds/symlink/tl16c550c.pdf`):
- §5.2 "Recommended Operating Conditions (Low Voltage - 3.3 nominal)": VCC
  3.0–3.6V (nom 3.3V), oscillator/clock speed max **14.9 MHz** — comfortably
  covers the design's 1.8432 MHz crystal.
- §5.5 "Electrical Characteristics (Low Voltage - 3.3V nominal)" is a fully
  populated table (VOH/VOL/leakage/Icc/capacitance) — 3.3V is an
  officially-supported, characterized operating point, not an edge case.
  Icc max = **8 mA** at Vcc=3.6V (used directly in check 5's budget).
- §4 "Pin Configuration and Functions", Table 4-1 gives the **NO.PT** column
  (LQFP-48) pin-by-pin alongside NO.N (DIP-40)/NO.FN(PLCC-44) — confirmed
  distinct from the DIP-40 numbering the existing `mini-xt:16550` custom symbol
  uses (matches the pre-existing parts.py note that a pin remap is needed at
  layout; this task doesn't remap it, just confirms the table exists and is
  authoritative for whoever does).

**JLC stock: both TL16C550CPTR (C181382) and TL16C550CPTRG4 (C2653207) show
0 units** in `jlc_stock_check` (live API), package LQFP-48(7×7), $3.30/$3.66
1-piece price when available. Per the brief's own instruction ("If JLC has no
stock, put it on the sourced-elsewhere list like the V20"): **TL16C550CPT is
sourced-elsewhere** (TI direct / Mouser / Digi-Key). ACTION for the docs task:
add it to `hardware/notes/jlcpcb-sourcing.md`'s "NOT available at JLCPCB" section
alongside notes on sourcing strategy. (The PLCC-44 `TL16C550CIFNR`, C2653193,
does show 10 in stock at JLC if a socketed fallback is ever wanted, but
decision #3 in the spec is soldered LQFP-48, not socketed.)

Sources: TI `tl16c550c.pdf` (SLLS177I) §4 Table 4-1, §5.2, §5.5;
`mcp__pcbparts__jlc_stock_check` query "TL16C550CPTR" (2026-07-14).

---

## Check 4 — RP2350B GPIO 5V-tolerance conditions

**VERDICT: PASS.**

Raspberry Pi RP2350 datasheet (`RP-008373-DS-2-rp2350-datasheet.pdf`, official
mirror), §14.8.2 pin-type legend, exact quote:

> "Fault Tolerant Digital. These pins are described as Fault Tolerant, which in
> this case means that very little current flows into the pin whilst it is
> below 3.63 V and IOVDD is 0 V. Additionally, they will tolerate voltages up
> to 5.5 V, provided IOVDD is powered to 3.3 V."

and the feature-list summary (p.1): "GPIOs are 5V-tolerant (powered) and
3.3V-failsafe (unpowered)". All **Bank 0 GPIOs (the User IO bank, GPIO0–47 on
the QFN-80/RP2350B package)** use this "Digital IO (FT)" pad type — this is the
bank that carries every bus-facing signal on `bus_mcu`/`video` (RD̄, HLDA, ALE,
MEMR̄/MEMW̄, IOR̄/IOW̄, D0-7, A0-19 sensed lines, etc.), so **every pin that sees
a raw V20 5V output directly is FT and safe, condition: IOVDD powered at 3.3V**
(true for the whole board once the buck is up — no sequencing hazard as long as
the RP2350B's own 3V3 rail comes up with/before the V20's 5V rail, which it
does since both derive from the single 5V input: +5V direct to V20, +5V→buck→
+3V3 to the RP2350Bs is a fraction of a ms slower, and FT pins additionally
tolerate ≤3.63V with *no* IOVDD present per the same quote — no damage risk
during power-up either way).

**Caveat, not applicable here:** the QSPI IO bank (flash/PSRAM pins) uses a
*different, non-FT* pad macro (datasheet explicitly: "This issue doesn't
affect the QSPI pads, which use a different pad macro without the faulty
circuitry" — a reference to an erratum, but confirms the QSPI bank is
electrically distinct). Nothing in mini-xt ties a 5V signal to QSPI pins, so
this doesn't affect the design, but it's worth remembering if a future GPIO
reassignment ever considers routing a bus signal through the flash pins.

Source: Raspberry Pi RP2350 datasheet §14.8.2.2 (pin type legend, p.1367 of the
fetched PDF) and feature list p.1.

---

## Check 5 — 3.3V buck re-budget

**VERDICT: PASS — fits with wide margin, no upsize needed.**

Buck: `hardware/sheets/power.py` U2 = **TPS563200** (TI datasheet confirms:
4.5–17V input / **3A synchronous buck**, SOT-23-6, 650 kHz), configured 5V→3.3V
via a 33k/10k feedback divider (0.768V×(1+33/10) = 3.30V, matches the sheet's
own comment). Sheet's inductor (parts.py: FHD4020S-2R2MT, rated **4.8A**) and
input/output caps are already sized to the datasheet's typical application.

**Estimated worst-case load** (engineering estimate — no per-part current
measurement exists yet; flagged so a bring-up measurement is still worthwhile):

| Item | Count | Each | Subtotal | Basis |
|---|---|---|---|---|
| RP2350B (Bus MCU, Video MCU) | 2 | ~80 mA | 160 mA | dual-core + PIO active, conservative padding over published Pico 2 current figures |
| RP2040 (Supervisor, PicoGUS) | 2 | ~60 mA | 120 mA | dual-core + USB/flash/PSRAM active, conservative padding over RP2040 datasheet typical run current |
| IS62WV51216BLL SRAM | 1 | 30 mA | 30 mA | ISSI datasheet active Icc (also the figure the brief itself cites) |
| TL16C550C UART | 2 | 8 mA | 16 mA | **TI datasheet §5.5, Icc max @ Vcc=3.6V** (check 3) |
| MAX3241 (COM1/COM2) | 2 | ~5 mA | 10 mA | conservative padding over typical RS-232 transceiver active current |
| All 74HC/74LVC glue board-wide (~40-50 pkgs: latches, buffers, mux, decode, dividers, CB3T3257/3245 FET switches) | ~45 | ~3 mA | ~150 mA | conservative average incl. CPD switching current at ~14 MHz, not just static Iq |
| **Total (worst case)** | | | **≈ 486 mA** | |

486 mA is **~16% of the TPS563200's 3A rating** — over 6× headroom. Even
doubling every estimate (e.g. MCUs under heavy DMA/PIO load, more glue than
counted) lands at ~1A, still only ~33% of budget. **Verdict: fits; do not
upsize.**

**Open question logged for the sheet-rewiring task (not resolved here):**
`hardware/sheets/picogus.py` currently regulates its own 3.3V rail (`3V3_PGUS`)
locally via an AMS1117-3.3 fed from `+5V` — a separate supply from the main
board's `+3V3`/TPS563200. The budget above conservatively assumes PicoGUS's
MCU joins the *main* 3.3V bus's load (worst case for this check); whoever
rewires `picogus.py` for the unified 3.3V bus should decide whether to keep
the local AMS1117-from-5V (simplest, no sheet change) or delete it and feed
`3V3_PGUS` from the shared `+3V3` rail directly (one fewer LDO, but then
its current genuinely lands on the main buck as budgeted above). Either way
the buck has room.

Sources: `hardware/sheets/power.py` (read directly); TI `TPS563200` product
page (3A, 4.5–17V input, confirmed via WebSearch of TI's own datasheet
summary); ISSI SRAM datasheet (check 2); TI TL16C550C datasheet (check 3).

---

## Check 6 — PicoGUS GPIO map (must be preserved exactly)

**VERDICT: N/A pass/fail — map documented below for Task 6.**
Verdict N/A by design: this check documents a mapping for downstream preservation; there is nothing to pass or fail.

> **CORRECTION (2026-07-14) — the "GPIO" column below is PACKAGE PINS, not GPIO
> numbers.** The `gpio_map` keys in `picogus.py` were bare digit strings that the
> schematic generator resolves as RP2040 **package-pin numbers** (no pin is
> *named* "31", so `sch.net(U1,"31",…)` falls through to package pin 31). On the
> QFN‑56, package pin ≠ GPIO: pin 8 = GPIO6, pin 17 = GPIO14, pin 31 = GPIO20,
> pin 41 = GPIO29, etc. So the numbers in the first column below (8,9,11‑16,17,
> 30,31,32,41…) are **package pins**; the actual GPIOs are 6,7,8‑13,14,19,20,21,
> 29. The wiring is **correct** — it matches `docs/PicoGUS-chipdown-schematic.pdf`
> pin-for-pin (AD0-7→GPIO6-13, A8/A9→GPIO14/15, ~{RIOW}→GPIO4, ~{RDACK}→GPIO19,
> TC→GPIO20, IRQ5→GPIO21, IOCHRDY→GPIO26, ADS→GPIO27, board-detect→GPIO29).
> `picogus.py` was re-keyed to GPIO **names** on 2026-07-14 (connectivity
> byte-identical; the generated `.kicad_sch`/netlist did not change). See
> `questions-picogus.md` Q7. **The "Discrepancy found" note at the end of this
> section was itself a symptom of this trap — see the resolution appended there.**

Read `hardware/sheets/picogus.py` in full. The RP2040's `gpio_map` list
plus the fixed pin assignments, translated through the two
signal-shifting stages (CB3T3257 address/data mux U4/U5, CB3T3245 U6, LVC2G06
U10) to their ultimate ISA-bus-facing meaning (first column = **package pin**;
GPIO shown in parens where they differ):

| pkg pin (GPIO) | Sheet net | ISA-facing signal | Path / notes |
|---|---|---|---|
| 8,9,11-16 | AD0-AD7 | **A0-A7 / D0-D7** (time-shared) | through U4/U5 (CB3T3257 2:1 FET mux), select = `ADS` (GPIO39), gate = `~{BUSOE}` |
| 17 | RA8 | **A8** (address only, no mux — ISA only has 8 data bits) | through U6 (CB3T3245), 1A2→1Y2 |
| 18 | RA9 | **A9** | through U6, 1A3→1Y3 |
| 6 | ~{RIOW} | **~{IOW}**, qualified | via U7/U8 gates: masked during DMA (`AEN`) unless `DACK` (this channel) asserted |
| 7 | ~{RIOR} | **~{IOR}**, qualified | same masking as above |
| 30 | ~{RDACK} | **~{DACK1} or ~{DACK3}** (whichever is jumpered, J1) | senses the jumpered DMA ack line |
| 31 | RTC_LS | **TC** (ISA terminal count, input) | through U6, 1A0→1Y0 |
| 32 | RIRQ | **IRQ5** (output, hardwired — the free line) | through U6, drives 2A1→2Y1 |
| 34 | RDRQ | **DRQ1 or DRQ3** (output, jumpered, J1) | through U6, drives 2A0→2Y0 |
| 38 | RIOCHRDY | **IOCHRDY** (output, open-drain) | through U10 (74LVC2G06 open-drain buffer — stays regardless of voltage domain, needed for wired-AND semantics) |
| 39 | ADS | *(internal only — mux select/timing, not an ISA signal itself)* | drives U4/U5/U9 select/latch logic |
| 26 | RUN | *(internal — BUSOE-latch enable gating, see U9)* | not ISA-facing |
| 2,3,4,5 | SPI_RX/~{SPI_CS}/SPI_SCK/SPI_TX | *(not ISA — APS6404L sample RAM SPI)* | unaffected by bus voltage domain |
| 27,28,29 | DIN,BCK,LRCK | *(not ISA — PCM5102A I2S DAC)* | unaffected |
| 35 | LED_A | *(not ISA — status LED)* | unaffected |
| 36,37,40 | RV_DATA,RV_CLK,MIDI_TX | *(not ISA — documented dangling, wavetable/MIDI removed 2026-07-11)* | unaffected |
| 41 | — | tied **GND** | see discrepancy note below |
| SWCLK/SWDIO | PGUS_SWCLK/SWDIO | *(debug, not ISA)* | unaffected |

**Which chips are pure voltage-safety vs. functional and must stay regardless
of the 3.3V redesign:**
- **U4/U5 (CB3T3257) are a 2:1 time-division mux**, not primarily a level
  shifter — the RP2040 only has 8 GPIOs for AD0-7 and must time-share them
  between address and data roles (the `ADS`/`~{BUSOE}` scheme). This is a
  firmware/hardware contract independent of bus voltage and **must be
  preserved as-is** even at 3.3V (deleting it would require an 8-pin GPIO
  budget increase the RP2040 doesn't have).
- **U6 (CB3T3245) is pure buffering/level-shift** for 6 single-direction
  signals (A8/A9 in, TC in, IRQ5/DRQ out) with no muxing — this is the piece
  that becomes **removable** once the bus is 3.3V-native (direct GPIO-to-net
  wiring), matching the spec's "PicoGUS (−3 …)" component-count note.
- **U10 (74LVC2G06) stays** — it's an open-drain driver (needed for
  IOCHRDY's wired-AND semantics on a shared bus), not a level shifter, and
  is already 3.3V-native.

**Discrepancy found (flag for whoever next edits `picogus.py`, not fixed
here per "research only"):** the sheet's own module docstring says *"GPIO29
grounded = the chip-down board-detect strap"*, but the actual `gpio_map` code
ties **GPIO29 to `LRCK`** (I2S) and **GPIO41 to `GND`** instead. The code (not
the stale comment) is presumably correct per CLAUDE.md's "generated files are
build outputs, the code is truth" — but the docstring should be corrected in
the same commit that next touches this file, so nobody re-derives the wrong
strap pin from the comment.

> **RESOLVED (2026-07-14) — there was NO discrepancy; this note was the trap in
> action.** The old `gpio_map` key `"29"` is package pin 29 = **GPIO18** = LRCK
> (correct), and key `"41"` is package pin 41 = **GPIO29** = GND (the board-detect
> strap, correct). Read as GPIO numbers the keys looked like "GPIO29→LRCK,
> GPIO41→GND", which is what produced the phantom discrepancy — but GPIO41 does
> not exist on the RP2040. The docstring ("GPIO29 grounded = board-detect strap")
> was right all along; `picogus.py` now keys the map by GPIO name so the strap
> reads unambiguously as `("GPIO29/ADC3", "GND")`. Verified in the netlist:
> `GPIO18_29 → LRCK`, `GPIO29/ADC3_41 → GND`.

---

## Check 7 — Clock divider fmax at 3.3V, 14.31818 MHz input

**VERDICT: FAIL for HC-grade at 3.3V on both dividers — use LVC-grade for both.**

**Correction to the check's own premise:** the design doc's summary/block-diagram
(§1, §5.1, table line 752 of `docs/xt-mcu-sbc-design.md`) and this task's brief both
describe the ÷3 stage as "74HC4017" — but `hardware/notes/open-questions.md`
("Post-review change: standardize 5V glue on 74HCT") already records that the
÷3 was changed from 74HC4017 to a **74HC161 preset-to-3 scheme** (no HCT-grade
4017 exists at JLC) *before* this 3.3V effort began, and the currently-generated
`hardware/sheets/cpu_core.py` (U9, line 217) implements exactly that: a
`mini-xt:74HCT163` symbol with value override `"74HC161"`, preset-loaded to 13
(1101) and reloading on terminal count. **The part actually needing verification
is 74HC161, not 74HC4017** — coincidentally already the same *style* of part
(binary counter preset-reload) as the brief's own suggested fallback, just still
at HC (not LVC) grade. U8 (line 204) is the ÷2, a genuine `mini-xt:74HCT74`
(HCT-grade today, since the whole clock tree currently lives on the 5V rail).

Both parts move to the 3.3V rail in this redesign, so the question is fmax at
3.3V for each. Neither Nexperia datasheet publishes a 3.3V row (only 2.0V/
4.5V/6.0V) — interpolating between the two guaranteed worst-case bracketing
points (-40 to +85°C column, the commercial/industrial range both datasheets
guarantee):

| Part | fmax min @ 2.0V | fmax min @ 4.5V | Linear interp. @ 3.3V | vs. 14.318 MHz |
|---|---|---|---|---|
| 74HC74 (÷2) | 4.8 MHz | 24 MHz | ≈ 14.8 MHz | **~3% margin — unsafe** |
| 74HC161 (÷3, the actual part) | 3.6 MHz | 18 MHz | ≈ 11.1 MHz | **below the clock — fails** |

(Nexperia `74HC_HCT74.pdf` Table 8 and `74HC161.pdf` "fmax, CP" row, both
-40 to +85°C Min columns.) The manufacturer does not guarantee either number
at 3.3V; the true curve is likely concave (most of the Vcc→fmax gain happens
between 2–4.5V, diminishing above), so real silicon may do somewhat better than
the naive linear interpolation — but that's not a number a datasheet backs, and
74HC161's own bracketing points are unambiguously worse than 74HC74's, putting
even the optimistic case in doubt. Per the brief's own <20 MHz safety bar,
**both fail** — this is not a "close enough" case.

**Fix: move both dividers to LVC-grade**, already confirmed in stock at JLC:
- **74LVC74A** (÷2): C6100, TSSOP-14, Nexperia, 7807 in stock, $0.296. Datasheet
  clock frequency spec 250 MHz — no margin question at 14.318 MHz.
- **74LVC161** (÷3, same preset-to-3 topology, direct drop-in): C548136,
  TSSOP-16, Nexperia, spec'd 150 MHz / 1.2–3.6V — comfortable margin. **Stock is
  thin (100 units at time of writing) — re-verify before ordering.**

This is a genuine part change for whichever task rewires `cpu_core.py`'s clock
tree (U8/U9), not a blocker for the overall redesign — logged here so that
task doesn't accidentally leave U8/U9 on HC-grade bodies once they move to
the 3.3V rail.

Sources: Nexperia `74HC_HCT74.pdf` Table 8 (dynamic characteristics, fmax
row); Nexperia `74HC161.pdf` (dynamic characteristics, fmax row);
`hardware/sheets/cpu_core.py` lines 195–264 (current implementation, read
directly); `hardware/notes/open-questions.md` "Post-review change: standardize
5V glue on 74HCT" (÷3 history); `docs/xt-mcu-sbc-design.md` (stale 4017
references); `mcp__pcbparts__jlc_get_part` for both LCSC codes.

---

## Parts picks table

All LCSC codes confirmed via `jlc_search`/`jlc_get_part`/`jlc_stock_check`
(2026-07-14). "Stock" is the live count at query time; **thin** flags anything
worth re-checking before an order.

| Role | MPN | LCSC | Package | Price (1pc) | Stock |
|---|---|---|---|---|---|
| SRAM 512K×16 | IS62WV51216BLL-55TLI | C11315 | TSOP-II-44 | $11.54 | 1913 (existing pick, re-confirmed 2.5–3.6V, 55ns, byte-lane valid — check 2) |
| Octal latch, 3.3V, 5V-tol inputs | 74LVC573APW,118 | C6096 | TSSOP-20 | $0.28 | 18,681 |
| Octal buffer, 3.3V, 5V-tol | 74LVC244APW,118 | C6079 | TSSOP-20 | $0.29 | 23,742 |
| Octal D-FF for parallel.py | 74LVC574AT20-13 | C842658 | TSSOP-20 | $0.34 | 88 **thin** |
| Quad tri-state | 74LVC125AD,118 | C6057 | SOIC-14 | $0.19 | 17,935 |
| Open-drain dual buffer (IOCHRDY/IOCHCK̄) | 74LVC2G07GW,125 | C24478 | SOT-363-6 | $0.24 | 6,631 |
| 74HC00 (NAND, 3.3V re-buy) | 74HC00D | C699445 | SOIC-14 | $0.27 | 1,108 |
| 74HC04 (inverter, 3.3V re-buy) | 74HC04D | C86613 | SOIC-14 | $0.08 | 28,720 |
| 74HC32 (OR, 3.3V re-buy) | 74HC32D | C52140395 | SOP-14L (verify SOIC-14 footprint match) | $0.15 | 3,904 |
| 74HC125 (tri-state buf, 3.3V re-buy) | 74HC125D | C52140399 | SOP-14L | $0.15 | 11,602 |
| 74HC138 (3:8 decoder, 3.3V re-buy) | 74HC138D,653 | C5602 | SOIC-16 | $0.20 | 42,420 |
| 74HC244 (octal buf, 3.3V re-buy) | 74HC244D | C52140409 | SOP-20L | $0.25 | 1,697 |
| 74HC245 (octal xcvr, 3.3V re-buy) | 74HC245D | C2675537 | SOIC-20-300mil | $0.65 | 912 |
| 74HC157/161/165/08/02 (3.3V re-buy) | *(unchanged)* | C5609/C5610/C5613/C5593/C5588 | — | — | existing parts.py codes already HC-grade, keep as-is |
| ÷2 divider — **use LVC, not HC** (check 7) | 74LVC74APW,118 | C6100 | TSSOP-14 | $0.30 | 7,807 |
| ÷3 divider fallback (check 7, mandatory) | 74LVC161PW,118 | C548136 | TSSOP-16 | $0.72 | 100 **thin** |
| UART | TL16C550CPTR | C181382 | LQFP-48 | $3.30 | **0 — sourced elsewhere** (TI/Mouser/Digi-Key; see check 3) |
| UART (socketed fallback, if ever needed) | TL16C550CIFNR | C2653193 | PLCC-44 | $7.86 | 10 |
| I2C RTC | PCF8563T/5,518 | C7440 | SO-8 | $0.59 | 166,556 — **preferred** library, deepest stock/cheapest of all RTC options checked |
| CR2032 holder | CR2032-BS-6 | C22363833 | SMD | $0.23 | 13,541 |

Notes:
- 74HC32/125/244/245 picks above come from smaller-name fabs (MDD/Toshiba)
  since the same Nexperia-branded parts either aren't stocked or are thin;
  all confirmed ≥2V-6V supply range in their JLC listings, compatible with
  the existing SOIC/SOP footprint conventions in `parts.py`.
- 74LVC161 and 74LVC574A are both thin (100/88 units) — flag for re-check
  immediately before BOM lock, same caution `parts.py`'s docstring already
  applies to TL16C550/DB25/MAX3241/TPS563200.
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

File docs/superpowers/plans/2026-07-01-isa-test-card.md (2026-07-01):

# ISA Card Tester (`card_isatest`) Implementation Plan

> **For agentic workers:** REQUIRED SUB-SKILL: Use superpowers:subagent-driven-development (recommended) or superpowers:executing-plans to implement this plan task-by-task. Steps use checkbox (`- [ ]`) syntax for tracking.

**Goal:** Add a standalone Pico-based ISA host/bus-master test board (`card_isatest`) to the mini-xt KiCad generator, as an interface-focused schematic in the same style as the other cards.

**Architecture:** A stock Raspberry Pi Pico module drives the full 8-bit ISA bus through `74LVC245A` 3.3↔5 V transceivers. Address + slow control ride a split `74HC595` OUT chain; IRQ/DRQ/status ride a `74HC165` IN chain; data is direct GPIO. A 14.318 MHz can-oscillator clock tree (÷2/÷3 + PIO override) generates CLK/OSC. USB serial is the user link. A real 8-bit ISA card-edge slot and the 60-pin `isa_conn` sidecar header expose the bus to a DUT.

**Tech Stack:** Python schematic generator (`hardware/tools/mxsch.py`, `mxbus.py`, `isa_conn.py`, `gensym.py`), KiCad 9 symbols, `kicad-cli sch erc` validation.

## Global Constraints

- **Design spec:** `docs/superpowers/specs/2026-07-01-isa-test-card-design.md` — authoritative for all decisions.
- **Authoring rules:** follow `hardware/tools/SHEET_AUTHORING_GUIDE.md`. Place every component on the 2.54 mm grid. Connectivity is **by net name** via `sch.net(comp, pin, "NET", kind="label", dx=, dy=)`. One net = one name.
- **Canonical net names** (from `mxbus`, use EXACTLY): address `A0`..`A19`; data `D0`..`D7`; IRQ `IRQ2`..`IRQ15`; control `~{MEMR} ~{MEMW} ~{IOR} ~{IOW} BALE AEN IOCHRDY ~{IOCHCK} RESET_DRV CLK OSC TC DRQ1 DRQ2 DRQ3 ~{DACK1} ~{DACK2} ~{DACK3} ~{REFRESH}`; power `+5V +3V3 GND`. Active-low uses `~{...}`.
- **Internal (non-bus) net conventions:** Pico-side data `MD0..MD7`; shift-register address `MA0..MA19`; control-out (internal side of ctrl `'245`) `M_*`; sensed inputs (internal side of input `'245`) `*_S`.
- **Validation is the test.** `python3 hardware/tools/validate_sheet.py <name>` must report **zero** of: `endpoint_off_grid`, `unconnected_wire_endpoint`, `multiple_net_names`, any "Failed to load". EXPECTED/ignored: `pin_not_connected`, `pin_not_driven`, `label_dangling`, `lib_symbol_issues` (missing-lib note).
- **When validate reports `multiple_net_names` or `unconnected_wire_endpoint`:** two labels/stubs collided at one point — nudge the offending component's coordinate by ±2.54 mm and/or flip a stub `dx/dy` sign. This is the normal authoring loop; iterate until clean.
- **Commit** after each task with the exact `git add`/`git commit` shown.
- Commit messages end with: `Co-Authored-By: Claude Opus 4.8 (1M context) <noreply@anthropic.com>`
- **Under-specified detail?** Do NOT stop. Record the question + your best-guess pick in `hardware/notes/questions-isatest.md` and proceed (Task 9 creates the file; append to it any time).

---

## File Structure

- **Create** `hardware/sheets/card_isatest.py` — the whole tester board (standalone card, `PINS=[]`). One `build(sch, lib)` grown across Tasks 2–8.
- **Modify** `hardware/tools/gensym.py` — add the `mini-xt:Pico` module symbol; add `pico` to the emitted library list.
- **Regenerate** `hardware/mini-xt.kicad_sym` (output of `gensym.py`).
- **Modify** `hardware/tools/build.py` — add `"card_isatest"` to `CARD_SHEETS`.
- **Create** `hardware/notes/questions-isatest.md` — per-sheet decisions/open items.
- **Modify** `hardware/README.md` — add `card_isatest` to the layout table.

**Reused symbols (no authoring needed):** `mini-xt:74LVC245A`, `74xx:74HC595`, `mini-xt:74HCT165`, `mini-xt:74HCT74`, `mini-xt:74HCT163`, `mini-xt:74HCT157`, `mini-xt:74HCT04`, `Oscillator:ACO-xxxMHz`, `Connector:Bus_ISA_8bit`, `Connector:Barrel_Jack`, `Device:D_Schottky`, `Device:Q_PMOS`, `Device:R`, `Device:C`. Sidecar via `isa_conn.place_header`.

---

### Task 1: Author the `mini-xt:Pico` module symbol

**Files:**
- Modify: `hardware/tools/gensym.py` (add symbol near the Core2350B block, ~line 231–252; extend the lib list at ~line 251)
- Regenerate: `hardware/mini-xt.kicad_sym`

**Interfaces:**
- Produces: `mini-xt:Pico` with pins `GP0`..`GP22`, `GP26`, `GP27`, `GP28` (bidirectional), `VBUS`/`VSYS` (power_in), `3V3` (power_out), `3V3_EN`/`RUN` (input), `ADC_VREF` (passive), `GND` (power_in). GPIO names are authoritative; pin numbers follow the physical 40-pin Pico pinout.

- [ ] **Step 1: Add the Pico symbol builder** — insert after the `core2350b = make_ic(...)` block in `hardware/tools/gensym.py`:

```python
# ---- Raspberry Pi Pico module (RP2040; Pico 2/RP2350A pin-compatible) ----
# Standard 40-pin castellated module. Exposes 26 usable GPIO (GP0-GP22, GP26-28;
# GP23/24/25 are module-internal) + power/control. GPIO NAMES are authoritative;
# pin NUMBERS follow the physical 40-pin Pico pinout (GND pins collapsed to two).
pico = make_ic(
    "Pico",
    left=[(str(n), "GP%d" % g, "bidirectional") for n, g in [
        (1, 0), (2, 1), (4, 2), (5, 3), (6, 4), (7, 5), (9, 6),
        (10, 7), (11, 8), (12, 9), (14, 10), (15, 11), (16, 12)]],
    right=[(str(n), "GP%d" % g, "bidirectional") for n, g in [
        (17, 13), (19, 14), (20, 15), (21, 16), (22, 17), (24, 18),
        (25, 19), (26, 20), (27, 21), (29, 22), (31, 26), (32, 27), (34, 28)]],
    top=[("40", "VBUS", "power_in"), ("39", "VSYS", "power_in"),
         ("37", "3V3_EN", "input")],
    bottom=[("3", "GND", "power_in"), ("38", "GND", "power_in"),
            ("36", "3V3", "power_out"), ("30", "RUN", "input"),
            ("35", "ADC_VREF", "passive")],
    ref="M",
    description="Raspberry Pi Pico module (RP2040; Pico 2/RP2350A pin-compatible): 26 usable GPIO, onboard 3V3 SMPS, USB",
    datasheet="https://datasheets.raspberrypi.com/pico/pico-datasheet.pdf")
```

- [ ] **Step 2: Add `pico` to the emitted library list** — change the `lib = [...]` line (currently ending `..., core2350b] + glue_syms`):

```python
lib = ["kicad_symbol_lib", ["version", 20241209], ["generator", "mxsch"],
       ["generator_version", "9.0"], v20, max3241, ds12c887, core2350b, pico] + glue_syms
```

- [ ] **Step 3: Regenerate the symbol library**

Run: `cd /home/andrew/repos/mini-xt && python3 hardware/tools/gensym.py`
Expected: prints `wrote .../hardware/mini-xt.kicad_sym`

- [ ] **Step 4: Verify the symbol exists with the expected pins**

Run: `python3 hardware/tools/pins.py mini-xt:Pico`
Expected: lists `GP0`..`GP22`, `GP26`, `GP27`, `GP28`, `VBUS`, `VSYS`, `3V3`, `3V3_EN`, `RUN`, `ADC_VREF`, `GND`.

- [ ] **Step 5: Confirm existing sheets still generate** (gensym rewrites the whole lib)

Run: `python3 hardware/tools/validate_sheet.py cpu_core 2>&1 | tail -5`
Expected: histogram with zero `endpoint_off_grid` / `unconnected_wire_endpoint` / `multiple_net_names` (same as before this change).

- [ ] **Step 6: Commit**

```bash
git add hardware/tools/gensym.py hardware/mini-xt.kicad_sym
git commit -m "Add mini-xt:Pico module symbol for the ISA test card

Co-Authored-By: Claude Opus 4.8 (1M context) <noreply@anthropic.com>"
```

---

### Task 2: `card_isatest` skeleton — Pico, helpers, GPIO map, decoupling; register the card

**Files:**
- Create: `hardware/sheets/card_isatest.py`
- Modify: `hardware/tools/build.py:60` (`CARD_SHEETS` list)

**Interfaces:**
- Produces: module `card_isatest` with `NAME`, `TITLE`, `PAPER="A2"`, `PINS=[]`, `GPIO_NET` dict, `build(sch, lib)`; nested helpers `N`, `decouple`, `xcvr`, `s595`, `s165`, `pull` used by later tasks. Pico placed as `M1`; internal nets `MD0..MD7`, `DATADIR`, `M_MEMR/M_MEMW/M_IOR/M_IOW`, `IOCHRDY_S`, `M_REFRESH`, `SER`, `SRCLK`, `RCLK_ADDR`, `RCLK_CTRL`, `IN_PL`, `IN_QH`, `~{BUF_EN}`, `PIO_CLK`, `CLK_S` established on the Pico pins.

- [ ] **Step 1: Create `hardware/sheets/card_isatest.py`** with the skeleton (Pico + helpers + decoupling). Later tasks insert their blocks at the marked point:

```python
"""card_isatest -- standalone ISA card tester: a stock Raspberry Pi Pico acts as
the ISA host / bus master to exercise a device-under-test (DUT) card over USB
serial. See docs/superpowers/specs/2026-07-01-isa-test-card-design.md.

The Pico drives the full 8-bit ISA bus through 74LVC245A 3.3<->5V transceivers:
  * data D0-7   : direct Pico GPIO (MD0-7), dir = DATADIR
  * address A0-19: 74HC595 OUT chain (split address / control latches)
  * control out : strobes direct + AEN/RESET_DRV/TC/DACK/BALE on the OUT chain
  * status in   : IRQ/DRQ/IOCHCK# on a 74HC165 IN chain; IOCHRDY/CLK sensed direct
A 14.318 MHz can-oscillator clock tree (/2, /3, PIO override) makes CLK/OSC.
Standalone board: bus + power arrive via its own ISA slot + sidecar header, so
there is no parent interface (PINS = []), like the other card_* PCBs.
"""
import isa_conn
import mxbus  # noqa: F401  (canonical names spelled out below)

NAME = "card_isatest"
TITLE = "ISA Card Tester -- Pico host/bus-master"
PAPER = "A2"               # room for the Pico + 8x '245 + shift chains + slot
PINS = []                  # standalone PCB: bus + power come through the connectors

# Pico GPIO -> internal net (MCU side). 24 of 26 used; GP27/GP28 spare.
GPIO_NET = {
    0: "MD0", 1: "MD1", 2: "MD2", 3: "MD3", 4: "MD4", 5: "MD5", 6: "MD6", 7: "MD7",
    8: "DATADIR",
    9: "M_MEMR", 10: "M_MEMW", 11: "M_IOR", 12: "M_IOW",
    13: "IOCHRDY_S", 14: "M_REFRESH",
    15: "SER", 16: "SRCLK", 17: "RCLK_ADDR", 18: "RCLK_CTRL",
    19: "IN_PL", 20: "IN_QH", 21: "~{BUF_EN}", 22: "PIO_CLK",
    26: "CLK_S",
}
_HIER_SHAPE = {}  # standalone board: all nets are local labels

def build(sch, lib):
    # ---- shared helpers -------------------------------------------------
    def N(comp, key, name, dx=2.54, dy=0.0):
        return sch.net(comp, key, name, dx=dx, dy=dy, kind="label")

    def decouple(ref, at, hi="+3V3"):
        c = sch.place("Device:C", ref, "100nF", at=at)
        sch.net(c, "1", hi, kind="label", dx=0, dy=-2.54)
        sch.net(c, "2", "GND", kind="label", dx=0, dy=2.54)

    def xcvr(ref, at, dir_net, vcc="+3V3"):
        """74LVC245A buffer. dir_net -> A->B pin; CE(~OE) -> ~{BUF_EN}."""
        u = sch.place("mini-xt:74LVC245A", ref, "74LVC245A", at=at)
        N(u, "VCC", vcc, dx=0, dy=-2.54)
        N(u, "GND", "GND", dx=0, dy=2.54)
        N(u, "A->B", dir_net)
        N(u, "CE", "~{BUF_EN}")
        return u

    def s595(ref, at, rclk):
        """74HC595 SIPO @3V3. SRCLK shared; per-segment RCLK; OE tied on."""
        u = sch.place("74xx:74HC595", ref, "74HC595", at=at)
        N(u, "VCC", "+3V3", dx=0, dy=-2.54)
        N(u, "GND", "GND", dx=0, dy=2.54)
        N(u, "SRCLK", "SRCLK")
        N(u, "RCLK", rclk)
        N(u, "~{OE}", "GND")        # internal side always driven; bus gated by '245
        N(u, "~{SRCLR}", "+3V3")
        return u

    def s165(ref, at):
        """74HCT165 PISO @3V3. CP shared with SRCLK; ~{PL}=IN_PL."""
        u = sch.place("mini-xt:74HCT165", ref, "74HCT165", at=at)
        N(u, "VCC", "+3V3", dx=0, dy=-2.54)
        N(u, "GND", "GND", dx=0, dy=2.54)
        N(u, "CP", "SRCLK")
        N(u, "~{PL}", "IN_PL")
        N(u, "~{CE}", "GND")
        return u

    def pull(ref, at, net, rail):
        r = sch.place("Device:R", ref, "10k", at=at)
        sch.net(r, "1", net, kind="label", dx=0, dy=-2.54)
        sch.net(r, "2", rail, kind="label", dx=0, dy=2.54)

    # ---- M1: Raspberry Pi Pico module -----------------------------------
    M1 = sch.place("mini-xt:Pico", "M1", "Pico (RP2040)", at=(101.6, 152.4))
    # Power: VBUS = USB 5V; VSYS from the board 5V rail (jack or USB); 3V3 OUT
    # powers all the 3V3 logic on this card. (Power block wired in Task 7.)
    N(M1, "VBUS", "+5V_USB", dx=0, dy=-2.54)
    N(M1, "VSYS", "V5RAW", dx=0, dy=-2.54)
    N(M1, "3V3", "+3V3", dx=0, dy=-2.54)
    N(M1, "GND", "GND", dx=0, dy=2.54)
    for nm in ("3V3_EN", "RUN", "ADC_VREF"):
        sch.no_connect(M1.pin_xy(nm))
    for idx, net in GPIO_NET.items():
        N(M1, "GP%d" % idx, net)
    for idx in (27, 28):
        sch.no_connect(M1.pin_xy("GP%d" % idx))   # spare GPIO
    sch.text("Pico host/bus-master: USB serial console; drives full 8-bit ISA bus "
             "via 74LVC245A buffers. 24/26 GPIO used.", (38.1, 96.52))

    # ==== BLOCKS BELOW ADDED BY LATER TASKS (keep this marker) ============
    # [transceivers] [out-chain] [in-chain] [clock] [power] [connectors]

    # ---- decoupling (representative) ------------------------------------
    decouple("C1", (40.64, 50.8), "+3V3")
    decouple("C2", (55.88, 50.8), "+3V3")

    sch.text("Standalone ISA card tester PCB (card_isatest). Bus + power via the "
             "on-board ISA slot (J1) and 60-pin sidecar header (J2).", (38.1, 12.7))
```

- [ ] **Step 2: Register the card** — in `hardware/tools/build.py` change the `CARD_SHEETS` line (line 60):

```python
CARD_SHEETS = ["card_video", "card_com", "card_lpt", "card_rtc", "card_storage", "card_isatest"]
```

- [ ] **Step 3: Validate the skeleton sheet**

Run: `python3 hardware/tools/validate_sheet.py card_isatest 2>&1 | tail -8`
Expected: histogram printed; **zero** `endpoint_off_grid`, `unconnected_wire_endpoint`, `multiple_net_names`; ends with `components placed: 3` (M1 + C1 + C2). If a collision appears, nudge coords per Global Constraints.

- [ ] **Step 4: Build the standalone card**

Run: `python3 -c 'import sys;sys.path.insert(0,"hardware/tools");import build;build.build_cards()' 2>&1 | tail -3`
Expected: a line `card card_isatest   3 comps  ...` with no load error.

- [ ] **Step 5: Commit**

```bash
git add hardware/sheets/card_isatest.py hardware/tools/build.py
git commit -m "Add card_isatest skeleton (Pico + helpers) and register the card

Co-Authored-By: Claude Opus 4.8 (1M context) <noreply@anthropic.com>"
```

---
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

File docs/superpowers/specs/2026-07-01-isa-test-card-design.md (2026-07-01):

# ISA Card Tester (`card_isatest`) — Design

**Date:** 2026-07-01
**Status:** Approved design; ready for implementation planning
**Scope:** A standalone development/diagnostic board that acts as an ISA **host**
(bus master) to exercise a device-under-test (DUT) ISA card, driven entirely over
USB serial. Interface-focused KiCad schematic in the same style as the rest of the
repo (real symbols, every inter-block signal visible); **firmware is out of scope**.

---

## 1. Purpose & role

`card_isatest` is a small board whose centerpiece is a **stock Raspberry Pi Pico
module** (RP2040; a Pico 2 / RP2350A is pin-compatible and may be substituted). It
presents an ISA bus to a DUT and drives every bus signal itself, so it can:

- read/write a card's memory and I/O registers,
- generate the bus clocks (CLK, OSC), RESET_DRV, and REFRESH#,
- emulate DMA cycles (AEN / DACK / TC),
- sense the card's responses (data, IOCHRDY wait states, IOCHCK#, IRQ, DRQ),
- measure and report the actual bus clock frequency,

and report everything to the user over the Pico's **USB serial** — no GPIO is spent
on user interaction, programming, or display.

The tester is the **motherboard side** of the bus: it is always the bus master. This
is the opposite role from the mini-xt soft-cards (which are bus *slaves*). It is a
**complete standalone board** — the bus and power arrive through its own connectors,
so the schematic has no parent hierarchical interface (`PINS = []`), exactly like the
existing `card_*` soft-card PCBs.

### Non-goals

- No V20/CPU, no companion MCU — the single Pico is the whole brain.
- No ±12 V / −5 V analog rails (consistent with the rest of mini-xt, design S13).
- Not cycle-*accurate* by default: cycles run at the tester's own (slower) pace.
  Optional CLK-synchronous timing is available via `CLK_SENSE` (§7).
- No support for a **bus-mastering DUT** (a card that drives the address bus during
  its own DMA). Address is output-only. Adding readback is noted as future work (§13).
- Firmware is out of scope for this spec.

---
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

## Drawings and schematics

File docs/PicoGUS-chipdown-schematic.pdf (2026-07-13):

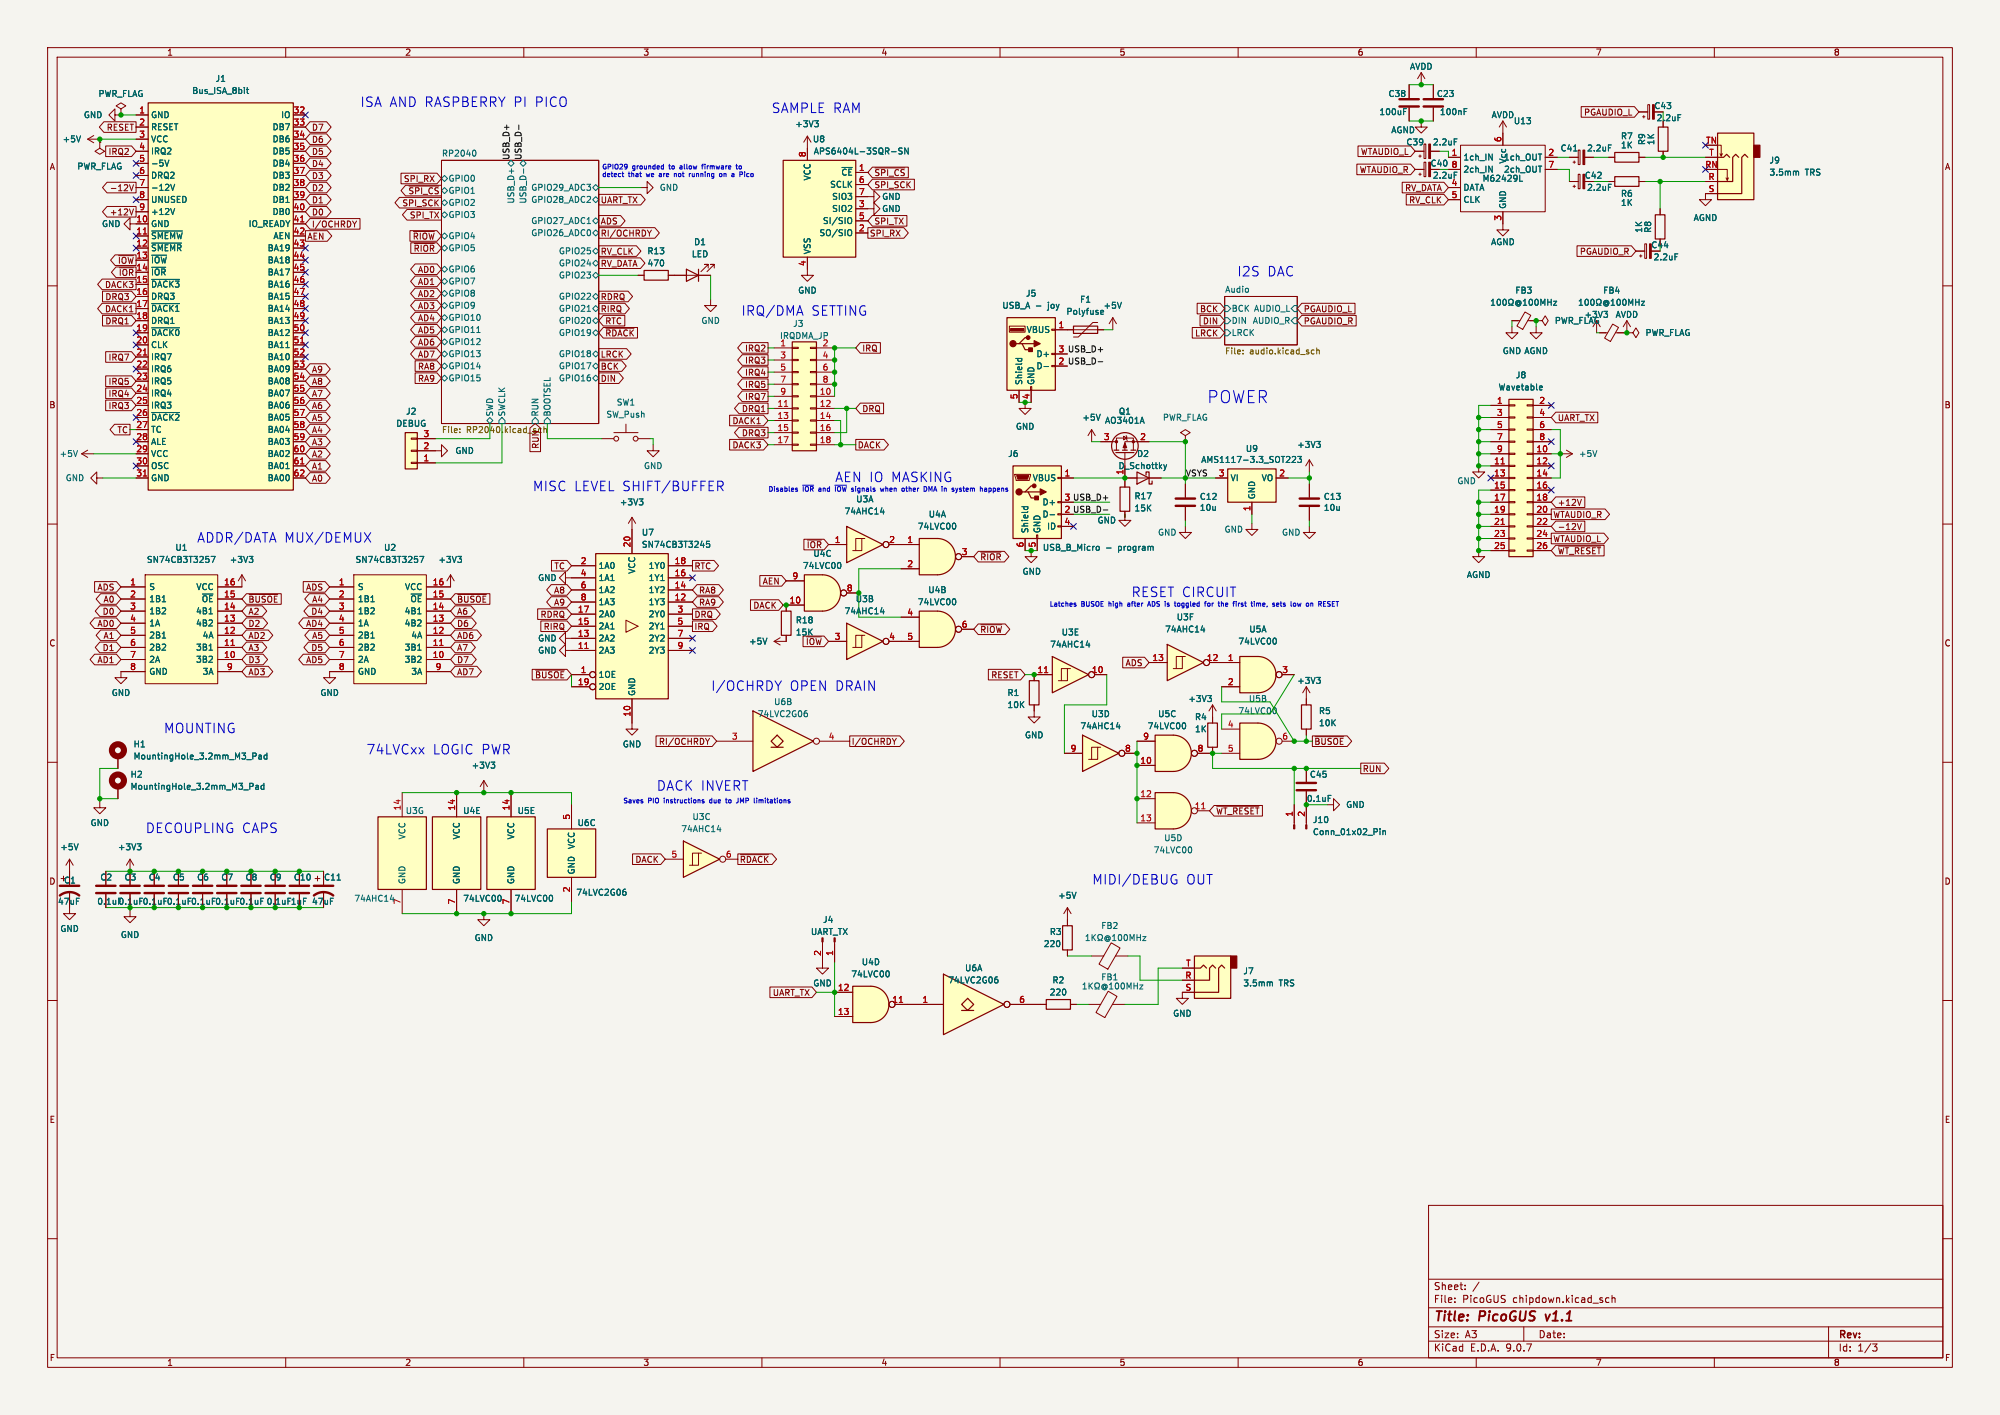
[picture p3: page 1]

SAMPLE RAM ISA AND RASPBERRY PI PICO

4 ~{CE}1 SCLK 6 SIO3 7 SIO2 3 SI/SIO 5 SO/SIO 2 +3V3
SPI_SCK RI/OCHRDY
GND

-12V 7 UNUSED 8 +12V 9 GND 10 ~{SMEMW} 11 ~{SMEMR} 12 ~{IOW} 13 ~{IOR} 14 ~{DACK3} 15 DRQ3 16 ~{DACK1} 17 DRQ1 18 ~{DACK0} 19 CLK 20

4 ~{CE}1 SCLK 6 SIO3 7 SIO2 3 SI/SIO 5 SO/SIO 2 U8APS6404L-3SQR-SNGND

IRQ2 4
-5V 5 DRQ2 6
IO_READY 41 AEN 42 BA19 43 BA18 44 BA17 45 BA16 46 BA15 47 BA14 48 BA13 49 BA12 50 BA11 51 BA10 52 BA09 53 BA08 54 BA07 55 BA06 56 BA05 57 BA04 58 BA03 59 BA02 60 BA01 61 BA00 62

ADDR/DATA MUX/DEMUX

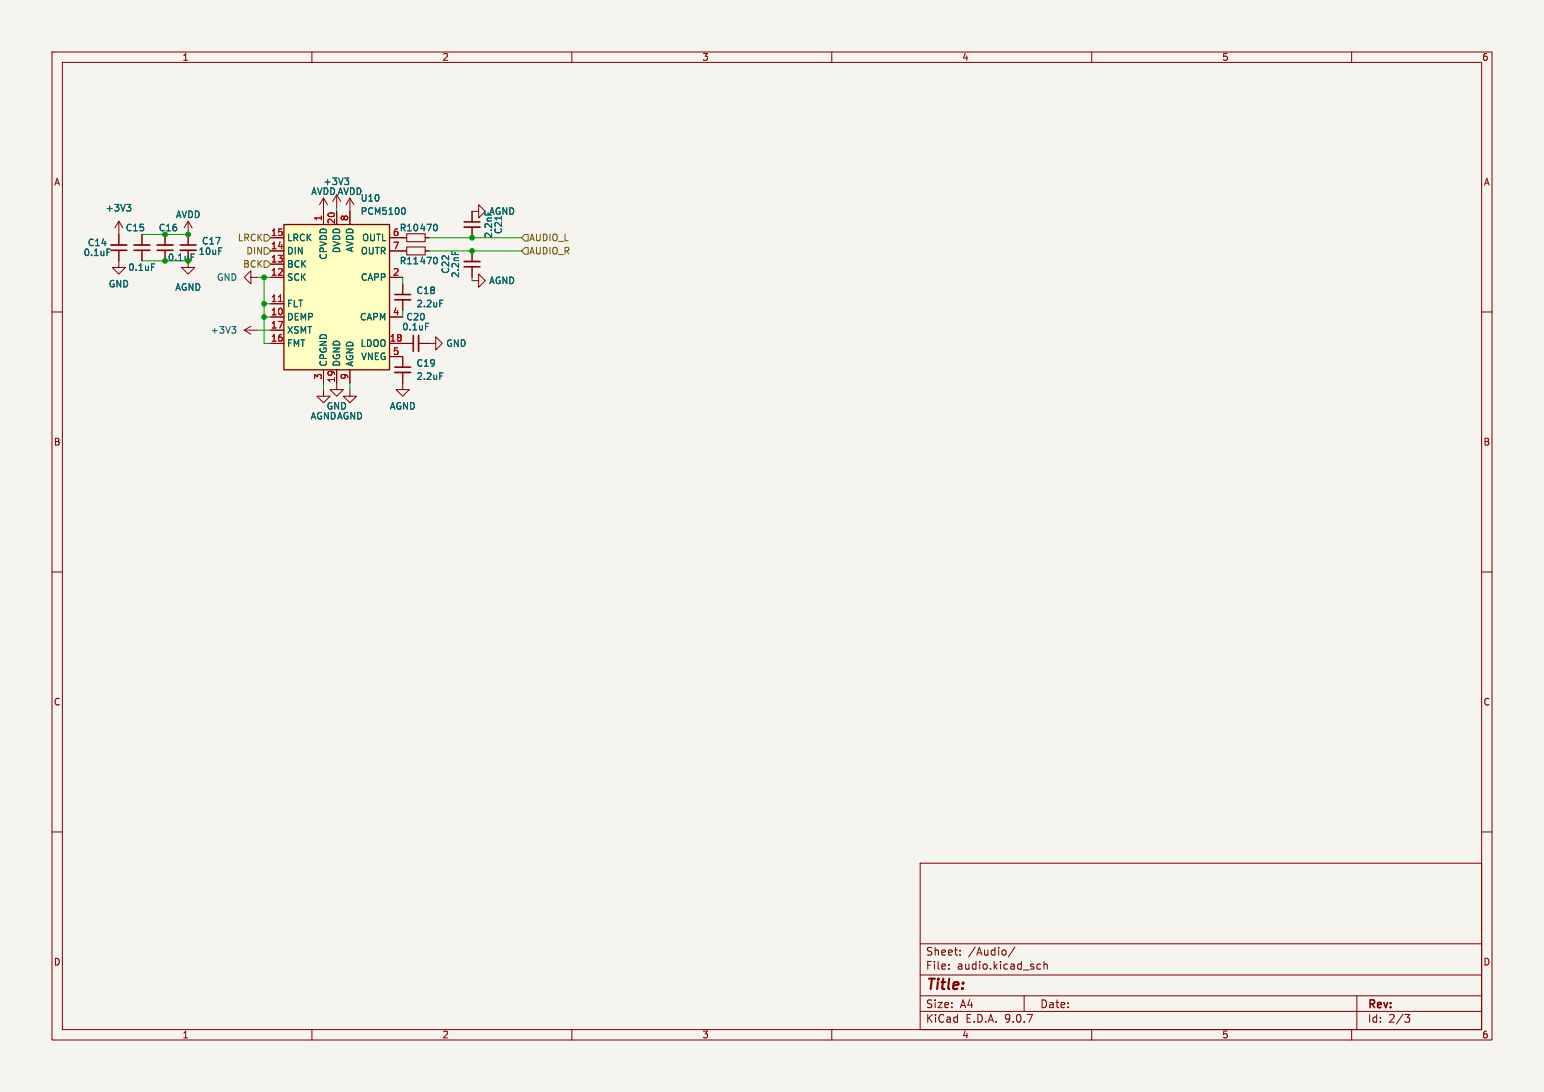
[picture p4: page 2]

9 OUTL 6 OUTR 7 CAPP 2 CAPM 4

Id: 2/3 Title: File: audio.kicad_sch Sheet: /Audio/

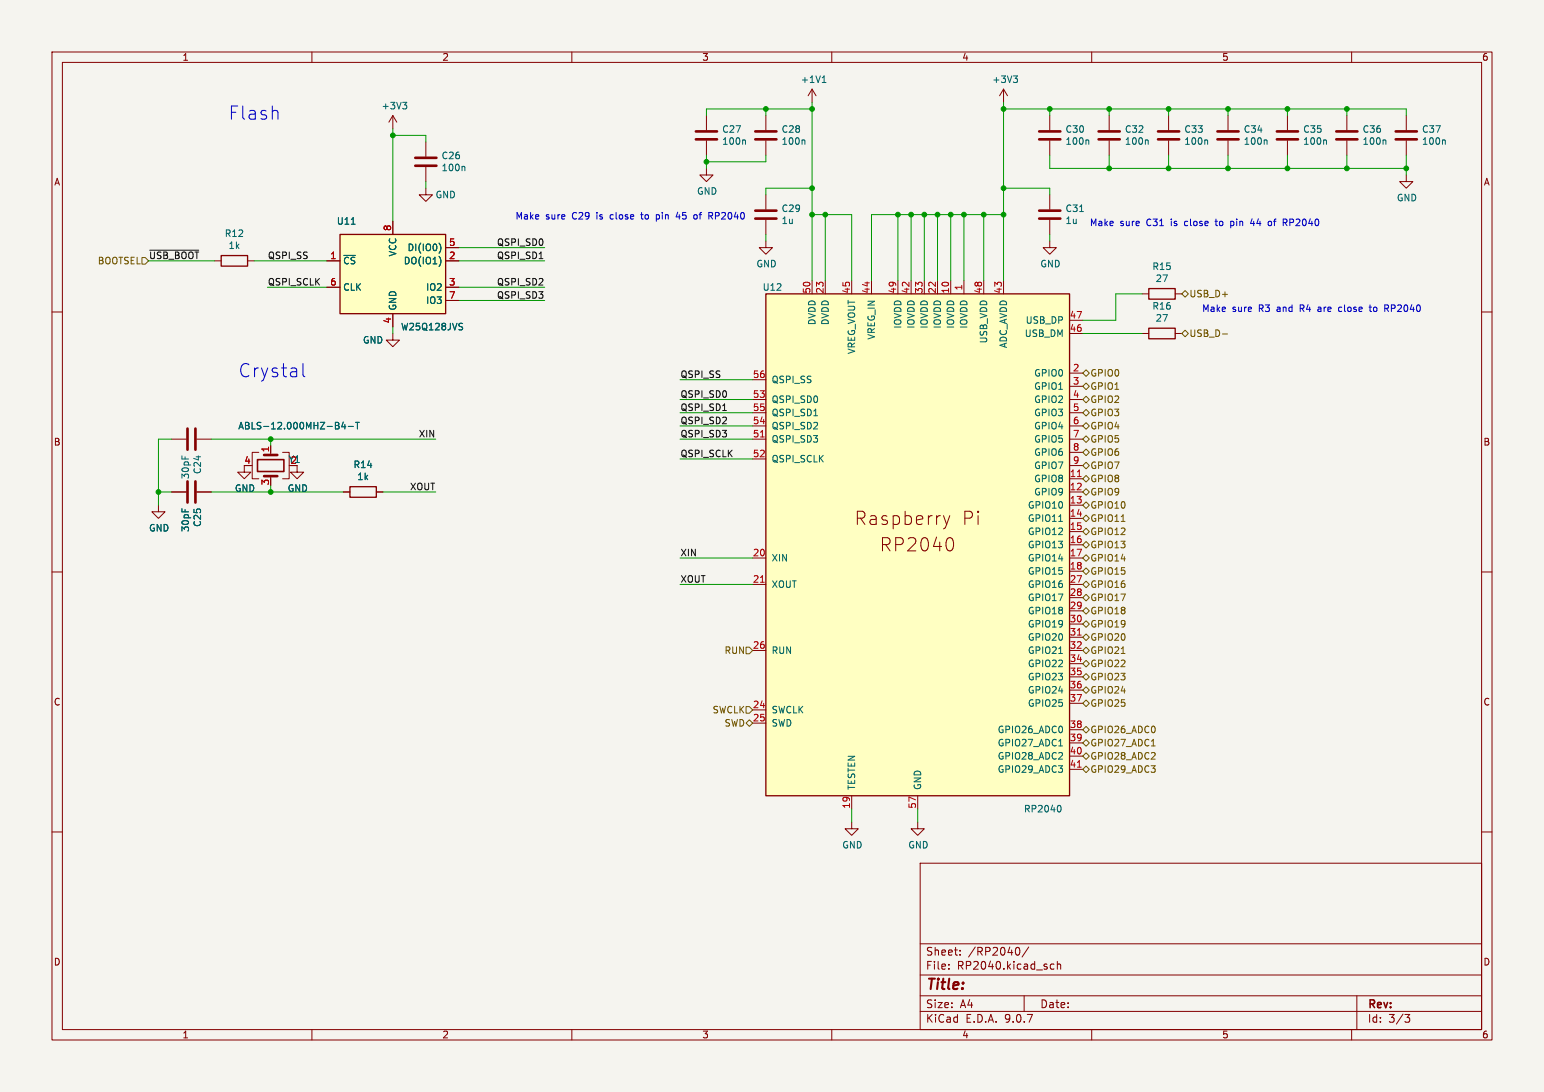
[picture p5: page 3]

Id: 3/3 Title: File: RP2040.kicad_sch Sheet: /RP2040/ GND

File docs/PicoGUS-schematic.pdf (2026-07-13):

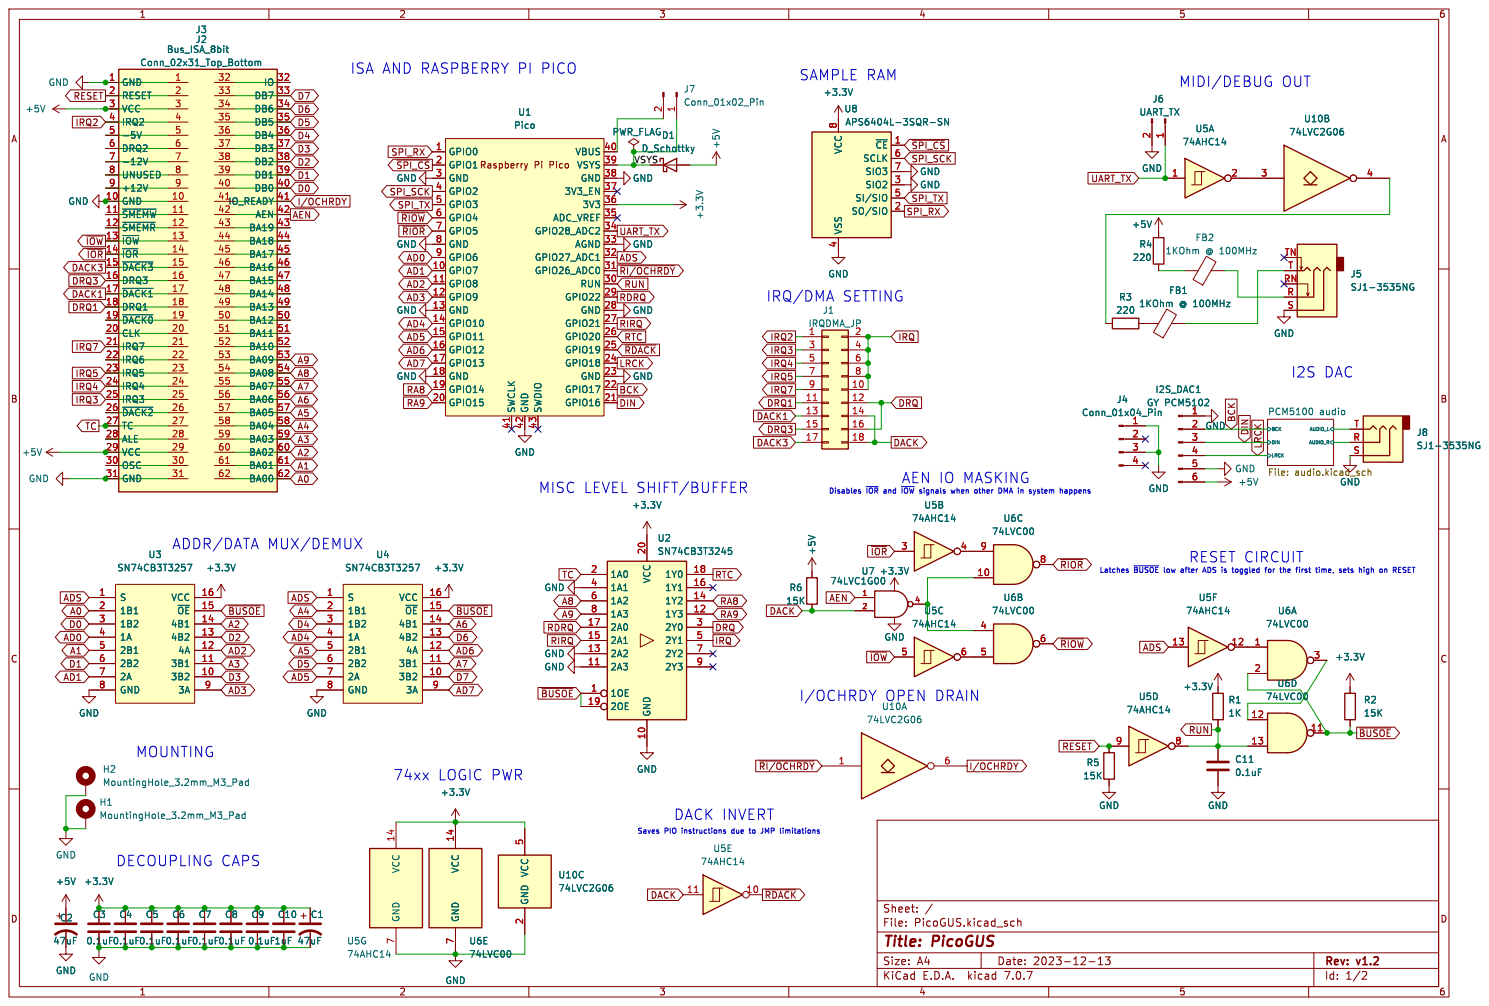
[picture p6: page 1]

J3 Bus_ISA_8bit GND 1 GND 10 ~{SMEMW} 11 ~{SMEMR} 12 ~{IOW} 13 ~{IOR} 14 ~{DACK3} 15 DRQ3 16 ~{DACK1} 17 DRQ1 18 ~{DACK0} 19 RESET 2 CLK 20
GND 1 GND 10 ~{SMEMW} 11 ~{SMEMR} 12 ~{IOW} 13 ~{IOR} 14 ~{DACK3} 15 DRQ3 16 ~{DACK1} 17 DRQ1 18 ~{DACK0} 19 RESET 2 CLK 20
~{RI/OCHRDY} D6 D7 D3 D4 D5 TC
IRQ3 25 ~{DACK2} 26 TC 27 ALE 28 VCC 29 VCC 3 OSC 30 GND 31

ISA AND RASPBERRY PI PICO

8 GND GND
~{CE}1 SO/SIO 2 SIO2 3 VSS

4 SI/SIO 5 SCLK 6 SIO3 7 VCC

GND GND

ADDR/DATA MUX/DEMUX

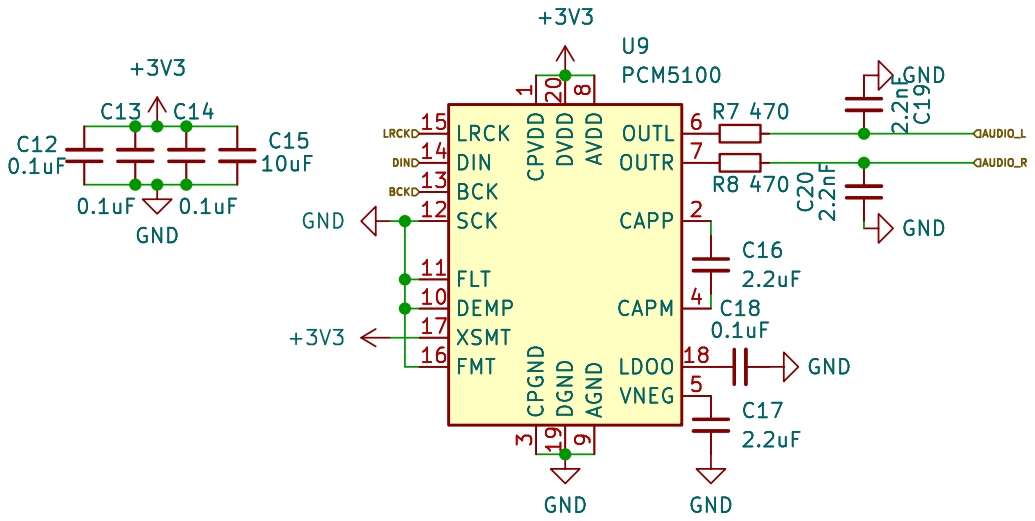
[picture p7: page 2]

1 DEMP 10 FLT 11 SCK 12 BCK 13 DIN 14

3 CAPM 4 VNEG 5 OUTL 6 OUTR 7 AVDD

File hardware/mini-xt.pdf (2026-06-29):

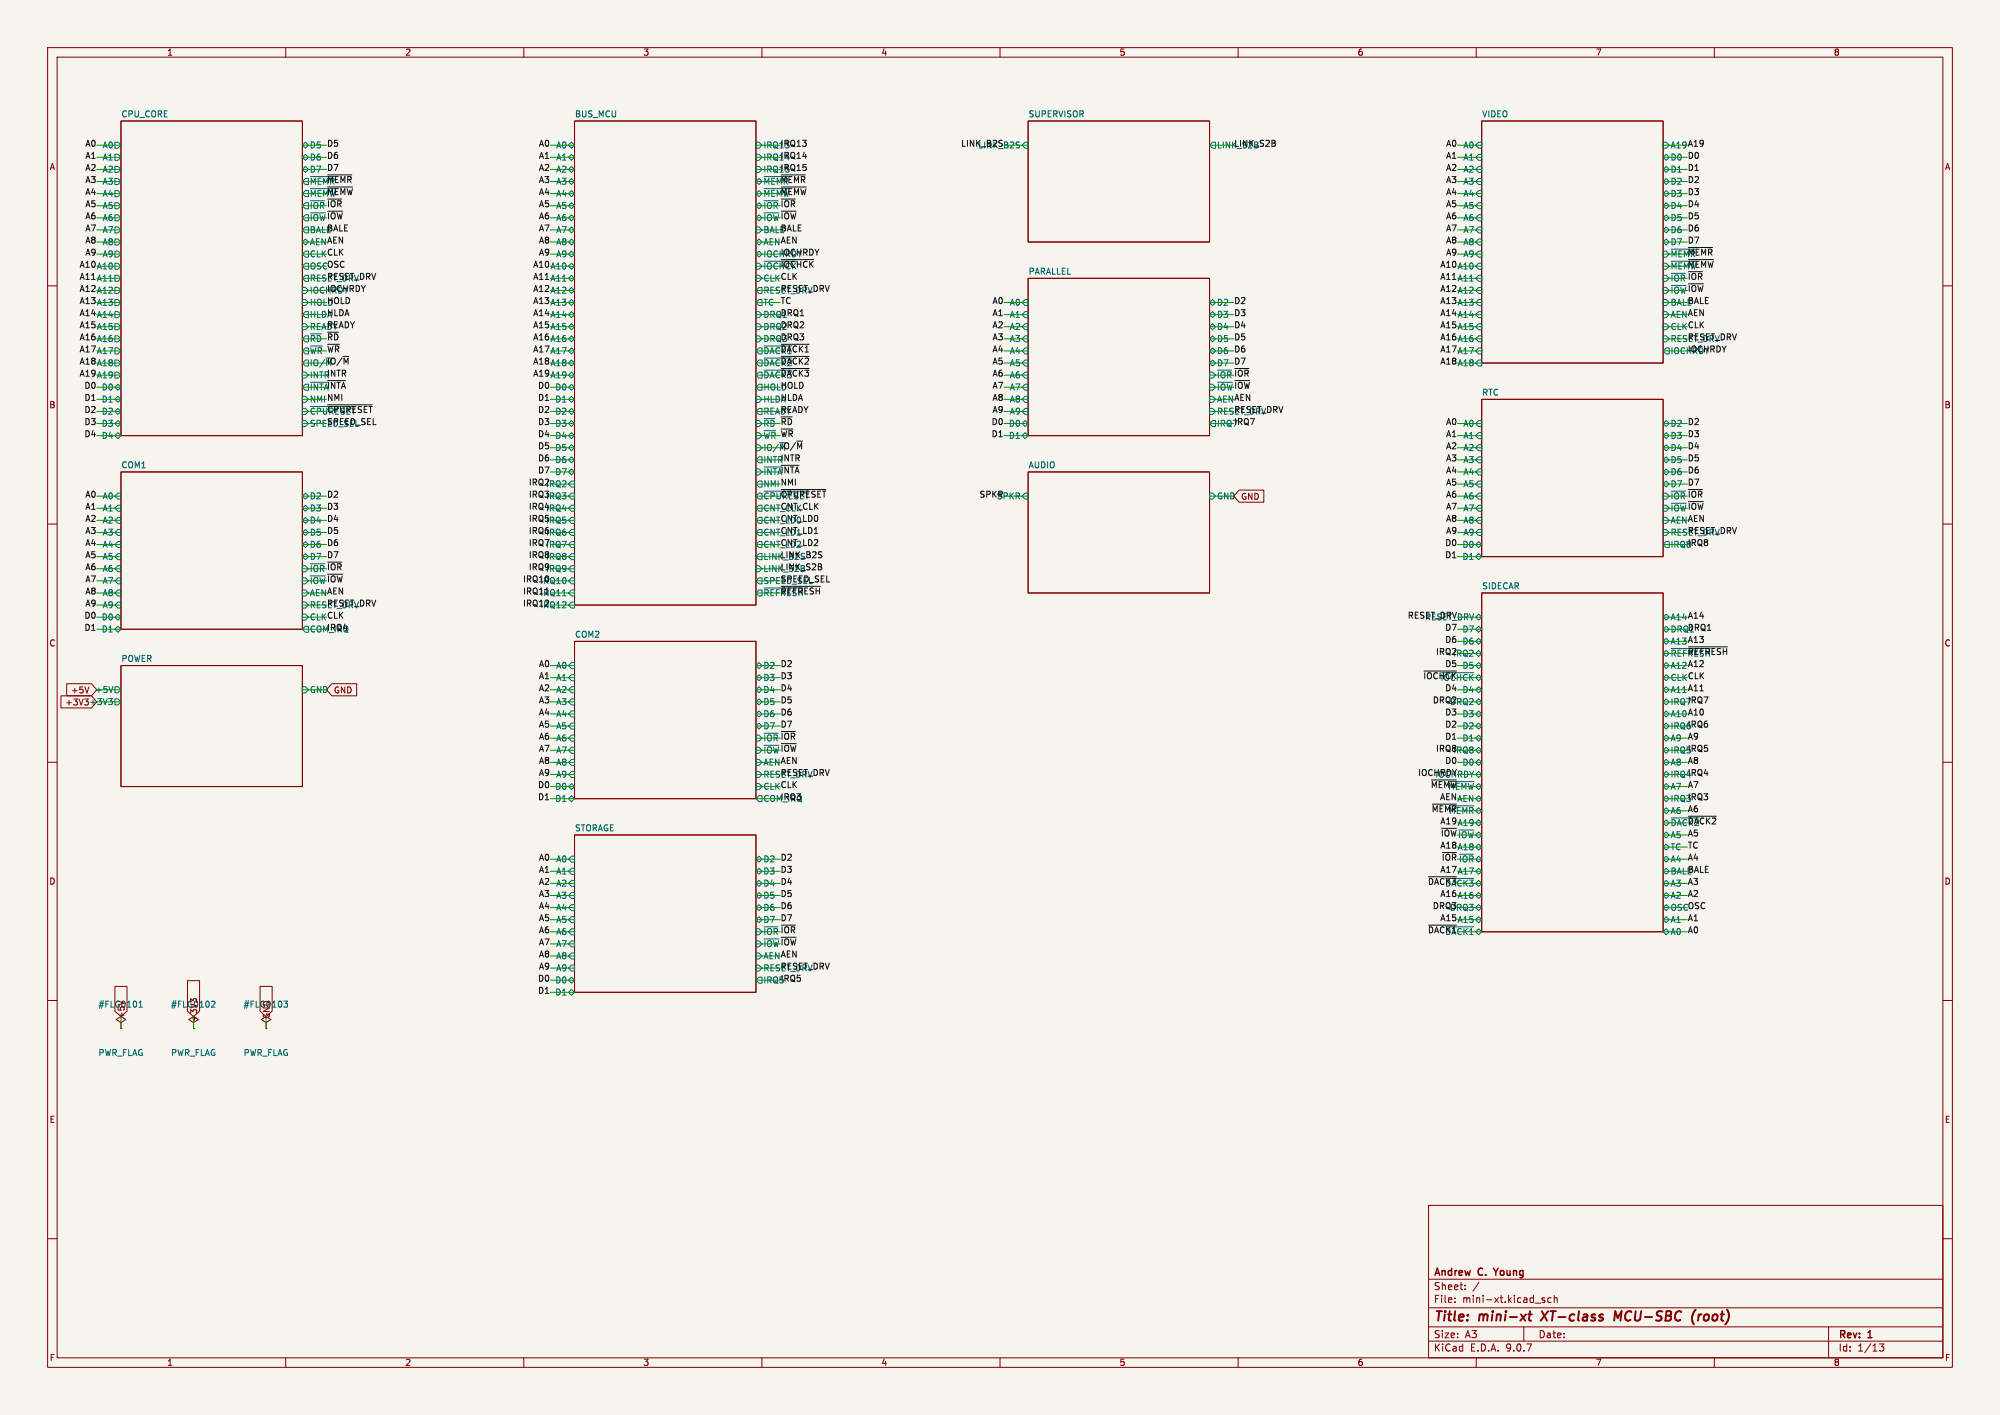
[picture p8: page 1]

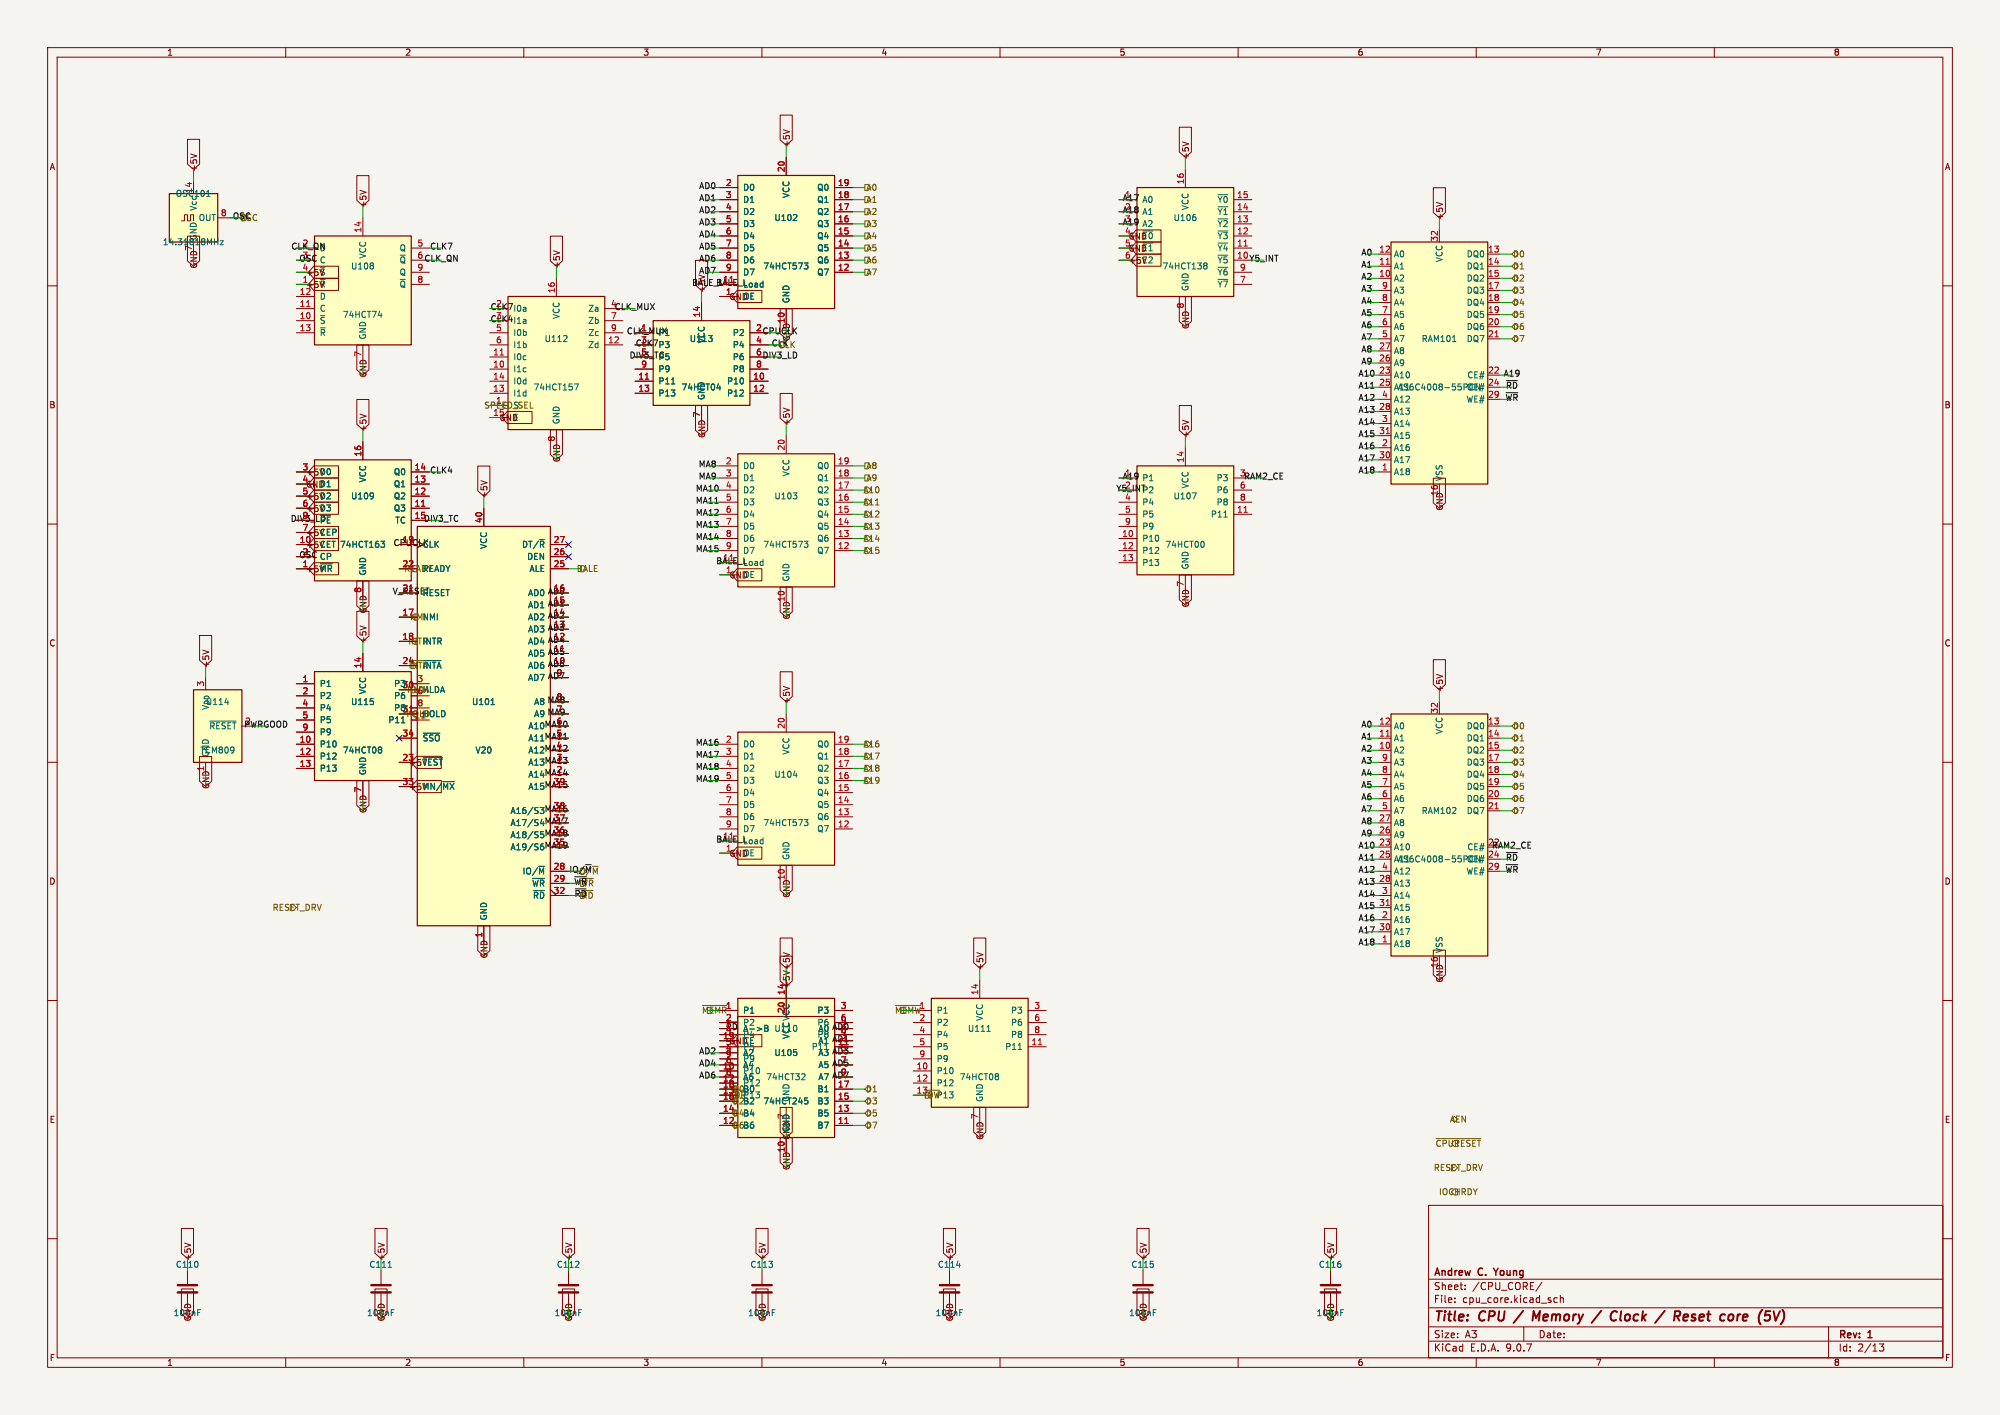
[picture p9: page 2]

A18 A19 AD7 U101 V20 CLK 19 READY 22 RESET 21 NMI 17

CLK 19 READY 22 RESET 21 NMI 17

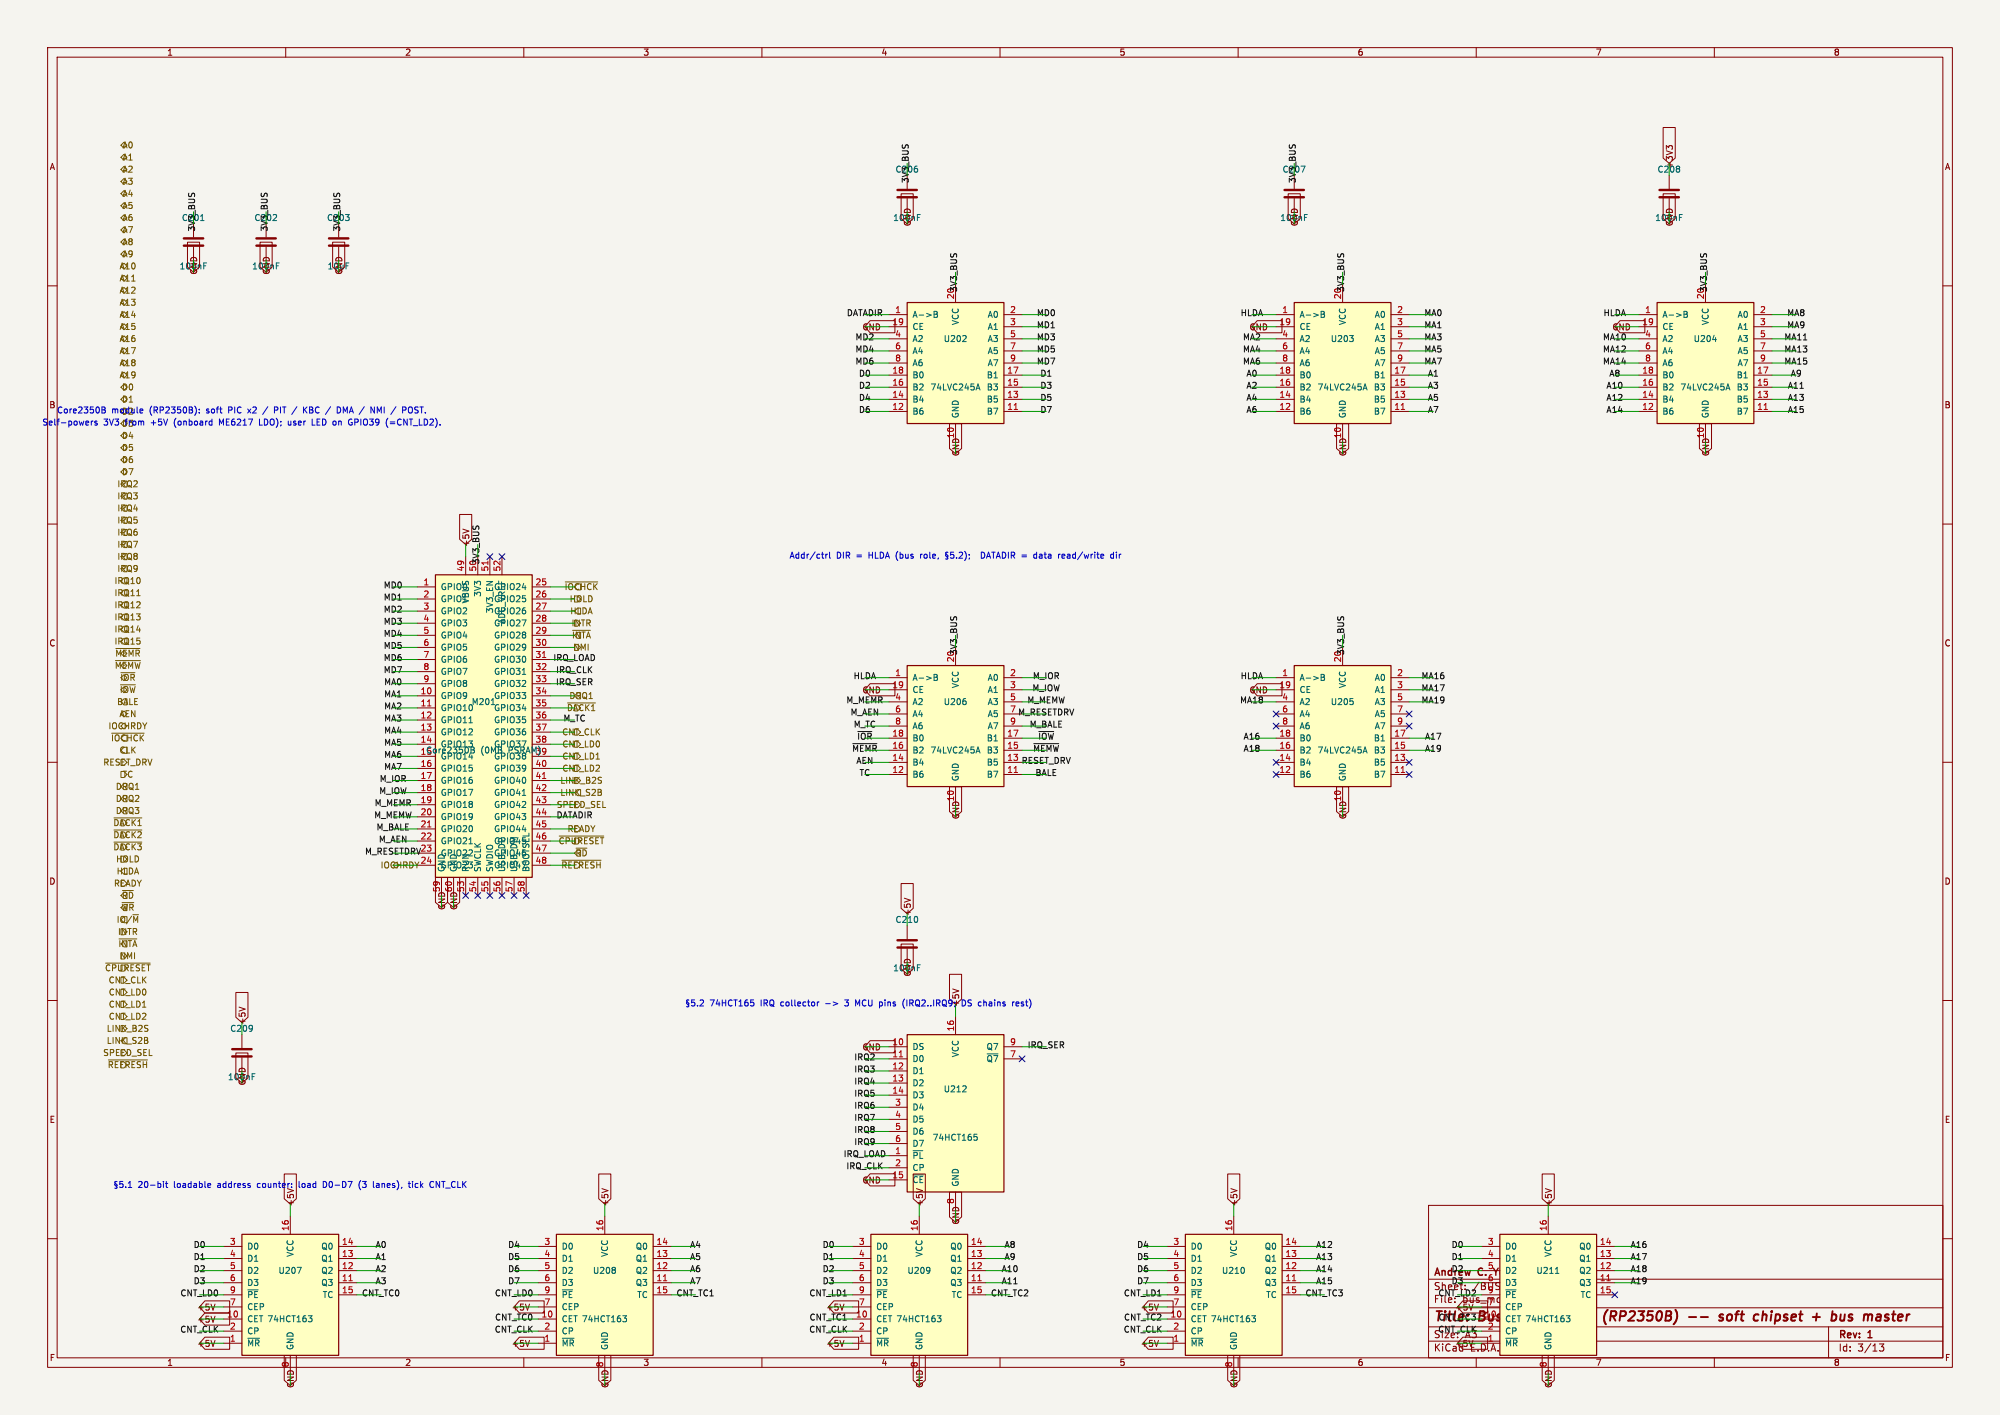
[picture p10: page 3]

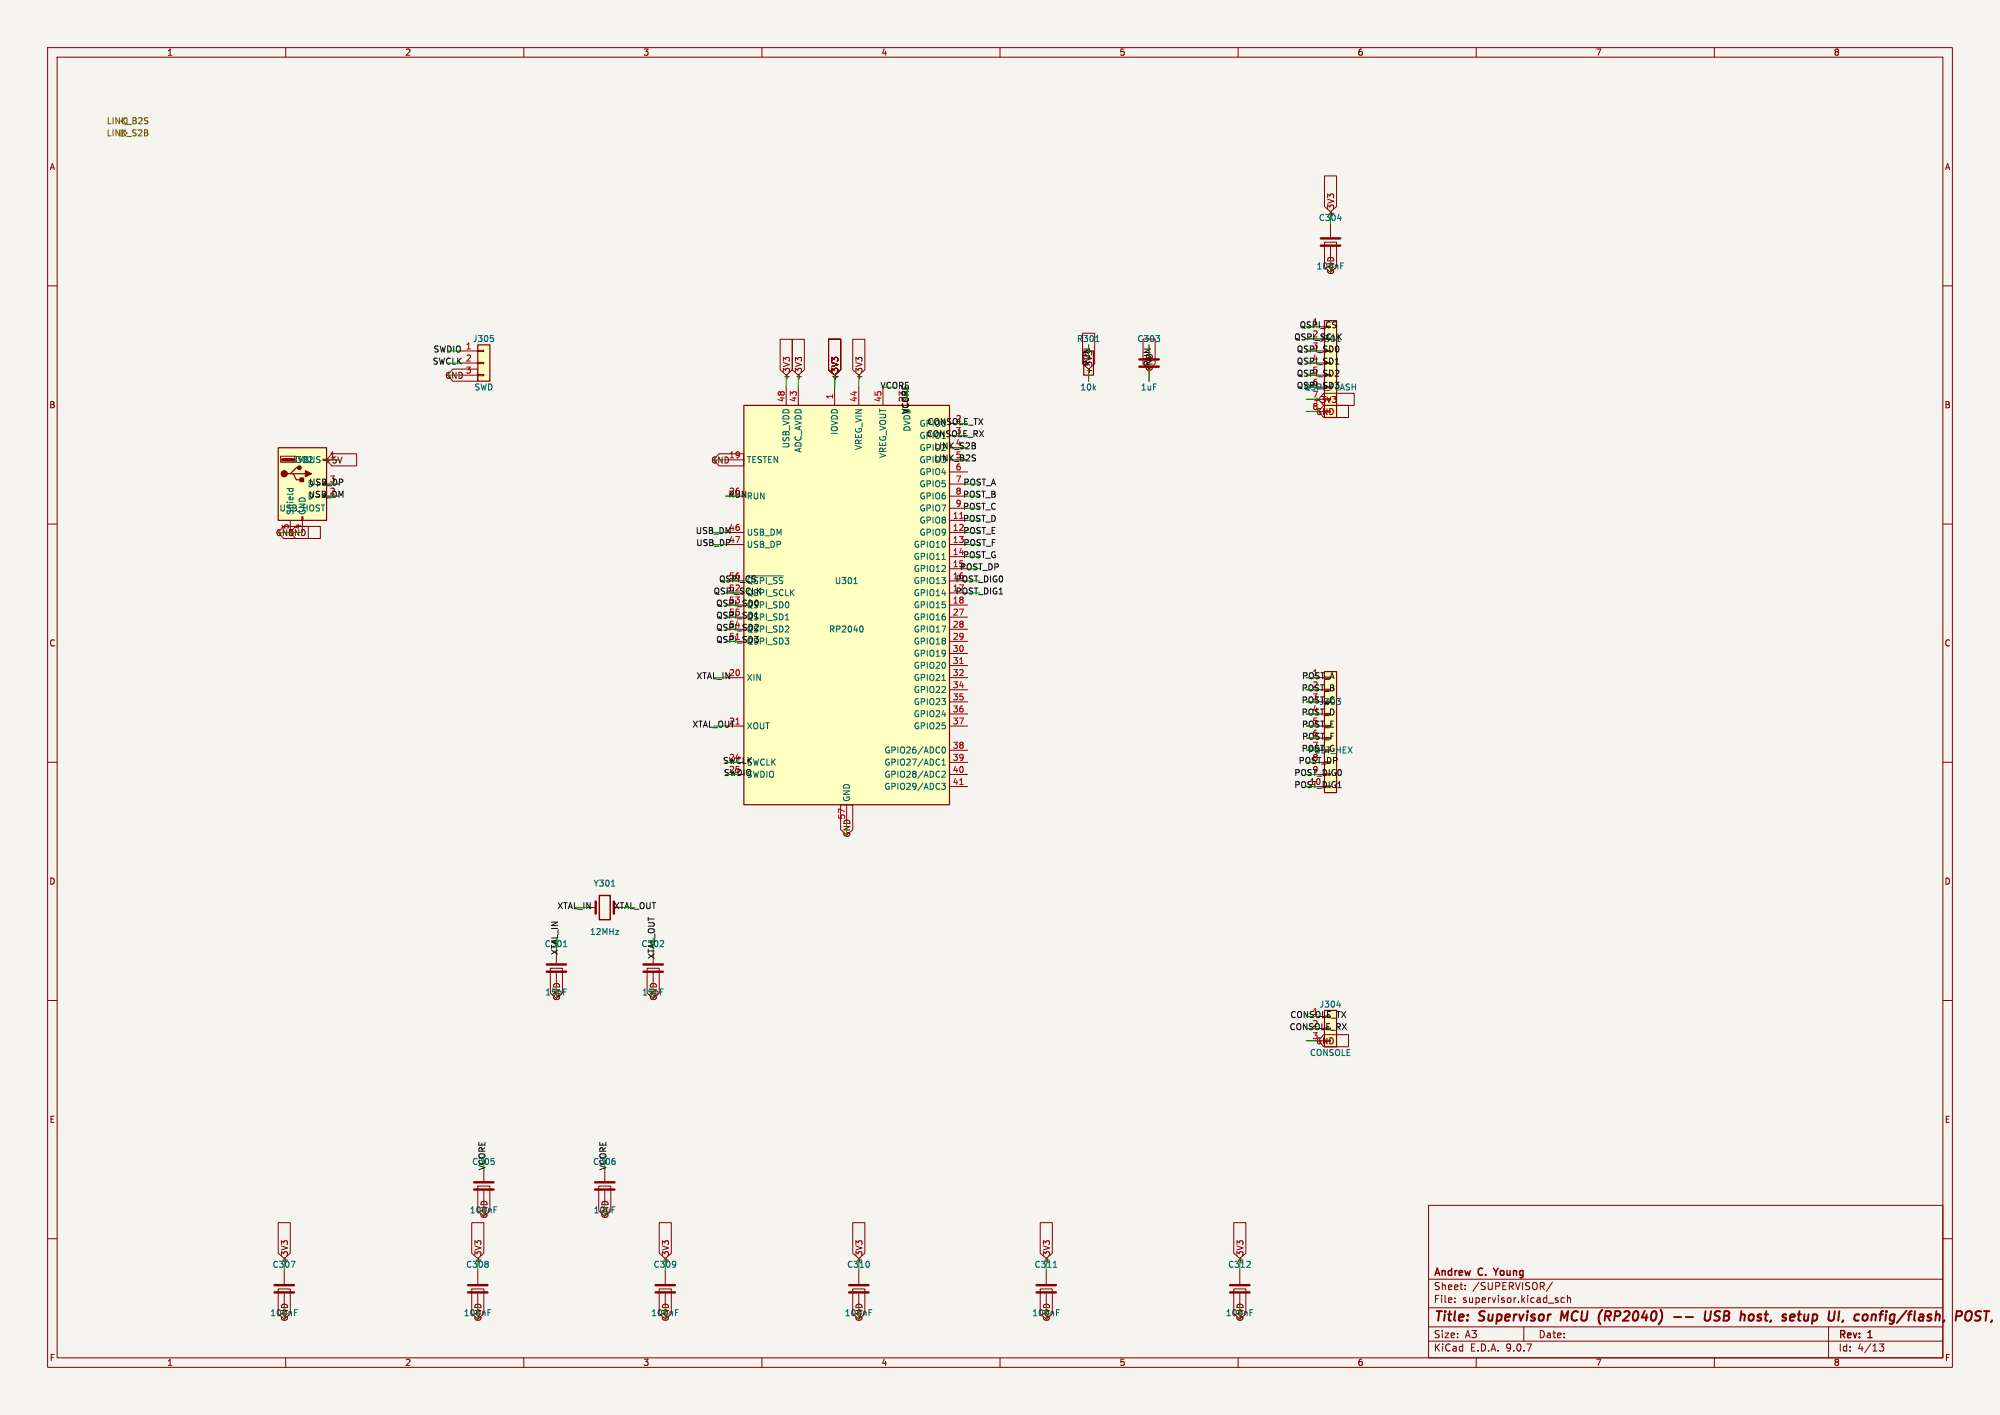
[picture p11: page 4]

File: supervisor.kicad_sch Sheet: /SUPERVISOR/ Andrew C. Young 123456789
POST_B

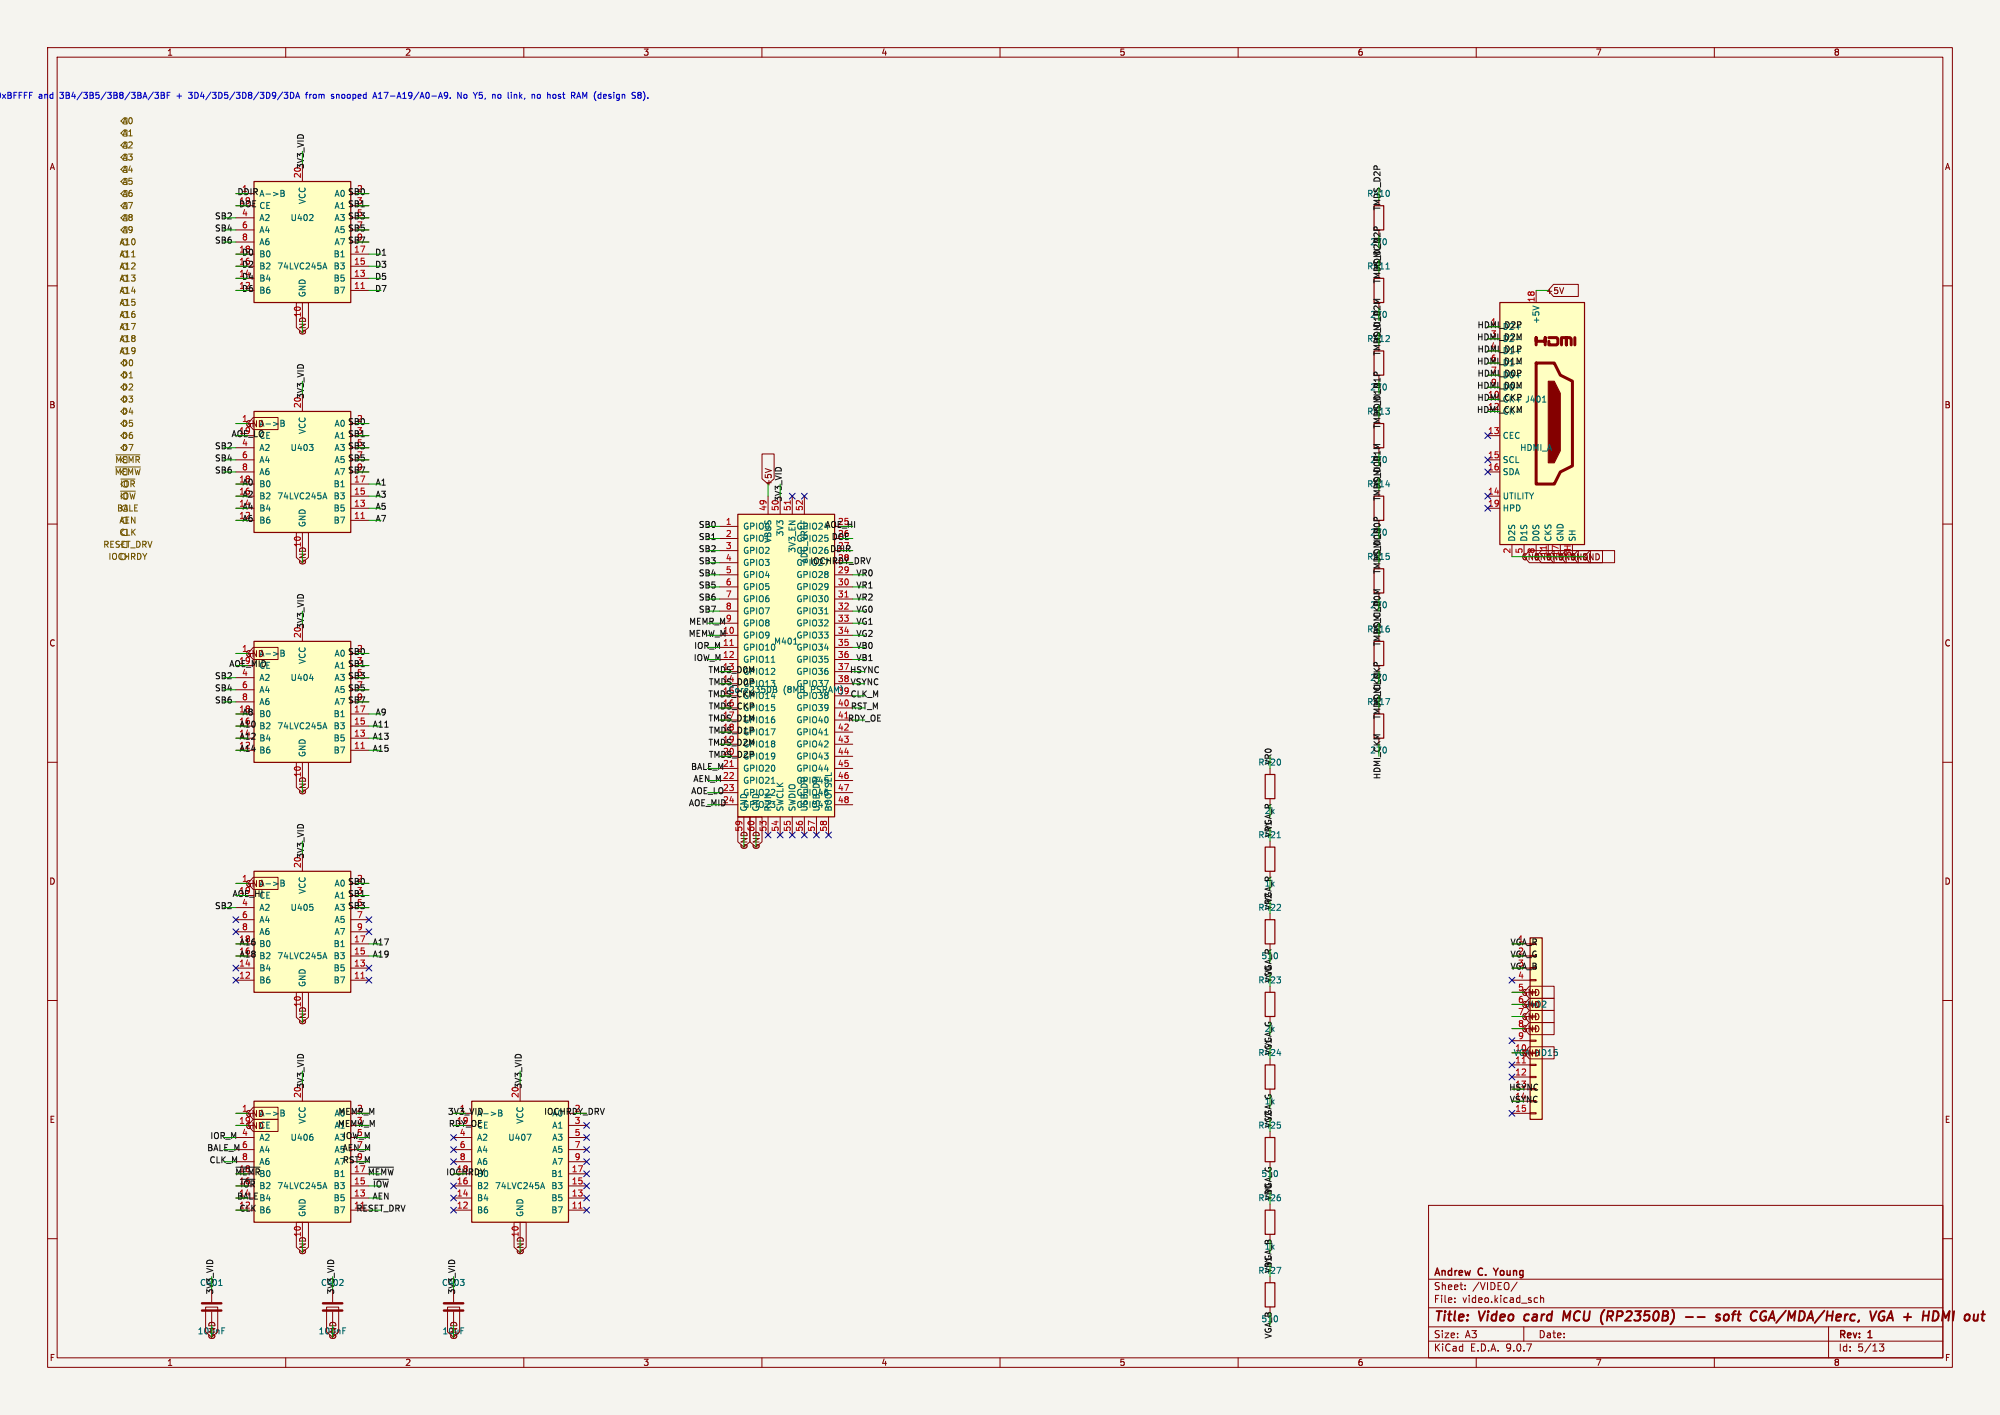
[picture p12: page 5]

GNDGND GND GND GND

GND GND

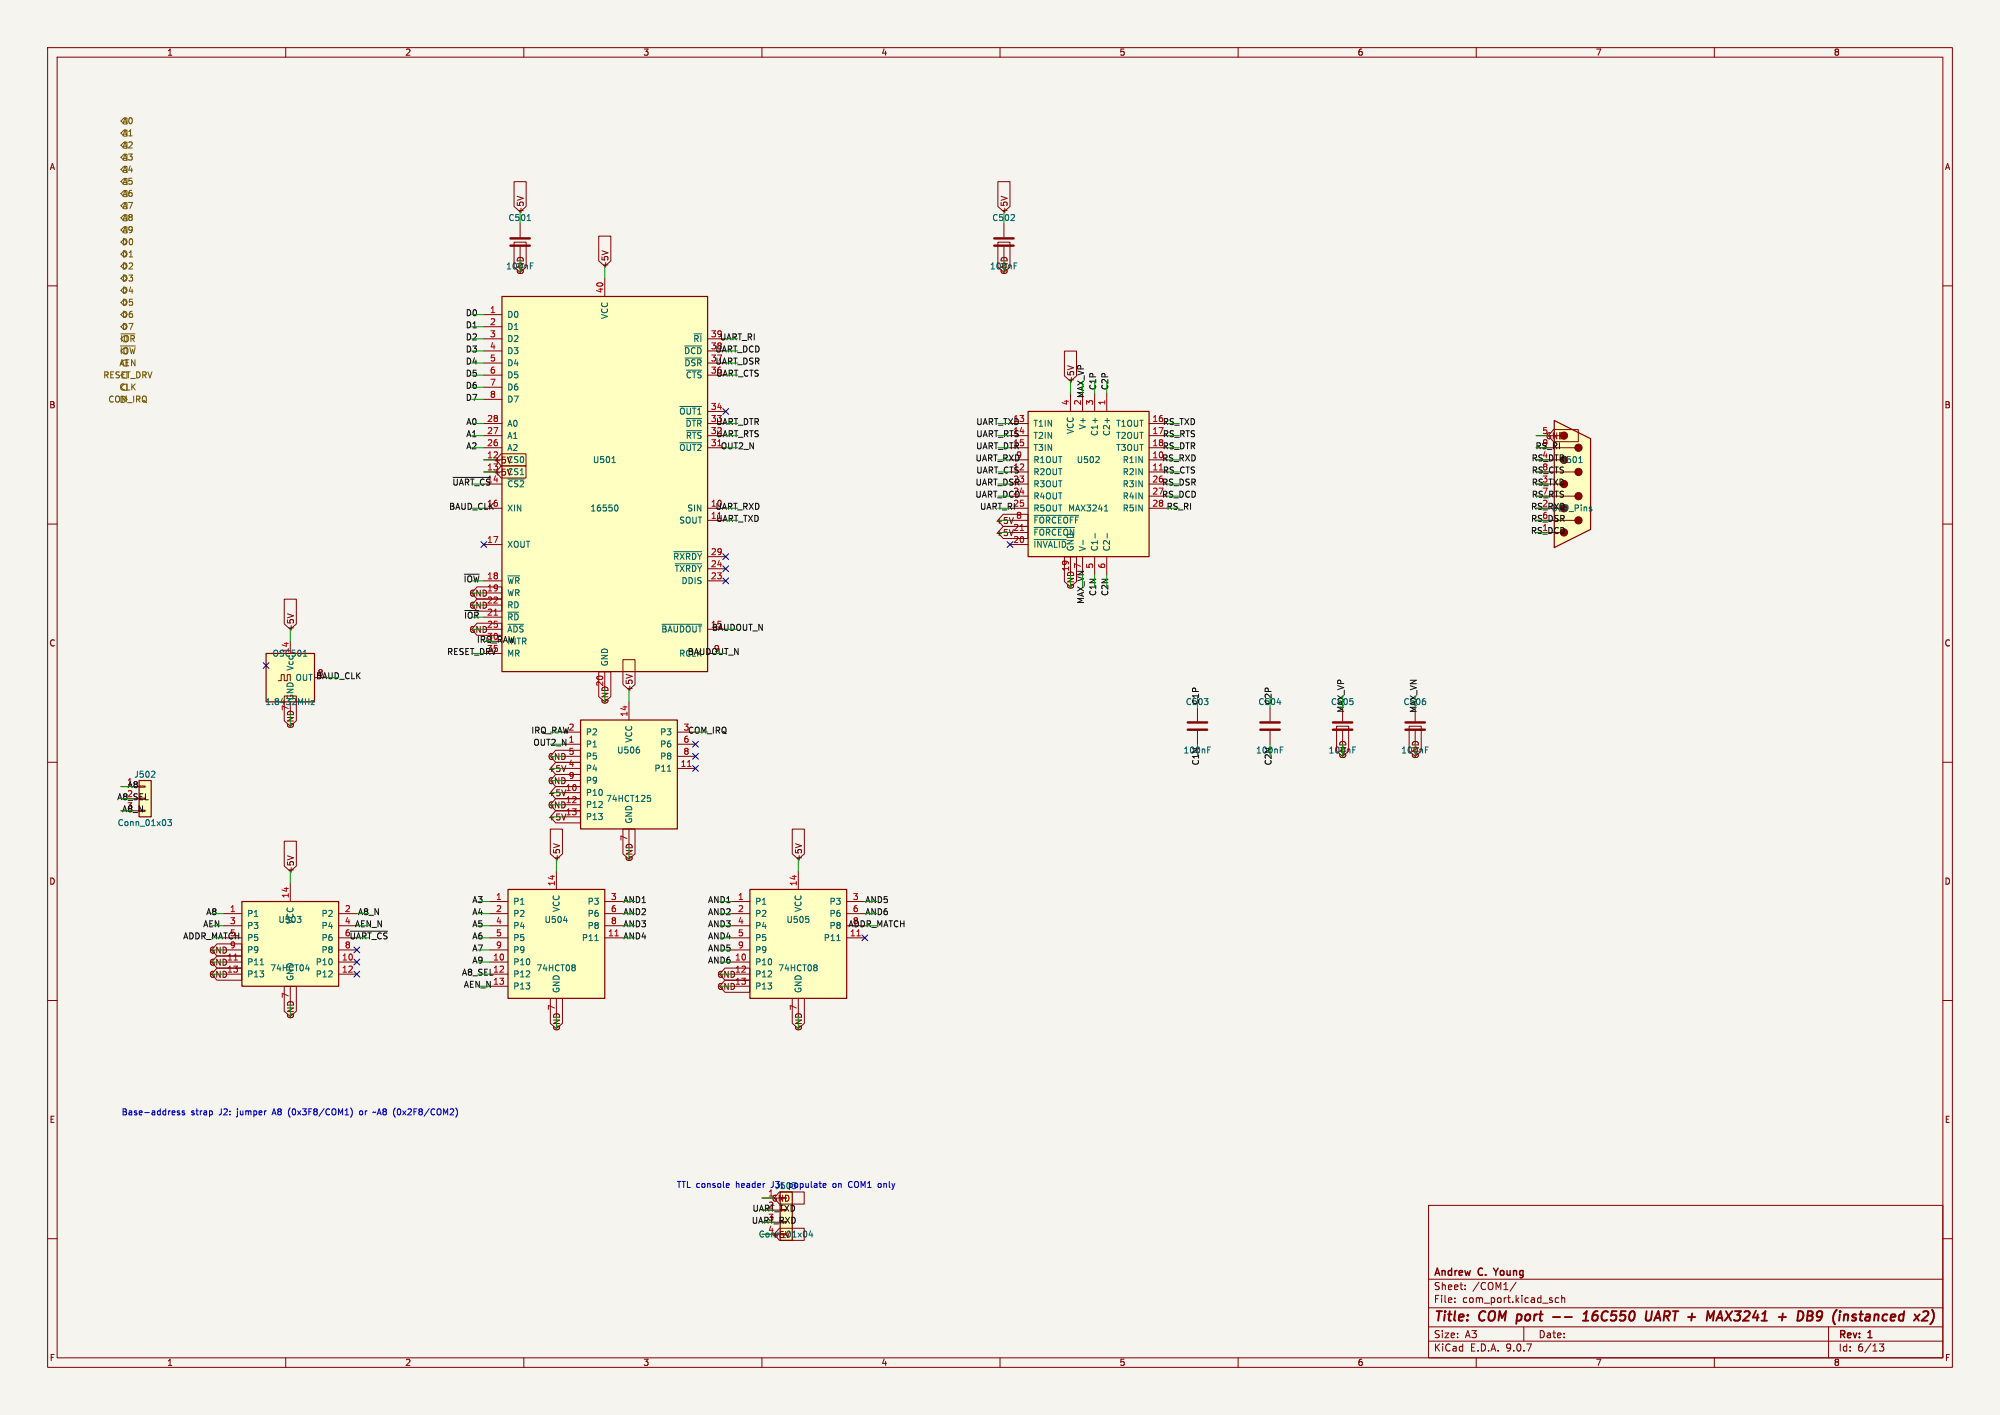
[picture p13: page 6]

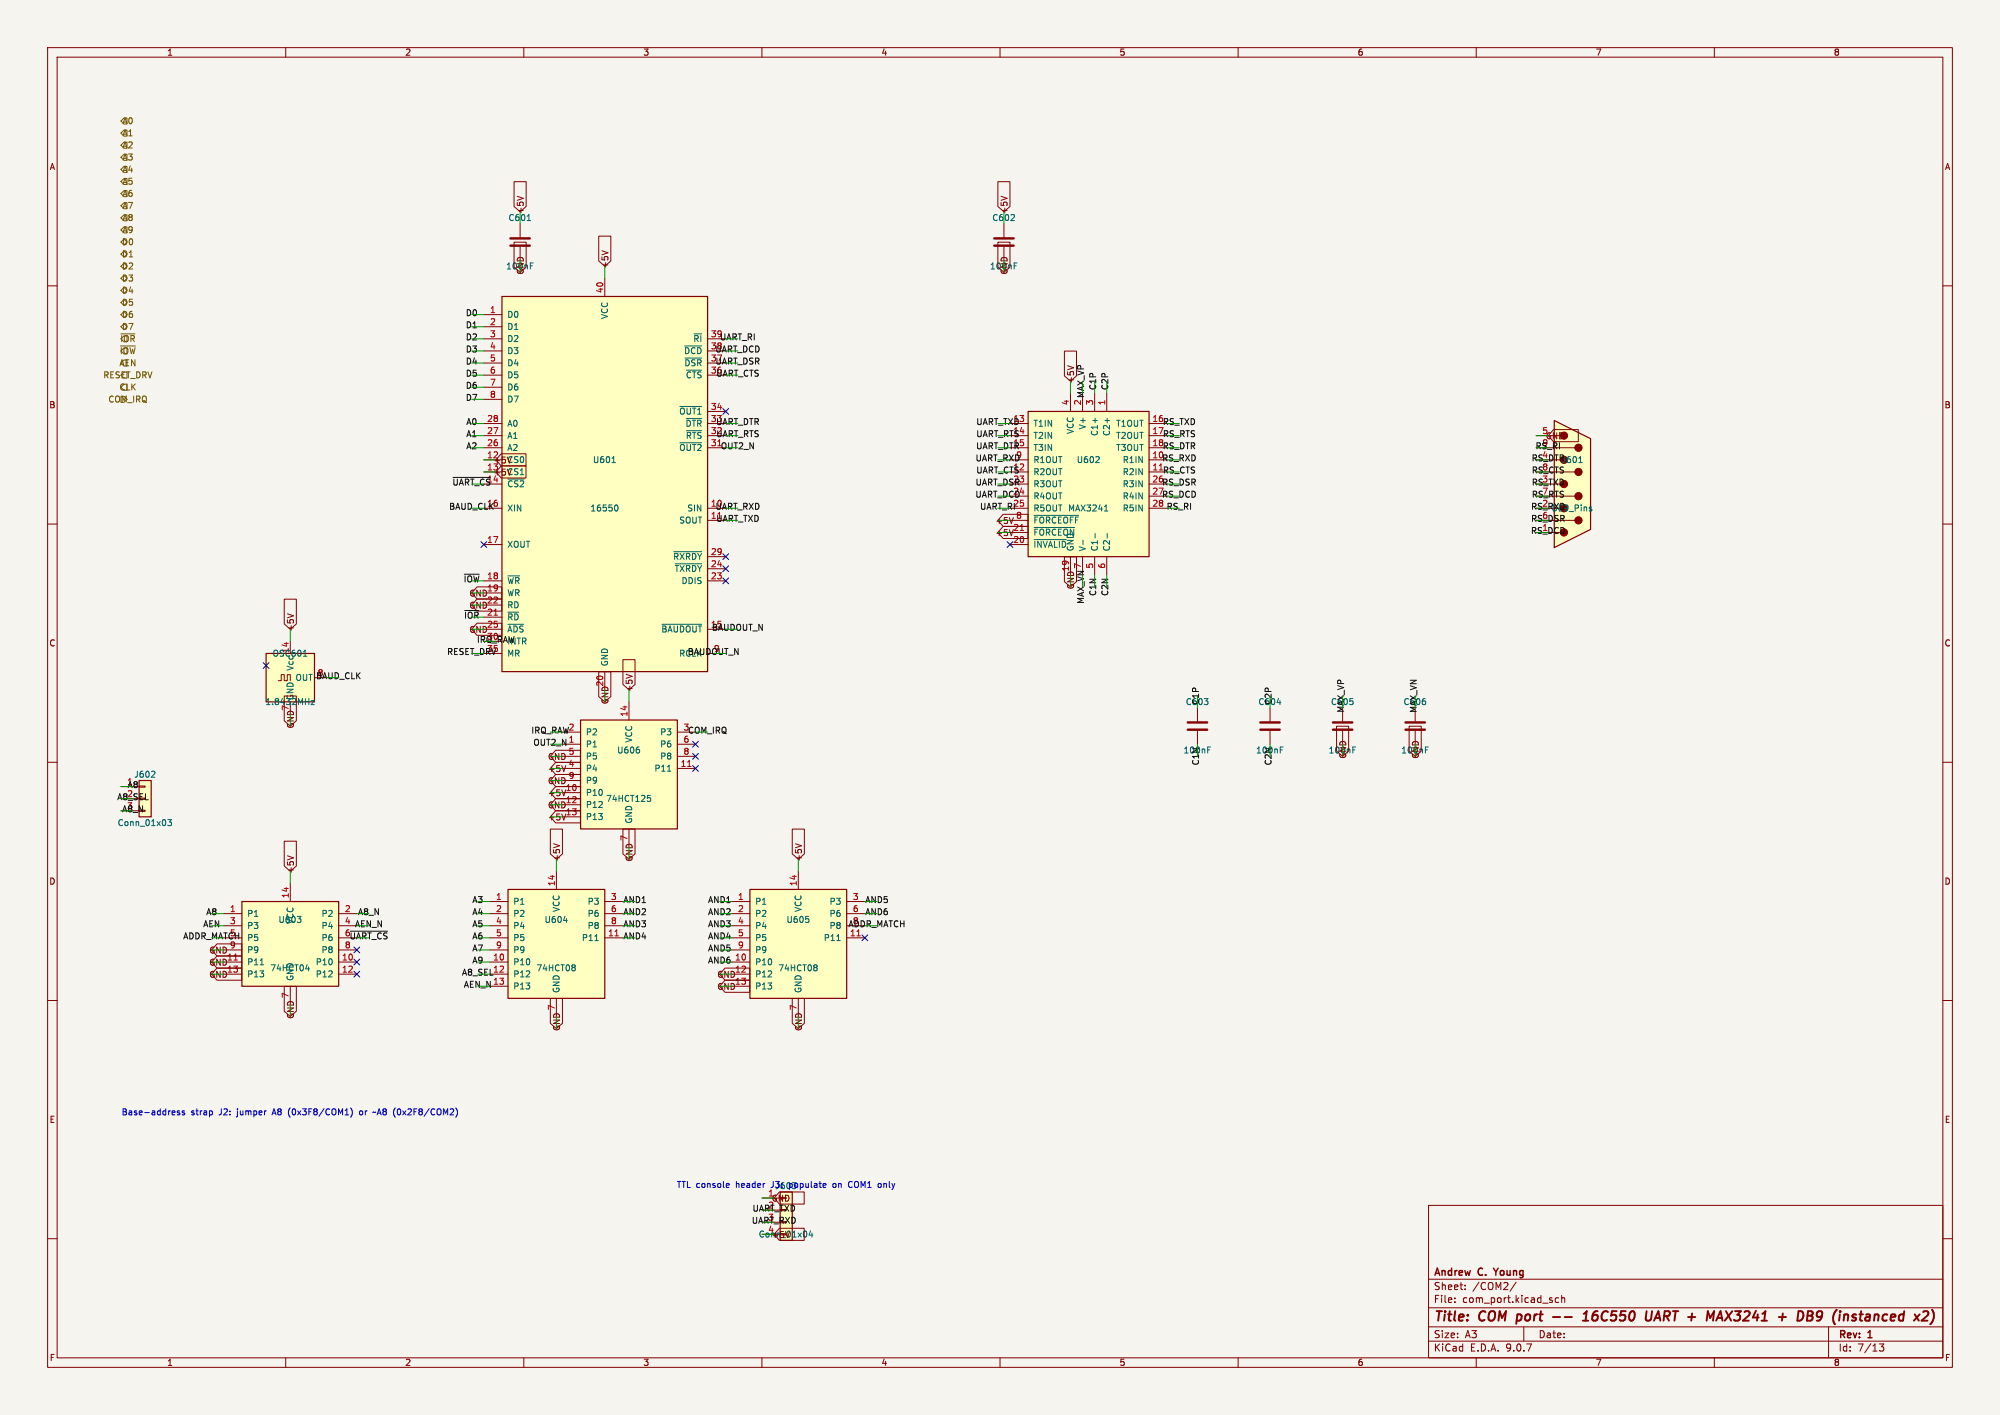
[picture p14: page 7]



File: rtc.kicad_sch Sheet: /RTC/ Andrew C. Young



File: storage.kicad_sch Sheet: /STORAGE/ Andrew C. Young C1002



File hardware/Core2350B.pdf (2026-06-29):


1V1 3V3 | XTAL | VBUS U1 3V3

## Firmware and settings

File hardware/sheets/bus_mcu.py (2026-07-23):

"""bus_mcu -- Bus Master MCU (RP2350B): soft chipset + bus master (design doc S5).

This is the heaviest sheet: the RP2350B "fast hands" node sits on the buffered
XT/ISA backplane as **slave and master**.  It carries:

  * M1  Core2350B module (RP2350B) -- the Bus MCU; self-powers 3V3 from +5V via D1 (SS34 Schottky diode-OR).  Soft dual-8259 PIC, 8254 PIT, 8255/8042 KBC,
        8237 DMA, NMI mask, POST snoop -- all in firmware on core0+PIO / core1.
        Ports 0x70/0x71 (RTC index/data) are ALSO emulated here in firmware --
        backed by the PCF8563 I2C RTC on the Supervisor sheet (off-bus), time
        synced over the existing UART link at boot (spec 2026-07-14; see
        hardware/notes/questions-supervisor.md).
  * NO local transceivers (3.3V bus redesign, spec 2026-07-14): the RP2350B GPIOs
        sit on the 3.3V ISA bus DIRECTLY -- they are 5V-tolerant and tri-state
        natively for master/slave role changes.  The six 74LVC245A that bridged
        the old 5V bus (U2 data, U6 strobes, U3/U4/U5 address+BALE, U13 AEN/TC)
        and their DIR logic are DELETED; each GPIO now carries its bus net 1:1
        (see GPIO_NET).  DATADIR's sole consumer (U2 DIR) is gone, freeing GPIO43
        -> reused as EXP_DDIR.  RN3/RN4 (10kx4 arrays) park AEN/TC/HLDA at a defined level
        during the MCU-Hi-Z (BOOTSEL/reset) window (AEN idle-low so cards read
        their I/O decode deasserted; HLDA low so the counter's '244s stay off).
  * External 20-bit loadable address counter (§5.1): U7..U11, 5x 74HCT163
        cascaded.  Loaded from D0-D7 (3 byte-lanes steered by CNT_LD0/1/2);
        advanced one byte per CNT_CLK pulse.  Cuts master-cycle address cost
        from ~20 GPIO to ~4.  The '163 has NO output enable, so the counter
        reaches A0-A19 through U14-U16 (74HC244 @ 3V3, ~OE = ~HLDA): enabled only
        while the MCU owns the bus, opposite the cpu_core '573s (OE = HLDA) --
        the 8282-style address handoff.  These '244s STAY in the 3.3V design
        (they are the counter's only tri-state; deleting them would fight the
        '573 latches on A0-A19 during CPU cycles).
  * RESET_DRV is NOT driven here: the MCU sequences reset via ~{CPURESET} and
        cpu_core's NAND combine drives V20 RESET + bus RESET_DRV.
  * IRQ collector (§5.2): ONE 74HC165 PISO (U12) + ONE 74HC32 OR rank (U19) --
        8-bit shift onto 3 pins (IRQ_LOAD / IRQ_CLK / IRQ_SER). The '32 merges
        the four internal IRQs that share a header pin with the expansion port
        (IRQ3/4/5/7 | EXT_IRQ3/4/5/7); EXT_IRQ2/6 (no internal source) feed the
        '165 directly. 2026-07-14 consolidation: replaced the 3-chip 24-bit
        chain (U12/U19/U20) after EXT_DRQ1-3 were deleted with ISA-card DMA.
  * UART cross-MCU link to the Supervisor (§5.3): LINK_B2S (TX), LINK_S2B (RX).
  * FULL 10-bit I/O decode (2026-07-20): A8 (GPIO42) and A9 (GPIO46) are
    sensed directly alongside A0-A7 -- no more 8-bit-alias hazard (0x020 vs
    the PicoGUS's 0x220; COM3 0x3E8 vs an expansion COM4 0x2E8). GPIO42 was
    freed by moving SPEED_SEL to a cpu_core jumper strap (JP1 there: open =
    7.16 MHz default, fitted = 4.77 MHz); GPIO46 by dropping the redundant
    raw ~{RD} sense (reads always show on the gated ~{MEMR}/~{IOR}).
  * Expansion-port DMA channel (2026-07-14): EXT_DRQ arrives via the '165
    scan (U12 D6, the spare lane); ~{EXT_DACK} is driven from GPIO47 --
    reclaimed from ~{REFRESH}, which was retired with the 50-pin header
    (no DRAM-refresh support on the port; the port-61h bit-4 refresh toggle
    stays firmware-internal). Separate nets from the internal PicoGUS ch1
    pair (DRQ/~{DACK}) so a port card never sees the on-board acknowledge.
  * SPKR (out) -> audio sheet: PIT ch2 tone / port-61h speaker gate PWM (GPIO22; the bus-CLK
    sense was dropped for it -- PIO tracks bus timing from BALE/strobes).

Data/address/strobe are wired GPIO<->bus directly (no transceivers, no DIR
nets); master/slave role is a firmware tri-state.  HLDA still gates the
counter's '244 output stage (inverted to ~{HLDA} on the parallel sheet's
spare Schmitt gate -- the old U17 hex inverter is deleted).  The expansion
port's isolated EXT_IRQ lines enter the same single-'165 scan via U19's OR
gates (EXT_IRQ2/6 directly).
See hardware/notes/questions-bus_mcu.md for design picks.
"""
import mxbus
from mxbus import pin

NAME = "bus_mcu"
TITLE = "Bus Master MCU (RP2350B) -- soft chipset + bus master"

# ---- interface (hierarchical) pins, with sensible directions --------------
_DIR = {
    # ISA control / status
    "~{MEMR}": "bidirectional", "~{MEMW}": "bidirectional",
    "~{IOR}": "bidirectional", "~{IOW}": "bidirectional",
    "BALE": "input", "AEN": "output", "IOCHRDY": "bidirectional",
    "~{IOCHCK}": "input", "TC": "output",
    # (DRQ2/3 + ~{DACK2/3} retired 2026-07-14; ch1 renamed to plain DRQ /
    # ~{DACK} -- it is the board's only internal channel, hardwired to the
    # PicoGUS. The expansion port has its OWN pair, EXT_DRQ / ~{EXT_DACK}.)
    "DRQ": "input",
    "~{DACK}": "output",
    # private V20 <-> Bus MCU
    "HOLD": "output", "HLDA": "input", "~{HLDA}": "input", "READY": "output",
    "INTR": "output", "~{INTA}": "input", "NMI": "output", "~{CPURESET}": "output",
    "LINK_B2S": "output", "LINK_S2B": "input",
}
_CTRL = ["~{MEMR}", "~{MEMW}", "~{IOR}", "~{IOW}", "BALE", "AEN", "IOCHRDY",
         "~{IOCHCK}", "TC", "DRQ", "~{DACK}"]
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

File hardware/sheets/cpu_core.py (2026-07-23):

"""cpu_core -- CPU, memory, clock, reset, and the buffered-bus core.

Design doc S3/S4/S7 + 3.3 V single-board redesign (spec 2026-07-14). The V20 and
its demux latches/transceiver ARE the board's single 5 V<->3.3 V boundary: the
V20 runs at 5 V, everything past the boundary latches is a 3.3 V bus.
  * NEC V20 (mini-xt:V20) in min mode -- 5 V
  * 3x 74LVC573A address latches (AD0-7 + A8-A19 -> A0-A19), LE = raw ALE,
    OE = HLDA -> released during Bus-MCU master cycles (address handoff).
    3.3 V-powered, 5 V-tolerant inputs => the address half of the boundary.
  * 74LVC245A data transceiver (D0-D7), DIR = DT/~R, ~OE = DEN -- the data half
    of the boundary (5 V-tolerant CPU side, 3.3 V bus side).
  * 74HCT32 strobe gates (~RD/~WR + IO/~M -> MEMR/W, IOR/W) stay on +5V (they
    read the raw 5 V V20 strobes) behind a 74LVC125A tri-state stage (~OE = HLDA,
    3.3 V bus out) -- the strobe half of the boundary; pull-ups park the bus
    strobes inactive across the handoff gap.
  * 74HC138 + 74HC00 (3.3 V) SRAM chip-select decode (Y5 = video block, internal);
    spare '00 gates NAND the active-low reset sources into V20 RESET + RESET_DRV,
    and invert A0 (-> UB) and Y5 (-> RAM /CE).
  * 1x IS62WV51216BLL 512Kx16 SRAM used as 1Mx8 via the byte-lane trick -> full
    1 MB less the 0xA0000-0xBFFFF video window.
  * single-oscillator clock tree: 14.318 osc -> /2 (74LVC74A) and /3 (74LVC161
    preset-to-3, 3.3 V for fmax margin), 74HC157 select (SPEED_SEL jumper JP1:
    open = 7.16 MHz default, fitted = 4.77 MHz -- was a Bus MCU GPIO until
    2026-07-20),
    74HCT04 5 V buffer (U13) -> V20 CLK, plus 5 V re-buffering of the V20's
    READY/HOLD handshake inputs (the one gate package that MUST stay 5 V: V20 CLK
    needs Vkh = 4.0 V, unreachable from 3.3 V). U13 drives only private V20 nets.
  * 74LVC125A bus re-buffer (U15, 3.3 V): the BALE/CLK bus copies are buffered
    to 3.3 V here -- no 5 V push-pull output may drive a shared bus net (they reach
    the non-5V-tolerant sidecar RP2040). BALE's input is the raw 5 V V20 ALE (LVC
    5 V-tolerant); CLK from CLK7 (3.3 V). (Bus OSC retired 2026-07-14.)
  * TCM809 reset supervisor (cold start) -- 3.3 V so its reset net is clean 3.3 V.

Exposes the buffered ISA backplane plus the private V20<->Bus-MCU side channels.
The Y5 video-block strobe stays internal -- per the portability rule it must
never leave this sheet.
"""
import mxbus
from mxbus import pin

NAME = "cpu_core"
TITLE = "CPU / Memory / Clock / Reset core (5V<->3.3V boundary)"

PINS = (
    [pin(s, "output") for s in mxbus.ADDR] +              # A0..A19 driven by latches
    [pin(s, "bidirectional") for s in mxbus.DATA] +       # D0..D7
    [pin("~{MEMR}", "output"), pin("~{MEMW}", "output"),
     pin("~{IOR}", "output"), pin("~{IOW}", "output"),
     pin("BALE", "output"),
     # (AEN / IOCHRDY intentionally absent: AEN is generated on bus_mcu and
     # IOCHRDY folds into READY there -- nothing on this sheet touches either.)
     # (OSC left the bus contract 2026-07-14 with the 50-pin expansion header:
     # no consumer remained. OSC_3V3 still clocks the dividers sheet-locally.)
     pin("CLK", "output"),
     pin("RESET_DRV", "output")] +
    # private V20 <-> Bus MCU  (~{RD} / ~{WR} / IO/~{M} are ALL sheet-internal
    # since 2026-07-20: the Bus MCU tracks cycles via the gated MEMR/W,IOR/W
    # strobes; its GPIO46 senses A9 instead of raw ~{RD}. SPEED_SEL left the
    # interface the same day -- it is a local jumper strap now, JP1 below.)
    [pin("HOLD", "input"), pin("HLDA", "output"), pin("READY", "input"),
     pin("INTR", "input"), pin("~{INTA}", "output"), pin("NMI", "input"),
     pin("~{CPURESET}", "input")]
)


def build(sch, lib):
    P = lambda c, p, net, **k: sch.net(c, p, net, kind="hier",
                                       shape=k.get("shape", "bidirectional"),
                                       dx=k.get("dx", 2.54), dy=k.get("dy", 0))
    L = lambda c, p, net, **k: sch.net(c, p, net, kind="label",
                                       dx=k.get("dx", 2.54), dy=k.get("dy", 0))

    def pwr(net, at):
        s = mxbus.power_net(sch, lib, net, at)
        return s

    def decouple(ref, at, rail="+3V3"):
        # Board logic is now 3.3 V-domain, so decoupling defaults to +3V3; the
        # few surviving 5 V parts (V20, U10 '32, U13 '04) get explicit +5V caps.
        c = sch.place("Device:C", ref, "100nF", at=at)
        sch.net(c, "1", rail, kind="label", dx=0, dy=-2.54)
        sch.net(c, "2", "GND", kind="label", dx=0, dy=2.54)

    def pullup(ref, net, at, val="10k", rail="+5V"):
        r = sch.place("Device:R", ref, val, at=at)
        sch.net(r, "1", rail, kind="label", dx=0, dy=-2.54)
        sch.net(r, "2", net, kind="label", dx=0, dy=2.54)
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

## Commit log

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2026-06-29 Implement all mini-xt schematic sheets + integrate full project
    12 hierarchical sheet instances (cpu_core, bus_mcu, supervisor, video, COM1/COM2,
    parallel, rtc, power, storage, audio, sidecar), 217 components with unique refs.
    Full project ERC-loads, netlist exports, 13-page PDF renders. Cross-sheet
    connectivity verified: shared ISA bus (A/D/IRQ/control) spans the cards, private
    signals (HOLD/HLDA, UART link, SPEED_SEL, counter strobes) stay between the
    motherboard MCUs, power rails global. Per-instance net remap routes COM1->IRQ4,
    COM2->IRQ3 into the Bus-MCU IRQ collector.
    Generator improvements: global power-net promotion, flat TL072, per-instance
    net remap, extends resolution, grid snapp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
    [audio.kicad_sch, bus_mcu.kicad_sch, com_port.kicad_sch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]
2026-06-29 Standardize 5V glue on 74HCT; fix bus-latch family; div-3 -> 74HCT163
    All 5V 74-series logic moved from mixed HC/HCT to 74HCT (TTL thresholds reliably
    read 3.3V level-shifter outputs). Fixes the address latches / data transceiver
    that were wrongly 74HC instead of the design's 74HCT. The div-by-3 moves from
    74HC4017 (no HCT variant) to a 74HCT163 preset-to-3 with a spare 74HCT04 gate
    for the TC->~PE reload. Per-card level shifters use a dedicated 74LVC245A symbol.
    Pinouts unchanged; netlist intact; zero structural ERC errors.
    [audio.kicad_sch, bus_mcu.kicad_sch, com_port.kicad_sch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]
2026-06-29 Move speed-select latch from Supervisor to Bus MCU
    SPEED_SEL now originates on the Bus MCU (GPIO42) and drives the cpu_core clock
    mux; the Supervisor sends the divisor choice over the UART link instead, dropping
    its cross-sheet interface to the 2-wire link + power. To stay within the 48-GPIO
    budget, the address/control transceiver direction is now HLDA-derived externally
    (per S5.2) rather than a dedicated BUSDIR GPIO. Bus MCU now owns both reset
    sequencing and speed-select. Netlist verified; zero structural ERC errors.
    [audio.kicad_sch, bus_mcu.kicad_sch, com_port.kicad_sch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]
2026-06-29 Use Waveshare Core2350B modules for both RP2350B nodes
    Replace the bare RP2350B on bus_mcu and video with the Core2350B module
    (mini-xt:Core2350B, 64-pin PGA, all 48 GPIO + power/control). Each module takes
    +5V on VBUS and self-generates 3V3 (onboard ME6217 LDO) that powers its own local
    level shifters (3V3_BUS/3V3_VID, sheet-local, not paralleled). Bus MCU uses the
    0MB-PSRAM variant (GPIO47 free); video uses the 8MB variant (onboard PSRAM is the
    VGA aperture, discrete APS6404 removed). Drops the per-site core SMPS/inductor,
    flash, and crystal. Netlist verified; modules self-power from +5V; zero structural
    ERC errors.
    [audio.kicad_sch, bus_mcu.kicad_sch, com_port.kicad_sch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]
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2026-07-03 Fix all critical+high design-review findings (C1-C5, H1-H8)
    Full review in hardware/notes/design-review-2026-07-03.md (with per-item
    fix logs). Highlights:
    - SRAM strobed by gated MEMR/MEMW (was raw ~RD/~WR: I/O cycles corrupted
    SRAM and the boot shadow-load could never write it)
    - Reset chain implemented: NAND combine of ~PWRGOOD + ~CPURESET drives
    V20 RESET and an always-driven RESET_DRV (dropped from the Bus MCU)
    - Contention-free bus handoff: '573 OE=HLDA vs counter '244 stage
    ~OE=~HLDA; strobe gates wired + tri-stated ('125, ~OE=HLDA); Bus MCU
    address group fixed to sense; AEN/TC fixed drive; BALE input-only
    - '573 LE driven by BALE (was a dangling BALE_L label)
    - Data '245 DIR=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
    [audio.kicad_sch, bus_mcu.kicad_sch, card_com.kicad_sch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]
2026-07-03 Fix all medium design-review findings (M1-M8)
    - M1: Supervisor link moved to GPIO4/5 (real UART1 pair); POST -> GPIO6-15
    - M2: CNT_RUN = LD0.LD1.LD2 gates every '163 CEP (load-cascade hazard)
    - M3: ~WR / IO-M pruned to cpu_core-internal; DRQ2/3 pulled + noted;
    doc S5.2 "as built: 48/48" + S16 updated
    - M4: true XT-IDE rev-2 map (A0<->A3 swap): data 0x300, latch 0x301,
    CS1 0x307/0x30F, drive DA0 = bus A3 - matches XTIDE UB "rev 2" type
    - M5: COM4 -> bus IRQ2 line (IRQ9 via AT redirect); IRQ10/11/14/15 marked
    off-header; ~REFRESH added to mxbus ISA_CTRL; questions-sidecar superseded
    - M6: card_isatest clock tree on unswitched V5RAW (spec S8)
    - M7: card_isatest IRQ2-8/DRQ1-3 idle pull-dow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
    [audio.kicad_sch, bus_mcu.kicad_sch, card_com.kicad_sch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]
2026-07-03 Fix all low-severity + toolchain design-review findings
    Low:
    - LPT IRQ7 via tri-state '125 (NAND-enabled ack pulse) - shareable line
    - card_com JP2 IRQ strap follows the base-address strap (was IRQ4-only)
    - Supervisor USB-A VBUS fused (500mA polyfuse)
    - card_isatest: DUT_PWR_EN moved to the control '595 (addr shifts can't
    glitch DUT power); '165s -> 74HC grade (HCT needs VCC 4.5-5.5V)
    - /3 duty comments corrected; U13 marked load-bearing inverting buffer
    - RTC AS hold-path bench note; duplicate ~RD stub removed
    - mxbus PRIV_DECODE emptied (Y5 never leaves cpu_core)
    Toolchain:
    - build.py/build_cards return real exit codes, failing on structural ERC
    (endpoint_off_grid/unconnected_wire_end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
    [audio.kicad_sch, bus_mcu.kicad_sch, card_com.kicad_sch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]
2026-07-03 JLCPCB sourcing pass: verify pinouts, LCSC part numbers, SMD build
    Custom-symbol verification (open-questions Q5 resolved):
    - MAX3241 symbol was wrong on nearly every pin and used MAX3243-style
    control names; regenerated to the real SSOP-28 pinout (SHDN#/EN#/
    R1OUTB/R2OUTB) and com_port rewired -- EN# must be GROUNDED (the old
    ~FORCEON-high would have disabled the receivers on real silicon)
    - DS12C887 symbol wrong on 4 pins (DS=17, RESET#=18, IRQ#=19, SQW=23)
    Sourcing (every part checked against the JLC DB; ~45 line items):
    - New tools/parts.py maps (lib_id, value) -> LCSC; build.py applies it as
    an 'LCSC Part Num' property on every component (384 across the project)
    - Sheets stay g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
    [audio.kicad_sch, bus_mcu.kicad_sch, card_com.kicad_sch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]
2026-07-03 COM cards: socket the 16550s (SMD PLCC-44)
    The fab reflows a Nextron SMD PLCC-44 socket (LCSC C2828044, ~$0.39) in
    the normal SMD pass; the UART installs by hand. One footprint accepts the
    active-production TL16C550CFNR (Mouser ~320 pcs), NOS tubes, and period
    NS16550AFN pulls (same industry PLCC pinout), and a suspect UART is
    diagnosed by swap. MaxLinear's PLCC ST16C550CJ44-F is EOL; TI's reel CFNR
    is the active leg. Schematic unchanged (parts.py retarget + comments);
    DB9s stay THT (C141880) -- SMD D-subs cost 5-9x and shear pads under
    cable torque. Sourcing notes + CLAUDE.md socket policy updated.
    [card_com.kicad_sch, com_port.kicad_sch]
2026-07-03 Swap DIP sockets to machined-pin versions
    V20 DIP-40 -> C2874018, SRAM DIP-32 x2 -> C2874017, DS12C887 DIP-24 ->
    C2684765 (all round-hole/machined, verified 600 mil row spacing).
    Better grip and repeated-insertion tolerance for the vintage chips;
    ~$2.50/board-set over stamped tin. Stamped fallbacks noted in
    jlcpcb-sourcing.md.
    [card_rtc.kicad_sch, cpu_core.kicad_sch, rtc.kicad_sch]
2026-07-03 Core2350B: record verified module physical details (no castellations)
    Module photos added (hardware/Core2350B0-details-*.jpg): 25.4x25.4mm
    double-ring through-hole PGA, 2.54mm grid, ~6 GND holes, NO castellated
    edges -- header-mount only, cannot be reflowed as SMD (unlike the Pico).
    Holes are silk-labelled by signal name with no canonical numbering, so
    the symbol's pin numbers are project-defined and the layout footprint
    must be authored to match; the standing "confirm PGA numbering" flag is
    resolved on that basis. Photos confirm HSTX=GP12-19 and PSRAM CS=GP47 as
    the design assumes. gensym/parts/sourcing/open-questions notes updated;
    Pico SMD-mount option (JLC C7203002) recorded but not adop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
    [gensym.py, parts.py]
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2026-07-11 Design review 2026-07-11: rail protection, decoupling, wiring fixes
    Protection:
    - Sidecar +5V now feeds through a 2A polyfuse into +5V_ISA with an
    SMBJ5.0A clamp + 22uF bulk (a faulted ISA card trips its own fuse
    instead of dropping the board; back-fed voltage is clamped).
    - USB-C VBUS enters through a 3A polyfuse with an SMBJ5.0A on +5V
    (backstop for the CFG1 9-20V failure mode). CH224K gains a 1uF VDD
    cap; its PG routes to Supervisor GPIO16 as PD_PG. Buck output
    doubled to 2x22uF, 10uF at VIN, extra rail bulk.
    - Supervisor USB-A host port: 27R series termination (RP2040
    requirement), USBLC6-2SC6 ESD array, 100uF VBUS bulk.
    - Video: HDMI +5V fused (500mA), HPD sensed on GPIO41,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
    [audio.kicad_sch, bus_mcu.kicad_sch, card_com.kicad_sch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]
2026-07-11 COM/LPT: on-board enable jumpers + base-addr/IRQ straps
    The motherboard's COM1/COM2 IRQs were hard-wired at build time (INSTANCES
    net remap); the LPT port had no strap or disable at all. Both sheets now
    carry the full jumper set a real card would have, so an on-board port can
    be disabled or re-strapped to make room for the same peripheral on the
    sidecar chain:
    - com_port: JP3 enable gates the 16550's spare active-high CS1 (open =
    never selected; IRQ needs no gating since MCR resets to 0 -> OUT2# high
    -> '125 released). JP2 picks IRQ4/IRQ3 (open = polled) on the sheet, so
    the sheet now exports IRQ3+IRQ4 and the INSTANCES remap is gone -- both
    instances share the lines safely (tri-sta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
    [audio.kicad_sch, com_port.kicad_sch, mini-xt.kicad_sch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]
2026-07-11 Remove standalone COM/LPT/RTC dev cards
    With enable + base-addr/IRQ straps on the motherboard instances (previous
    commit), the separate card_com/card_lpt/card_rtc PCBs no longer earn their
    fab cost: the on-board ports are jumper-configurable like the cards were,
    and a sidecar-chain replacement just needs the on-board port disabled or
    re-strapped. Deleted the three wrappers and their generated projects;
    CARD_SHEETS keeps video, storage, and the isatest jig (the boards that
    still need separate PCBs). README's sub-board section reframed: the three
    peripherals are documented under the motherboard with their jumper sets.
    A card wrapper is ~25 lines (see card_video.py), so any of these is
    triviall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
    [card_com.kicad_sch, card_lpt.kicad_sch, card_rtc.kicad_sch]
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2026-07-11 Storage/video: enable + base-address straps
    Completes the jumper story started with COM/LPT: every on-board peripheral
    can now be disabled or re-strapped to make room for the same card on the
    sidecar chain.
    - storage: JP1 base 0x300/0x320 (differ only in A5; A5_SEL replaces nA5 in
    the HI_MATCH tree, XTIDE UB supports both) and JP2 enable on DEC1's spare
    ~E1 (open kills /CS0 + /ODD_SEL, so DEC2/DEC3, both high-byte latches and
    the low-byte '245 go inert; INTRQ's pull-down keeps IRQ5 released). Same
    pattern as the LPT sheet.
    - video: firmware-read boot straps -- this snoop card decodes in firmware,
    so there is no hardware chip-select to gate. JP1/VID_EN (GPIO42, 10k to
    3V3_VID) op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
    [card_storage.kicad_sch, card_video.kicad_sch, storage.kicad_sch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]
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2026-07-12 Design-review fixes: reset parking, IRQ8 off the header, analog cleanups
    Netlist-wide review sweep. IRQ8 leaves the 60-pin ISA header (pin 15 is a
    second GND return; the on-board RTC owns IRQ8 exclusively, so its push-pull
    drive is now correct by construction). Bus MCU Hi-Z parking completed:
    ~CPURESET pulled low (V20 held in reset while the MCU is unprogrammed),
    ~DACK1/~REFRESH parked deasserted, DRQ1 idled low. Supervisor 12 MHz crystal
    damping R actually in series now (was parallel-to-nothing), plus a second
    USBLC6 so both prog-port SW2 positions are ESD-protected. Audio: 0.5x PG
    summing (MCP6002 headroom), 100k LINE bleed, unit B parked as a follower --
    and the SUM stub moved off pin 5's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
    [audio.kicad_sch, bus_mcu.kicad_sch, card_isatest.kicad_sch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]
2026-07-12 ERC cleanup: NC flags on unused pins, anchored interface labels
    KiCad 10 ERC drops from 366 to 16 violations, all noise:
    - NC flags on the 36 genuinely unused pins (cpu_core '138/'161 spares,
    Supervisor RP2040 unused GPIO, Core2350B GPIO44-47, rtc '138 spares).
    - emit_interface anchors every hier label on a stub wire ending in a
    same-name local label -- connectivity unchanged (still by name;
    netlist spans verified), but nothing dangles.
    - Interface honesty: cpu_core drops AEN/IOCHRDY from PINS (both live on
    bus_mcu; nothing here touched them), bus_mcu drops PRIV_COUNTER (the
    counter chain is on-sheet, CNT_* never crosses).
    - Remaining 6 label_dangling are root IRQ9-13/15: single-s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
    [audio.kicad_sch, bus_mcu.kicad_sch, card_video.kicad_sch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]
2026-07-12 ERC power cleanup: single flag owner, flags on series-fed rails
    Full-build ERC is now just the 6 expected IRQ9-13/15 label_dangling.
    - Root's duplicate PWR_FLAGs removed from build.py: power.py #FLG1-3
    own +5V/+3V3/GND; the pair made flag-vs-flag pin_to_pin errors.
    - PWR_FLAGs added on the local rails ERC can't see through a series
    part: VBUS_MCU / VBUS_VID (Schottky diode-OR), VBUS_KBD / HDMI_5V
    (polyfuse), CH224_VDD (1k per WCH ref), AVDD_PGUS / AGND_PGUS
    (ferrite beads).
    Net membership verified unchanged: 821 nets, node-identical to HEAD.
    [bus_mcu.kicad_sch, card_video.kicad_sch, mini-xt.kicad_sch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]
2026-07-12 IRQ rework: single-'165 collector, hardwired COM/LPT IRQs
    - IRQ collector shrunk to one 74HCT165: D0-D6 = IRQ2-8, D7 = IRQ14
    (replacing the source-less IRQ9). U19 + pull-downs R19-R24 + C18
    deleted; IRQ9-13/15 dropped everywhere (nothing on the board or the
    8-bit header can drive them). Firmware shifts 8 bits, Q7-first.
    - COM/LPT IRQ straps deleted, hardwired to the PC conventions:
    COM1=IRQ4, COM2=IRQ3 (COM_IRQ per-instance netmap remap -- first use
    of the INSTANCES netmap), LPT=IRQ7 (U13 '125 drives the net
    directly). The enable jumpers (COM JP3, LPT JP2) free an IRQ by
    disabling the port; the tri-state drivers go silent with it.
    - Storage JP3 (IRQ14/IRQ5) kept: both positions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
    [audio.kicad_sch, bus_mcu.kicad_sch, com_port.kicad_sch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]
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2026-07-12 Build: register network sheet; parts.py NIC bindings
    Wire the RTL8019AS NIC sheet (Task 2) into build.py's SHEETS list and
    bind its five new parts (RTL8019AS, AT93C46, 13F-39MNL, RJ45_LED, 20MHz
    crystal) plus five newly-needed passive values (27k/1M/200 resistors,
    20pF/1nF caps) in parts.py. Full rebuild: root + 13 sheets, 0 structural
    ERC violations (1 expected pin_to_pin on the IOCHRDY wired-AND, matching
    CLAUDE.md's ignorable categories). IRQ2 and IOCHRDY nets confirmed to
    span network + the other soft cards in the regenerated netlist.
    [mini-xt.kicad_sch, network.kicad_sch]
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2026-07-13 Parts: footprints for all components, close 6 LCSC map gaps, check_parts.py
    - mxsch.py emits the Footprint property from component props (was
    hard-coded empty); parts.py entries now carry a verified KiCad
    footprint, applied at build time alongside the LCSC number.
    - Map keys fixed to match placed values: USB_PROG, SS34, LED (PicoGUS),
    APS6404L, CB3T3257/45 -- every combo across all sheets + cards now
    resolves (130 combos, 455 netlist components, all with footprints).
    - Package corrections from JLC DB re-check: RTL8019AS is QFP-100 14x20
    P0.65 (not TQFP); C2897411 female header is a 2x10 strip -- fine for
    Core2350B, Pico needs 2x 1x20 (noted in jlcpcb-sourcing.md).
    - 10 mini-xt:*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
    [audio.kicad_sch, bus_mcu.kicad_sch, card_isatest.kicad_sch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]
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2026-07-13 Symbols+parts: IS62WV51216, TL16C550CPT, I2C RTC; 3.3V LVC/HC rebinds
    New flat mini-xt: symbols (gensym.py), pins verified against
    jlc_get_pinout + datasheet (PCF8563 caught a jlc_get_pinout numbering bug):
    IS62WV51216 (512Kx16 SRAM, TSOP-44), TL16C550PT (TL16C550C UART, LQFP-48,
    NO.PT numbering -- distinct from the old DIP-40 16550 symbol), PCF8563
    (I2C RTC, SO-8).
    parts.py: bind the three new parts (SRAM in stock at JLC; TL16C550CPT
    sourced elsewhere like the V20, 0 JLC stock; PCF8563 + CR2032 holder on
    Device:Battery_Cell); rebind the clock dividers to 74LVC74A/74LVC161
    (check 7: HC/HCT both fail fmax margin at 3.3V/14.318MHz); add LVC-grade
    binds for 5V-tolerant-input octal parts (74LVC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
    [com_port.kicad_sch, cpu_core.kicad_sch, rtc.kicad_sch]
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2026-07-13 cpu_core: re-buffer BALE/CLK/OSC at 3.3V (review fix)
    Review of f6d0d34 found three ISA bus nets driven at 5V (unsafe: they reach
    the non-5V-tolerant sidecar RP2040). Added U15 74LVC125A @ +3V3 to re-buffer
    BALE (from raw V20 ALE), CLK (from CLK7), and OSC (from OSC_3V3); dividers now
    clock off OSC_3V3 directly. U13 74HCT04 keeps only its private CPUCLK gate.
    [cpu_core.kicad_sch]
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2026-07-13 video/picogus/audio: MCUs direct on 3.3V bus, shifters deleted
    video.py: deleted U6 (control snoop) and U7 (IOCHRDY driver) -- pure
    fixed-direction 74LVC245A buffers with nothing left to do once the ISA
    bus is 3.3V-native. GPIO8-11/20/21/38/39 now label directly onto
    ~{MEMR}/~{MEMW}/~{IOR}/~{IOW}/BALE/AEN/CLK/RESET_DRV; GPIO27 drives
    IOCHRDY directly (native tri-state); GPIO40 freed. Kept U2-U5: they are
    a GPIO-budget time-division mux sharing one 8-bit snoop bus across
    D0-7/A0-19, not a voltage bridge -- deleting them would need 28 GPIO
    this 48-pin part doesn't have (questions-video.md #10).
    picogus.py: deleted U6 (CB3T3245) -- pure fixed-direction buffering
    for A8/A9/TC/IRQ5/DRQ with no m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
    [picogus.kicad_sch, video.kicad_sch]
2026-07-13 picogus: key RP2040 gpio_map by GPIO name (was package-pin digits)
    Re-key gpio_map by the RP2040 symbol's GPIO pin NAMES ("GPIO20", ...)
    instead of bare package-pin digit strings ("31", ...). NOT a wiring
    change: the reported "signals wired to the wrong GPIO pad" defect was a
    misread. sch.net() resolves a pin ref by name-or-number, and no pin is
    *named* a bare digit, so "31" fell through to package pin 31 = GPIO20 --
    which is exactly the GPIO the PicoGUS chip-down reference assigns to TC.
    All 30 keys were correct package pins; verified pin-for-pin against
    docs/PicoGUS-chipdown-schematic.pdf and the netlist.
    Connectivity is byte-identical: regenerated picogus.kicad_sch and the
    netlist did no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
    [picogus.py]
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2026-07-13 network: isolate RTL8019AS 5V data bus behind gated LVC245 (review fix)
    The RTL8019AS (U1) is a 5V-only part; its SD0-7 pins were wired directly to
    the shared 3.3V bus D0-7, driving 5V TTL onto nets that reach the non-5V-
    tolerant RP2040/PicoGUS during NIC I/O reads. Insert U4 (74LVC245A @ +3V3)
    between U1's SD pins (now SD0_NIC..SD7_NIC) and D0-7: DIR = ~{IOR}, ~OE =
    ~{NIC_SEL}. The RTL8019AS decodes its 0x340 window internally and exposes no
    select pin, so add U5 (74HC138) to reproduce that decode for the buffer
    enable: ~Y5 low <=> A9.A8.~A7.A6.~A5.~AEN_CHIP, so U4 is Hi-Z on both sides
    unless the NIC is the addressed target (no contention on other cards' reads;
    full bus release when JP1 o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
    [network.kicad_sch]
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2026-07-13 sidecar: isolation/buffer bank -- 5V-compatible ISA expansion port
    Rewrite the sidecar from a passive 60-pin pass-through into the 3.3V board's
    only real-ISA attachment point: an LVC buffer bank (5V-tolerant inputs,
    3.3V-TTL outputs) between the internal bus and an external ISA header whose
    bus-side nets are port-local (X_*, via isa_conn remap).
    - Outbound: 3x 74LVC245A (A0-19 + BALE/AEN/CLK/OSC, DIR strapped outbound) +
    2x 74LVC244A (MEMR/MEMW/IOR/IOW, RESET_DRV, TC, DACK1-3, REFRESH).
    - Data: 1x 74LVC245A, DIR = EXP_DDIR, R1 pulls it outbound-safe at power-on
    (DIR=H => A->B; truth table in comment). ~OE tied enabled.
    - Inbound: X_IRQ2-7/X_DRQ1-3 -> EXT_* via 2x 74LVC244A, 100k pull-do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
    [card_video.kicad_sch, mini-xt.kicad_sch, network.kicad_sch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]
2026-07-13 Parts: remove dead DS12C887 symbol from gensym.py
    Task 10 cleanup: gensym.py still emitted the DS12C887 symbol after the
    3.3V redesign deleted the rtc sheet and its RTC-emulation replacement.
    No sheet ever placed mini-xt:DS12C887 after that point (grep-verified),
    so drop the symbol definition and its slot in the emitted library and
    regenerate mini-xt.kicad_sym. Full rebuild confirms zero connectivity
    change (same 44 expected ERC violations, netlist byte-identical besides
    the build timestamp).
    [gensym.py]
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2026-07-13 3.3V redesign: final-review fix wave (6 findings)
    Reviewer-verified fixes, all at the generator level + regenerated outputs:
    1. (Critical) bus_mcu U17 '04 @+3V3 had the V20's 5V HLDA on its input ->
    value-override to 74LVC04A (5V-tolerant input; parts.py binds C282341).
    2. network R7 (AEN_CHIP park) +5V -> +3V3: it also feeds U5's '138 @+3V3;
    RTL8019AS AEN is 5V-TTL so 3.3V still reads high.
    3. sidecar buf244(): tie unused '244 A inputs to GND, no_connect the Y
    outputs (U1105: 6 spare, U1108: 7) -- no floating always-enabled inputs.
    4. MAX3241s (both com_port instances) +5V -> +3V3; charge-pump caps to the
    datasheet 3.0-3.6V column (all 0.1uF). Removes the 5V-R*OUT-into-3.3V-UAR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
    [bus_mcu.kicad_sch, com_port.kicad_sch, cpu_core.kicad_sch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]
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2026-07-14 addr_decode: hardwire LPT/IDE bases; centralize NIC + video disables (JP1-JP6)
    LPT fixed at 0x378, IDE at 0x300 -- both base straps and their pull-ups
    deleted ('138 ~Y1 now NC, the '00's ~A5 gate spare, IDE OR-leg takes raw
    A5). The NIC and video disable jumpers move to addr_decode as JP5/JP6
    with the same fit-to-disable sense as the rest: their gating hardware
    stays local (the NIC's isolation '125 inside the 5V island, video's
    firmware boot strap on GPIO42), only the jumper levels cross as
    mxbus.PRIV_DIS -- video's documented firmware polarity inverts (high =
    disabled; no firmware exists yet). Disable row is now a uniform JP1-JP6
    (COM1/COM2/LPT/IDE/NIC/VID), bare board runs everything; netw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
    [addr_decode.kicad_sch, audio.kicad_sch, card_video.kicad_sch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]
2026-07-14 picogus: U8/U9 74LVC00 -> 74HC00 (basic part; LVC was a 5V-reference fossil)
    The LVC grade came from polpo's 5V-ISA reference design; this island has
    been all-3.3V since the redesign, so every input is 3.3V-driven and plain
    HC is in spec. 74HC00 (C699445) is a basic-library line already shared
    with parallel/addr_decode; the orphaned 74LVC00 parts.py entry -- the
    board's thinnest BOM line (~125 units) -- is deleted.
    [picogus.kicad_sch]
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2026-07-14 parallel: fold U11's lone OR gate into U12's spare NANDs
    U11 (74HC32) survived the decode centralization carrying one gate,
    ~{RD_CTRL} = ~{SEL_CTRL} | ~{IOR}. Rebuilt as OR-from-NAND on U12's
    three spares (two input inverters + one combine); the ~25ns of added
    gate delay is noise in an ~840ns ISA read cycle. U12 now 4/4 used,
    LPT sheet down to 9 ICs; board 452 comps / 91 ICs.
    [parallel.kicad_sch]
2026-07-14 Passives: basic-library audit + 4x resistor-array pull consolidation
    Audit: every discrete R/C value was already JLC basic except the ferrite
    beads -- swapped to basic Murata BLM18PG121SN1D (C14709, 120R@100MHz,
    same family/role). The 100uF electrolytic and buck inductor stay
    extended (zero fee-free parts exist in those subcategories). Pruned the
    orphaned 5V-era 47nF/330nF MAX3241 cap entries.
    Pull consolidation: 65 discrete 10k/4.7k rail pulls across 8 sheets
    collapse into 18 basic 4-element isolated arrays (4D03WGJ0103T5E /
    4D03WGJ0472T5E, element k = pins k/9-k; new mxbus.r_pack4 helper).
    Isolated elements let packs mix rails; every net keeps its exact rail
    and semantics (verified elemen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
    [addr_decode.kicad_sch, bus_mcu.kicad_sch, card_video.kicad_sch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]
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
